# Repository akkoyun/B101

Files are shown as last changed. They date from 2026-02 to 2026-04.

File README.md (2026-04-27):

# B101BA-PCIe

**B101BA-PCIe** is a Mini PCI Express form-factor cellular modem card based on the **Telit LE910C1-EUX** 4G modem. This repository contains all Altium Designer project files, schematics, PCB layout, and generated outputs for review, manufacturing, and further development.

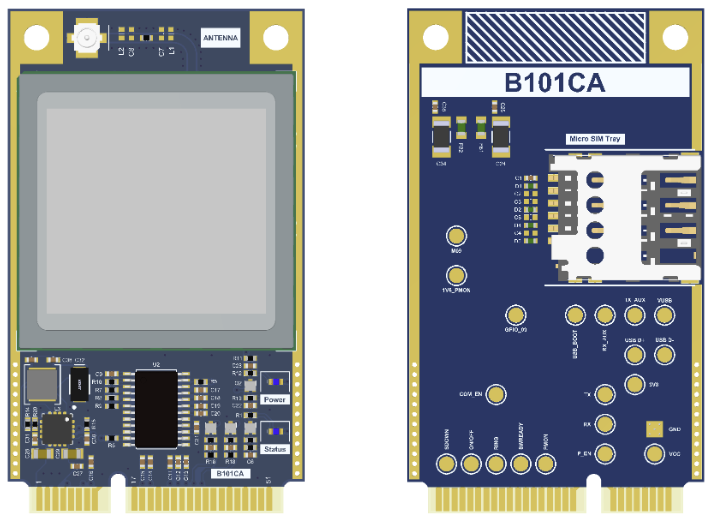
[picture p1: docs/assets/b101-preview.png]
B101BA-PCIe Board Preview


## Features

- Telit LE910C1-EUX LTE modem
- Mini PCIe edge connector (host interface)
- Dedicated 3.8V modem power rail (TPS62130)
- 1.8V ↔ 3.3V level translation (SN74AXC8T245)
- SIM card interface
- Cellular RF matching and antenna connection (IPEX/MHF)
- Exposed UART, USB, I2C, SPI, GPIO, analog pins
- Modem control signals: ON/OFF, shutdown, PWRMON, SWREADY, RING

## Block Diagram

- **Modem Core:** LE910C1-EUX, separated by function (power, UART, USB, GNSS, etc.)
- **Host Interface:** 52-pin Mini PCIe, multiple power/data/control lines
- **Power Supply:** 3.8V buck regulator, bulk capacitance for LTE current bursts
- **Voltage Translation:** Safe bridging between 1.8V (modem) and 3.3V (host)
- **Control Logic:** Discrete transistor-based ON/OFF and shutdown
- **RF Section:** Matching, controlled impedance, IPEX/MHF connector

## Repository Structure

| Path | Purpose |
|---|---|
| `B101BA.PrjPcb` | Main Altium project file |
| `B101BA.PcbDoc` | PCB layout document |
| `Schematics/` | Schematic source files |
| `B101BA.BomDoc` | Bill of materials document |
| `Job File.OutJob` | Output/fabrication generation settings  |
| `Output/` | Generated outputs (prints, manufacturing)|
| `History/` | Altium history/revision artifacts |
| `B101BA.PCBDwf` | PCB documentation/export artifact |

## Schematic Pages

- GSM IoT Block Diagram
- Card Edge Connector
- 3V8 Power Regulator
- Voltage Translator
- Control Signals
- GSM Antenna & Match Circuit
- Unused Modem Pins

## Typical Applications

- IoT gateways
- Industrial controllers
- Telemetry units
- Remote monitoring systems
- Any host system needing modular LTE connectivity

## Tooling

- Altium Designer (project editing)
- Gerber/CAM viewer (output review)
- PDF viewer (schematic prints)

## Version History

| Version | Date | Description |
|---|---|---|
| 00.00.01  | 2026-02-18 | Initial draft, basic schematic and PCB |
| 00.00.02  | 2026-02-26 | Design revision, bug fixes, DRC updates |
| 00.00.03  | 2026-04-23 | Post Design Review 01 updates, output refreshed  |

## Design Reviews & Documentation

- **Design Review 01:** Held on 2026-04-23. See `docs/Design Review 01/` for reviewed files and notes:
  - [BOM and review notes](docs/Design%20Review%2001/B101BA_00.00.01_BOM.csv)
  - [Design review presentation](docs/Design%20Review%2001/Telit%20Design%20Review%2001%20(Schematic%20%26%20PCB).pages)
- All manufacturing and review outputs: see `Output/` directory.

---

## Project Page

<https://www.akkoyun.net/acik-kaynak/B101BA-PCIe>

## License

A repository-level license file is not currently visible. If this project is intended to be openly reusable, please add a `LICENSE` file.

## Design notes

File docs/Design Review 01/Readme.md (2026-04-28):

# B100 / B101BA Modem Kartı Design Review Değerlendirme Raporu

**Doküman:** Telit Cinterion Design Review Report  
**Rapor No:** DR-35567 Rev 1  
**Tarih:** 2026-04-08  
**Modem:** Telit-Cinterion LE910C1-EUX  
**İncelenen Tasarım:** B101BA_00.00.01  
**Hazırlayan:** Mehmet Günce Akkoyun için teknik değerlendirme notu

---

## 1. Yönetici Özeti

Telit tarafından yapılan design review sonucunda kart genel olarak çalışabilir görünse de, özellikle **modem footprint hatası**, **reserved pin bağlantıları**, **seviye çevirici besleme tercihi**, **güç kesintisinde modem güvenli kapatma mekanizması** ve **yüksek manyetik alan ortamında bobin seçimi** konularında revizyon ihtiyacı vardır.

En kritik konu PCB layout tarafındadır: Telit, **modem footprint’inin yanlış olduğunu** belirtmiştir. Bu doğrudan üretilebilirlik, lehimleme güvenilirliği, modem oturumu ve uzun dönem saha güvenilirliği açısından **kritik hata** olarak ele alınmalıdır.

İkinci kritik konu, **K4 ve M6 pinlerinin reserved olması ve bağlanmaması gerektiğidir**. Bu pinlerin devrede herhangi bir nete bağlı olması ileride modem davranışı, sertifikasyon veya yeni modem revizyonları açısından risk oluşturabilir.

Üçüncü önemli konu ise **voltaj çevirici VCCB hattında VIO_1V8 yerine VAUX/PWRMON kullanılması önerisidir**. Telit bunu latch-up riskini azaltmak için önermiştir.

Bu rapora göre B100/B101BA modem kartı için revizyon yapılmadan seri üretime geçilmemelidir.

---

## 2. Telit Review Sonuç Özeti

| İnceleme Alanı | Durum | Yorum |
|---|---:|---|
| Power Supply | Warning + Tip | L3 bobini shielded olmalı, fast shutdown öneriliyor |
| SIM Pins | OK | SIM bağlantılarında problem görülmemiş |
| Digital Pins | Error + Warning | Reserved pin bağlantıları ve seviye çevirici besleme riski var |
| RF Aspects - Schematic | Warning | 33 pF RF/harmonik filtreleme kapasitörleri öneriliyor |
| Audio | N/A | Kullanılmıyor |
| PCB General Placement | Error | Modem footprint yanlış |
| Antenna Waveguide | OK | RF hattı 50 Ohm karakteristik empedansa uygun |
| RF Layout | OK | RF waveguide hesaplaması uygun |
| Audio Layout | N/A | Kullanılmıyor |

---

## 3. Kritik Bulgular

## 3.1 Modem Footprint Hatalı

**Seviye:** Kritik / Error  
**Alan:** PCB Layout  
**Telit yorumu:** Modemin footprint’i yanlış, doğru footprint şekli raporda verilmiş.

### Risk

Bu madde tasarımdaki en ciddi bulgudur. Footprint hatası aşağıdaki problemlere yol açabilir:

- Modemin PCB üzerine mekanik olarak hatalı oturması
- Pad hizalama problemleri
- Lehim köprüsü veya açık devre riski
- Reflow sonrası gizli lehim hataları
- Sahada titreşim/ısı döngüsü sonrası bağlantı kopmaları
- Üretim veriminin düşmesi
- Modem üretici tavsiyesine uyumsuzluk nedeniyle sertifikasyon veya onay sürecinde sorun

### Yapılacak İşlem

- Telit’in verdiği footprint çizimi referans alınarak mevcut footprint yeniden kontrol edilmeli.
- Library footprint’i güncellenmeli.
- Pad ölçüleri, keep-out/inhibit wiring bölgeleri, package outline ve mekanik hizalama tekrar çizilmeli.
- Güncellenmiş footprint ile PCB tekrar route edilmeli.
- Eski footprint kullanılan tüm projeler kontrol edilmeli.

### Öncelik

**P0 - Üretim öncesi mutlaka düzeltilmeli.**

---

## 3.2 K4 ve M6 Reserved Pinleri Bağlı Olmamalı

**Seviye:** Kritik / Error  
**Alan:** Schematic / Digital Pins  
**Telit yorumu:** K4 ve M6 pinleri reserved olup bağlanmamalıdır.

### Risk

Reserved pinlerin bağlanması şu riskleri doğurur:

- Modem iç yapısında bilinmeyen fonksiyonlara müdahale
- Farklı modem donanım revizyonlarında uyumsuzluk
- Sertifikasyon sırasında üretici tavsiyesine aykırı bağlantı
- Uyku/uyanma, boot, RF veya debug davranışlarında öngörülemeyen sorunlar
- Saha koşullarında rastgele modem kilitlenmesi veya kararsızlık

### Yapılacak İşlem

- K4 ve M6 pinleri şemada **NC** bırakılmalı.
- Bu pinlere bağlı net, test point, pull-up, pull-down veya başka bağlantı varsa kaldırılmalı.
- PCB üzerinde bu pinlerden çıkan izler silinmeli.
- ERC/DRC için bu pinler “Do Not Connect” olarak işaretlenmeli.

### Öncelik

**P0 - Mutlaka düzeltilmeli.**

---

## 3.3 Voltage Translator VCCB Hattında VIO_1V8 Yerine VAUX/PWRMON Kullanılmalı

**Seviye:** Warning  
**Alan:** Schematic / Communication Interfaces  
**Telit yorumu:** Module latch-up riskini önlemek için voltage translator’ın VCCB hattında VIO_1V8 yerine VAUX/PWRMON kullanılmalı.

### Teknik Değerlendirme

Bu uyarı önemlidir. Modem ile MCU veya başka dijital devreler arasında seviye çevirici kullanılıyorsa, modem kapalıyken veya power state geçişindeyken IO hatlarından modeme ters besleme gitmesi latch-up riskini artırabilir.

VAUX/PWRMON kullanımı, modem IO domain aktif olduğunda seviye çeviricinin de aktif olmasını sağlar. Böylece modem kapalıyken dış dünyadan IO pinleri üzerinden modem içine kaçak besleme verilmesi engellenir.

### Risk

- Modem latch-up
- Boot sırasında kararsız davranış
- Modem kapanmış görünürken IO üzerinden kısmi beslenme
- Akım tüketiminde anormal artış
- Modem reset ihtiyacı
- Uzun vadede modem hasarı

### Yapılacak İşlem

- Voltage translator VCCB hattı mevcutta VIO_1V8’e bağlıysa bağlantı revize edilmeli.
- VCCB, Telit önerisine uygun şekilde VAUX/PWRMON sinyalinden beslenmeli.
- Translator yön kontrolü, enable pini ve pull-up/pull-down yapısı tekrar kontrol edilmeli.
- Modem kapalıyken MCU tarafının modem IO hattına enerji basmadığı doğrulanmalı.
- Güç sıralaması test edilmeli.

### Test Önerisi

- Modem kapalı, MCU açık senaryosu
- MCU kapalı, modem açık senaryosu
- Her ikisi aynı anda açılıyor senaryosu
- Ani güç kesintisi sonrası tekrar açılma senaryosu
- Sleep/wakeup senaryosu

### Öncelik

**P1 - Revizyon kartında düzeltilmeli.**

---

## 3.4 L3 Bobini Shielded Tip ile Değiştirilmeli

**Seviye:** Warning  
**Alan:** Power Supply  
**Telit yorumu:** Uygulama yüksek manyetik alana yakın çalışacağı için L3 bobini shielded tip ile değiştirilmelidir.

### Teknik Değerlendirme

Kartın motor kontrol panosu, kontaktör, sürücü, soft starter, kompanzasyon ve yüksek akım hatlarına yakın çalışacağı düşünülürse bu uyarı doğru ve önemlidir. Açık tip bobinler harici manyetik alanlardan etkilenebilir, aynı zamanda kendileri de çevreye daha fazla EMI yayabilir.

Shielded indüktör kullanmak özellikle modem besleme hattında daha stabil davranış sağlar.

### Alternatif Shielded İndüktör Önerileri

    Not: L3 için kesin değer mevcut şemadaki regülatör topolojisine, switching frekansına, hedef çıkış akımına ve mevcut endüktans değerine göre netleştirilmelidir. Aşağıdaki tablo, modem besleme hattında kullanılabilecek **shielded power inductor** alternatiflerini kısa liste olarak verir. Seçim yapılırken mevcut L3 değeriyle aynı endüktans değeri, daha yüksek saturation current ve düşük DCR önceliklendirilmelidir.
 
| Üretici | Seri / Parça Ailesi | Örnek Parça | Paket | Avantaj | Not |
|---|---|---|---|---|---|
| Würth Elektronik | WE-PD / WE-LHMI | 7447709xxx / 744373xxxx | SMD shielded | Kolay bulunur, güçlü datasheet, endüstriyel kullanım için güvenilir | Avrupa tedarik zinciri ve prototip için iyi seçenek |
| Coilcraft | XAL / XFL / MSS | XAL40xx / XFL40xx / MSSxxxx | SMD shielded | Düşük DCR, yüksek saturation current, kaliteli manyetik yapı | Performans odaklı seçim için iyi ama maliyet daha yüksek olabilir |
| Bourns | SRN / SRP | SRN6045 / SRP5030 / SRP7030 | SMD semi-shielded / shielded | Yaygın bulunabilir, maliyet/performans dengesi iyi | SRP serisi daha güçlü shielded yapı için tercih edilebilir |
| TDK | SPM / VLS | SPM5030 / VLS6045 | SMD shielded | Kompakt, kaliteli, otomotiv/endüstriyel seçenekleri var | Stok ve fiyat kontrolü gerekli |
| Murata | LQH / DFE | DFE252012 / DFE322512 / LQHxx | SMD shielded | Kompakt tasarım, güvenilir marka | Yüksek akım gerekiyorsa paket boyutu dikkatli seçilmeli |
| Taiyo Yuden | NR / NRS | NR6045 / NRS6045 | SMD shielded | Uygun maliyetli, yaygın Asya tedariki | Seri üretim maliyeti için değerlendirilebilir |
| Sunlord | SWPA / WPN | SWPA6045 / SWPA7030 | SMD shielded | Çin tedarikinde ekonomik alternatif | Uzun dönem kalite ve sıcaklık performansı ayrıca doğrulanmalı |
| Chilisin / Yageo | SCDS / SLF / çeşitli power serileri | Değere göre seçilmeli | SMD shielded | Ekonomik ve bulunabilir alternatifler | Datasheet parametreleri dikkatli karşılaştırılmalı |

#### Seçim Kriterleri

- Mevcut L3 ile **aynı endüktans değeri** korunmalı.
- Saturation current değeri, modem TX burst ve regülatör peak current ihtiyacının üzerinde olmalı.
- RMS current değeri sürekli çalışma akımını güvenli karşılamalı.
- DCR düşük olmalı; aksi halde ısınma ve verim kaybı artar.
- Shielded yapı tercih edilmeli; semi-shielded parça ancak yer/maliyet zorunluluğu varsa düşünülmeli.
- Çalışma sıcaklığı en az **-40 °C / +85 °C**, tercihen **+105 °C** veya üzeri olmalı.
- Aynı footprint içinde ikinci kaynak alternatifi belirlenmeli.
- Prototipte modem TX anında bobin sıcaklığı, çıkış ripple ve voltaj çökmesi ölçülmeli.

#### Öncelikli Kısa Liste

| Öncelik | Öneri | Gerekçe |
|---:|---|---|
| 1 | Würth Elektronik WE-PD / WE-LHMI | Dokümantasyon, erişilebilirlik ve endüstriyel güvenilirlik açısından güçlü seçenek |
| 2 | Coilcraft XAL / XFL | Elektriksel performans ve düşük kayıp açısından güçlü seçenek |
| 3 | Bourns SRP serisi | Maliyet/performans dengesi iyi, yaygın bulunabilir |
| 4 | TDK SPM serisi | Kompakt ve kaliteli alternatif |
| 5 | Taiyo Yuden NR/NRS veya Sunlord SWPA | Seri üretimde maliyet optimizasyonu için değerlendirilebilir |

### Risk

- Bobin saturasyonu
- Regülatör çıkışında ripple artışı
- Modem TX burst sırasında voltaj çökmesi
- EMI/EMC problemleri
- RF performansında düşüş
- Saha koşullarında rastgele modem resetleri

### Yapılacak İşlem

- L3 mevcut parça numarası kontrol edilmeli.
- Aynı endüktans değerinde, uygun saturation current değerine sahip shielded indüktör seçilmeli.
- RMS current, saturation current, DCR ve sıcaklık yükselmesi kontrol edilmeli.
- Modem TX burst sırasında besleme hattı osiloskop ile izlenmeli.
- EMI açısından yakın alan probu ile karşılaştırmalı test yapılmalı.

### Öncelik

**P1 - Saha güvenilirliği için düzeltilmeli.**

---

## 3.5 Fast Shutdown Özelliği Eklenmeli

**Seviye:** Tip / Strong Recommendation  
**Alan:** Power Supply  
**Telit yorumu:** Ani güç kesintisi ihtimali olan sistemlerde modem memory corruption riskini önlemek için fast-shutdown özelliği uygulanmalı.

### Teknik Değerlendirme

Bu cihaz saha koşullarında motor panosunda çalışacağı için ani enerji kesintisi, kontaktör kaynaklı düşümler, pano içi bakım sırasında kapatma veya akü/hat dalgalanması gibi durumlar beklenebilir.

Modemin dosya sistemi, NVM alanı veya internal memory yapısı ani enerji kesintilerinden etkilenebilir. Bu nedenle fast shutdown mekanizması özellikle endüstriyel IoT uygulamalarında ihmal edilmemelidir.

### Risk

- Modem memory corruption
- SIM/network registration problemleri
- Modem boot loop
- FOTA veya konfigürasyon verisi bozulması
- Sahada cihazın bağlantısız kalması

### Yapılacak İşlem

- Telit LE910C1-EUX Hardware User Guide içindeki FAST_SHUTDOWN bölümü incelenmeli.
- Modem ON/OFF, RESET, PWRMON ve fast shutdown ilişkisi netleştirilmeli.
- Ana besleme düşüşü algılanacaksa MCU veya supervisor üzerinden shutdown tetiklenmeli.
- Yeterli hold-up kapasitesi veya batarya/power-path desteği ile modem shutdown süresi garanti edilmeli.
- Firmware tarafında “power fail detected” event’i oluşturulmalı.

### Öncelik

**P1 - Endüstriyel saha ürünü için uygulanması güçlü şekilde önerilir.**

---

## 3.6 RF/Harmonik Filtreleme İçin 33 pF Kapasitör Footprintleri Eklenmeli

**Seviye:** Warning  
**Alan:** RF Aspects / Schematic  
**Telit yorumu:** Harmoniklerden kaçınmak için modem kartında ve yakındaki kartlarda belirli noktalara GND’ye 33 pF kapasitörler konumlandırılması öneriliyor.

### Telit’in Önerdiği Filtreleme Noktaları

- Input/output connector üzerindeki power source ve sinyal hatları
- Power supply output pad’leri
- Komponentlerin power supply input pad’leri
- LED gibi forward conduction çalışan diyotların anot/katot hatları
- Transistor base hatları
- Phototransistor ve opto-isolator giriş/çıkış hatları

### Teknik Değerlendirme

Telit burada doğrudan EMI/RF harmonik bastırma amacıyla küçük değerli COG/NPO kapasitör öneriyor. 33 pF değeri özellikle 0402/0603 paketlerde yaklaşık 1 GHz civarında self-resonance davranışı nedeniyle önerilmiş. 0201 paketlerde ise 10–20 pF değerlerin 1 GHz civarına daha uygun olduğu belirtilmiş.

Burada kritik nokta şu: Bu kapasitörler rastgele her hatta takılmamalı; sinyal bütünlüğü, rise time, UART/SPI/I2C hızları, open-drain yapılar ve sürücü empedansları dikkate alınmalı. Ama PCB üzerinde opsiyonel footprint bırakmak doğru yaklaşımdır.

### Yapılacak İşlem

- Kritik hatlara opsiyonel “DNP” 33 pF COG/NPO kapasitör footprintleri eklenmeli.
- Kapasitörler filtrelenecek component pad’ine çok yakın yerleştirilmeli.
- Aynı path ve aynı layer üzerinde konumlandırılmalı.
- GND dönüş yolu kısa ve düşük empedanslı olmalı.
- High-speed veya timing-critical hatlarda kapasitör değeri testle doğrulanmalı.
- 0402/0603 için 33 pF, 0201 için 10–20 pF opsiyonları değerlendirilmeli.

### Öncelik

**P2 - EMC/sertifikasyon hazırlığı için önerilir.**

---

## 3.7 SIM Hatları Uygun

**Seviye:** OK  
**Alan:** SIM Pins  
**Telit yorumu:** SIM pin bağlantıları uygun.

### Teknik Değerlendirme

Telit SIM tarafında hata belirtmemiştir. Buna rağmen üretim öncesi şu kontroller yapılmalıdır:

- SIM ESD koruması
- SIM hat uzunlukları
- SIM clock hattı yakınındaki agresif sinyaller
- SIM kart soketi mekanik dayanımı
- SIM detect kullanılıyorsa logic seviyesi
- GND referans sürekliliği

### Öncelik

**P3 - Mevcut yapı korunabilir, üretim öncesi rutin kontrol yeterli.**

---

## 3.8 RF Waveguide 50 Ohm Uygun

**Seviye:** OK  
**Alan:** RF Layout  
**Telit yorumu:** RF waveguide required 50 Ohm characteristic impedance değerine uygun.

### Teknik Değerlendirme

RF hattı açısından önemli bir olumlu bulgudur. Telit’in RF waveguide hesaplamasında 50 Ohm empedans uygun görülmüş. Bu nedenle RF hattının genişlik/boşluk/stack-up yapısı korunmalıdır.

### Yapılacak İşlem

- RF hattı revizyon sırasında değiştirilmemeli.
- Footprint düzeltmesi RF hattını etkiliyorsa empedans yeniden hesaplanmalı.
- Üreticiye stack-up net verilmeli.
- RF hattında solder mask, via geçişleri ve ground stitching korunmalı.
- Anten konnektörü çevresindeki GND yapısı bozulmamalı.

### Öncelik

**P3 - Mevcut yapı korunmalı.**

---

# 4. Revizyon İçin Yapılacaklar Listesi

## 4.1 P0 - Kritik / Üretim Öncesi Zorunlu

- [ ] LE910C1-EUX modem footprint’i Telit’in önerdiği footprint’e göre yeniden çizilecek.
- [ ] Mevcut PCB’de modem footprint pad ölçüleri, package outline ve keep-out/inhibit wiring bölgeleri kontrol edilecek.
- [ ] Revize PCB üretime gitmeden önce Telit footprint çizimiyle birebir karşılaştırılacak.

---

## 4.2 P1 - Güvenilirlik İçin Güçlü Revizyon Önerileri

- [ ] Modem kapalıyken MCU tarafından IO hatları üzerinden modeme ters besleme gitmediği doğrulanacak.
- [ ] L3 bobini shielded tip indüktör ile değiştirilecek.
- [ ] Yeni L3 için saturation current, RMS current, DCR ve sıcaklık değerleri kontrol edilecek.
- [ ] Fast shutdown özelliği Telit Hardware User Guide’a göre incelenecek.
- [ ] Ani güç kesintisi senaryosu için modem güvenli kapanma akışı tasarlanacak.
- [ ] Hold-up süresi için bulk capacitor / batarya / power-path yeterliliği hesaplanacak.
- [ ] Power fail algılama ve modem shutdown firmware akışı tasarlanacak.
- [ ] L3 bobini shielded tip indüktör ile değiştirilecek.
- [ ] Yeni L3 için saturation current, RMS current, DCR ve sıcaklık değerleri kontrol edilecek.
- [ ] L3 için Würth, Coilcraft, Bourns, TDK ve ekonomik seri üretim alternatifleri içinden en az iki pin-to-pin uyumlu kaynak belirlenecek.

---

## 4.3 P2 - EMC / Sertifikasyon Hazırlığı

- [ ] Power source giriş/çıkış hatlarına opsiyonel 33 pF COG/NPO kapasitör footprintleri eklenecek.
- [ ] Input/output connector sinyal hatlarına opsiyonel RF filtre kapasitör footprintleri eklenecek.
- [ ] Power supply output pad’lerine yakın 33 pF opsiyonları değerlendirilecek.
- [ ] LED D6 anot/katot hattı için opsiyonel 33 pF filtre footprint’i eklenecek.
- [ ] Transistor base hatlarına opsiyonel 33 pF filtre footprint’i eklenecek.
- [ ] Opto-isolator ve phototransistor hatları varsa opsiyonel filtre footprintleri eklenecek.
- [ ] 0402/0603 için 33 pF, 0201 için 10–20 pF alternatifleri BOM opsiyonuna eklenecek.
- [ ] Bu kapasitörler varsayılan olarak DNP bırakılacak, EMC testine göre takılacak.

---

# 5. Test Planı

## 5.1 Power Testleri

- [ ] Modem TX burst sırasında modem beslemesi osiloskop ile ölçülecek.
- [ ] Ani enerji kesintisi testi yapılacak.
- [ ] Fast shutdown tetiklenme testi yapılacak.
- [ ] Modem açık/kapalı power sequencing testi yapılacak.
- [ ] MCU açık, modem kapalı senaryosunda IO leakage ölçülecek.
- [ ] Modem açık, MCU kapalı senaryosunda IO leakage ölçülecek.

---

## 5.2 Digital Interface Testleri

- [ ] UART/SPI/I2C hangi arayüz kullanılıyorsa logic analyzer ile kontrol edilecek.
- [ ] Voltage translator VCCB değişimi sonrası haberleşme stabilitesi test edilecek.
- [ ] Sleep/wakeup sonrası haberleşme tekrar başlıyor mu kontrol edilecek.
- [ ] Power cycle sonrası modem kararlı boot ediyor mu kontrol edilecek.

---

## 5.3 RF Testleri

- [ ] Anten bağlantısı sonrası RSSI/RSRP/RSRQ/SINR değerleri ölçülecek.
- [ ] RF hattı revizyon sonrası VNA ile mümkünse kontrol edilecek.
- [ ] Yakın alan EMI taraması yapılacak.
- [ ] 33 pF DNP kapasitörlerin EMC testinde etkisi karşılaştırılacak.
- [ ] Modem TX sırasında yakındaki dijital hatlarda parazit gözlemlenecek.

---

## 5.4 Üretim Testleri

- [ ] Modem footprint revizyonundan sonra ilk PCB’de X-ray veya mikroskop kontrolü yapılacak.
- [ ] Reflow sonrası modem pad lehim kalitesi kontrol edilecek.
- [ ] Reserved pinlerin gerçekten bağlantısız olduğu netlist üzerinden doğrulanacak.
- [ ] RF hattı continuity ve short kontrolü yapılacak.
- [ ] SIM kart algılama ve network registration testi yapılacak.

---

# 6. Revizyon Notları

## 6.1 Schematic Revizyon Notları

| Madde | Aksiyon |
|---|---|
| K4 / M6 | NC yapılacak |
| VCCB | VIO_1V8 yerine VAUX/PWRMON |
| Fast shutdown | Telit HUG’a göre eklenecek |
| L3 | Shielded indüktör ile değiştirilecek; Würth / Coilcraft / Bourns / TDK ve seri üretim alternatifi karşılaştırılacak |
| 33 pF filtreler | Kritik hatlara DNP footprint olarak eklenecek |

---

## 6.2 PCB Revizyon Notları

| Madde | Aksiyon |
|---|---|
| Modem footprint | Telit önerisine göre düzeltilecek |
| RF line | 50 Ohm yapı korunacak |
| GND stitching | RF hattında korunacak |
| 33 pF filtreler | Pad’e çok yakın yerleştirilecek |
| Keep-out alanları | Telit footprint’e göre yeniden kontrol edilecek |

---

# 7. Mühendislik Yorumu

Telit’in raporu kısa ama kritik maddeler içeriyor. En önemli nokta, review sonucunda RF hattının 50 Ohm olarak uygun bulunması ve SIM tarafında problem görülmemesidir. Bu iyi haber.

Ancak modem footprint hatası ciddi bir konu. Bu hata düzeltilmeden PCB üretimine devam etmek doğru olmaz. Eğer mevcut karttan prototip üretildiyse, bu kartlar sadece sınırlı fonksiyon testi için kullanılmalı; saha pilotu veya seri üretim adayı olarak değerlendirilmemelidir.

Reserved pinlerin bağlı olması da hafife alınmamalı. Bugün çalışıyor gibi görünse bile modem üreticisi bu pinleri ileride farklı amaçla kullanabilir veya pin iç yapısı revizyonla değişebilir. Endüstriyel sahada çalışacak bir modem kartında bu tür belirsizlik kabul edilmemelidir.

Voltage translator beslemesiyle ilgili öneri de sahada rastgele modem kilitlenmelerini önlemek açısından önemlidir. Bu tarz latch-up problemleri laboratuvarda kolay yakalanmaz; asıl problem sahada, özellikle motor panosu gibi gürültülü ortamlarda ortaya çıkar.

Sonuç olarak bu design review, kartın tamamen kötü olduğunu göstermiyor; fakat seri üretim öncesi mutlaka yapılması gereken birkaç net düzeltme olduğunu gösteriyor.

---

# 8. Kapanış Kararı

Bu kart için önerilen karar:

**Revizyon gerekli. Mevcut tasarım doğrudan seri üretime çıkarılmamalı.**

Revizyon sonrası aşağıdaki üç kontrol tamamlanmadan üretim onayı verilmemelidir:

1. Telit footprint uyumluluk kontrolü
2. Reserved pinlerin tamamen NC doğrulaması
3. Power sequencing / latch-up / fast shutdown testleri

Bu üç madde kapatıldıktan sonra kart, saha pilotu için yeniden değerlendirilebilir.
# B100 / B101BA Modem Kartı Design Review Revizyon Raporu

**Kaynak Doküman:** Telit Cinterion Design Review Report  
**Rapor No:** DR-35567 Rev 1  
**Tarih:** 2026-04-08  
**Modem:** Telit-Cinterion LE910C1-EUX  
**Tasarım:** B101BA_00.00.01  
**Kapsam:** Telit design review bulguları, yapılan düzeltmeler ve açık kalan doğrulama adımları

---

## 1. Yönetici Özeti

Telit tarafından yapılan design review sonucunda B100 / B101BA modem kartı için birkaç kritik düzeltme önerilmiştir. Review’de öne çıkan başlıklar şunlardır:

- Modem footprint’inin Telit önerisiyle uyumlu hale getirilmesi
- K4 ve M6 reserved pinlerinin bağlantısız bırakılması
- Voltage translator beslemesinde VIO_1V8 yerine PWRMON/VAUX kullanılması
- L3 indüktörün shielded/kalkanlı olduğunun netleştirilmesi
- Ani güç kesintisi senaryosu için fast shutdown mekanizmasının değerlendirilmesi
- RF/harmonik bastırma için opsiyonel 33 pF filtre kapasitörlerinin değerlendirilmesi

İlk revizyon çalışması kapsamında kritik donanım maddeleri kapatılmıştır. Kart artık doğrudan “hatalı tasarım” durumundan çıkmış, **revizyon sonrası doğrulama/test aşamasına** geçmiştir.

Seri üretim kararı verilmeden önce güç sıralaması, IO leakage, modem TX burst besleme stabilitesi ve temel RF/EMC davranışı doğrulanmalıdır.

---

## 2. Telit Bulguları ve Yapılan İşlemler

| No | Telit Bulgusu | Öncelik | Yapılan İşlem | Durum |
|---:|---|---|---|---|
| 1 | Modem footprint hatalı | P0 | LE910C1-EUX footprint’i Telit önerisine göre düzeltildi | Tamamlandı |
| 2 | K4 ve M6 pinleri reserved, bağlanmamalı | P0 | K4 ve M6 pinleri NC hale getirildi | Tamamlandı |
| 3 | Voltage translator VCCB hattında VIO_1V8 yerine PWRMON/VAUX kullanılmalı | P1 | 1V8 besleme kaldırılarak PWRMON/VAUX besleme yapıldı | Tamamlandı |
| 4 | L3 yüksek manyetik alan için shielded olmalı | P1 | L3’ün shielded/kalkanlı olduğu şematikte netleştirildi | Tamamlandı |
| 5 | Ani güç kesintisi için fast shutdown öneriliyor | P1 | Donanım/firmware akışı ayrıca değerlendirilecek | Açık |
| 6 | RF/harmonik azaltma için 33 pF filtreler öneriliyor | P2 | Opsiyonel DNP filtre footprintleri değerlendirilecek | Açık / Opsiyonel |
| 7 | SIM pinleri | P3 | Telit tarafından uygun bulundu | OK |
| 8 | RF waveguide 50 Ohm | P3 | Telit tarafından uygun bulundu; yapı korunacak | OK |

---

## 3. Kapatılan Kritik Maddeler

### 3.1 Modem Footprint Düzeltmesi

Telit, PCB layout incelemesinde modem footprint’inin doğru olmadığını belirtmiştir. Bu madde üretilebilirlik, lehim kalitesi ve saha güvenilirliği açısından en kritik bulgudur.

**Yapılan işlem:**

- LE910C1-EUX modem footprint’i Telit önerisine göre güncellendi.
- Pad geometrileri ve mekanik yerleşim kontrol edildi.
- Yeni footprint’e göre PCB yerleşimi revize edildi.

**Durum:** Tamamlandı.

---

### 3.2 Reserved Pin Düzeltmesi

Telit, K4 ve M6 pinlerinin reserved olduğunu ve bağlanmaması gerektiğini belirtmiştir.

**Yapılan işlem:**

- K4 pini NC hale getirildi.
- M6 pini NC hale getirildi.
- Reserved pinlerin sinyal, test point, pull-up veya pull-down bağlantısı olmaması sağlandı.

**Durum:** Tamamlandı.

---

### 3.3 Voltage Translator Besleme Revizyonu

Telit, latch-up riskini azaltmak için voltage translator VCCB hattının VIO_1V8 yerine PWRMON/VAUX ile beslenmesini önermiştir.

**Yapılan işlem:**

- VCCB hattındaki 1V8 besleme kaldırıldı.
- Voltage translator beslemesi PWRMON/VAUX yapısına alındı.

**Beklenen fayda:**

- Modem kapalıyken IO hatlarından ters besleme riski azalır.
- Modem power state ile dijital arayüz seviyesi daha uyumlu hale gelir.
- Latch-up riski düşer.

**Durum:** Tamamlandı.

---

### 3.4 L3 İndüktör / Shielded Bilgisi

Telit, uygulamanın yüksek manyetik alana yakın çalışacağı gerekçesiyle L3 indüktörün shielded tip olmasını önermiştir.

Mevcut L3 parçası:

```text
Murata LQH3NPN2R2MMEL
2.2 µH
Shielded / Magnetic Resin Shielded
```

**Yapılan işlem:**

- L3’ün shielded/kalkanlı olduğu şematik üzerinde açık şekilde belirtildi.
- BOM açıklamasında shielded power inductor bilgisi netleştirildi.

**Mühendislik notu:**

Mevcut parça shielded olsa da modem besleme hattı için daha yüksek akım kapasiteli ve daha düşük DCR değerine sahip alternatifler ileride değerlendirilebilir. Bu değişiklik zorunlu değil; daha çok saha güvenilirliği ve EMI dayanımı için iyileştirme adayıdır.

Önerilen alternatif kısa liste:

| Öncelik | Parça | Değer | Not |
|---:|---|---:|---|
| 1 | Bourns SRP5030TA-2R2M | 2.2 µH | Fiyat/kalite dengesi iyi, daha yüksek akım kapasitesi |
| 2 | Würth 74437346022 | 2.2 µH | Daha güçlü ve düşük DCR’li seçenek |
| 3 | Coilcraft XEL4030-222MEC | 2.2 µH | Performans odaklı alternatif |

**Durum:** Şematik açıklama düzeltmesi tamamlandı. Alternatif komponent geçişi opsiyonel iyileştirme olarak bırakıldı.

---

## 4. Açık Kalan Maddeler

### 4.1 Fast Shutdown Değerlendirmesi

Telit, ani güç kesintisi olan sistemlerde modem memory corruption riskini azaltmak için fast shutdown özelliğinin değerlendirilmesini önermiştir.

Bu konu henüz kapatılmamıştır.

**Yapılacaklar:**

- Telit LE910C1-EUX Hardware User Guide içindeki FAST_SHUTDOWN bölümü incelenecek.
- Ani güç kesintisinde modem güvenli kapanma akışı belirlenecek.
- Gerekirse MCU/supervisor üzerinden power fail algılama ve shutdown tetikleme yapısı tasarlanacak.
- Hold-up kapasitesi veya batarya/power-path süresi yeterlilik açısından değerlendirilecek.

---

### 4.2 Opsiyonel 33 pF RF/Harmonik Filtreleri

Telit, harmonik bastırma için bazı güç ve sinyal hatlarında GND’ye 33 pF kapasitör footprintleri bırakılmasını önermiştir.

Bu konu EMC hazırlığı için faydalıdır; ancak tüm hatlara kontrolsüz uygulanmamalıdır.

**Yapılacaklar:**

- Kritik güç ve IO hatları belirlenecek.
- Gerekli görülen noktalara DNP 33 pF COG/NPO footprint bırakılacak.
- EMC test sonucuna göre bu kapasitörler takılacak veya boş bırakılacak.

---

## 5. Güncel Karar

Revizyon sonrası Telit design review’de belirtilen ana kritik maddeler kapatılmıştır.

**Kapatılan başlıca maddeler:**

1. Modem footprint düzeltildi.
2. K4 ve M6 reserved pinleri NC hale getirildi.
3. Voltage translator beslemesi PWRMON/VAUX yapısına alındı.
4. L3’ün shielded/kalkanlı olduğu şematik üzerinde netleştirildi.

Bu aşamada kart, **revize prototip üretim ve doğrulama testleri** için uygundur.

Seri üretim kararı ise ancak aşağıdaki testlerden sonra verilmelidir:

- Power sequencing testi
- IO leakage testi
- Modem TX burst besleme testi
- SIM/network registration testi
- Temel RF/EMI gözlemi

---

## 6. Sonuç

Telit review sonucunda ortaya çıkan kritik tasarım riskleri büyük ölçüde giderilmiştir. Mevcut durumda ana risk artık şematik/PCB hatasından çok, revizyon sonrası doğrulama testlerinin tamamlanmasıdır.

Bu nedenle önerilen karar:

```text
Revize tasarım prototip üretime alınabilir.
Seri üretim kararı, doğrulama testleri tamamlandıktan sonra verilmelidir.
```

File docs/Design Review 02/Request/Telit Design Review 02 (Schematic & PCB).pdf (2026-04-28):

### Application Engineering

Design Review request form

Code : ________
Rev : ________
Date : 28.04.2026
Page : 1/13

# Design Review request form

DISCLAIMER

The contents are confidential and any disclosure to persons other than the officers, employees, agents or subcontractors of the owner or licensee of this document, without the prior written consent of Telit, is strictly prohibited. Telit makes every effort to ensure the quality of the information it makes available. Notwithstanding the foregoing, Telit does not make any warranty as to the information contained herein, and does not accept any liability for any injury, loss or damage of any kind incurred by use of or reliance upon the information.

Telit disclaims any and all responsibility for the application of the devices characterized in this document, and notes that the application of the device must comply with the safety standards of the applicable country, and where applicable, with the relevant wiring rules.

© Telit Communications PLC

Company: | Ovoo Electronics
Author: | Mr. Mehmet Günce Akkoyun

The electronic version of this document is the latest version. It is the responsibility of the individual to ensure that any paper material is the current version. Printed material is uncontrolled documentation – Internal use only Mod.0363 12-2016 Rev.6

Date : 28.04.2026
Page : 2/13

Contents

1. Scope | 3
2. InstructIons | 3
3. Customer information | 4
4. General information | 4
5. General Vıew | 5
6. LocatIon, AmbIent, CondItIons | 6
7. Bands of OperatIon | 7
8. Approvals RequIred | 8
9. AddItIonal RadIos | 8
10.GNSS | 9
11.Antennas | 9
12.Power | 9
13.SIM | 9
14.Module Control | 10
15.DOCUMENTATION FILES TABLE | 10
Desc. | 12
16.CHANGE LOG | 13

Date : 28.04.2026
Page : 3/13

### 1. SCOPE

Aim of this document is to collect basic information on the customer application that will help the Telit Design Review team in having a clear understanding of the application constraints and requirements of the whole application environment. This information together with the information provided for the Design Review (Schematic, PCB Gerber, PCB layup) will assist Telit Design Review team in providing customer with a tailored Design Review Report.

### 2. INSTRUCTIONS

Please fill this document in all the parts either checking the options or adding text description. For your convenience we repeat here the list of files required for a complete Design Review.

Please check the correctness of the documents before sending.

We need the following information:

1. Schematic files:
1.1. PDF with searchable names of components and signals.
1.2. Part name and description or BOM file.
2. CAD files:
2.1. Gerber files in format RS247X
2.2. Drill files in excellon format with preferred separate files for plated and non plated vias.
2.3. Netlist file in format IPC-356A.
2.4. PCB layout description with copper and dielectric width, dielectric constant.
2.5. PCB stack-up, description and gerber filename correspondences organized from top to bottom: layers, silkscreens, pastes and solder masks.
2.6. In alternative to gerbers files, the full single ODB++ zip file.

In order to speed up the Design Review for subsequent DR revisions:

The subsequent design review revisions requests must come with a change log description and Review ID.

Date : 28.04.2026
Page : 4/13

### 3. CUSTOMER İNFORMATİON

### 4. GENERAL İNFORMATİON

Company name : | Ovoo Electronics
Country : | Turkey
Address : | Şeker Mah. Ayyıldız Sok. Silverstar Apt. No:7/7 42050 Karatay / Konya
Contact Name : | Mehmet Günce Akkoyun
Contact e-mail : | akkoyun@me.com
Application name : | B101CA Rev 00.00.03 : qSlot / PCIe Form Factor GSM Modem Module
Telit module integrated in the application : | LE910C1-EUX
Field of application : | Smart agriculture and industrial power monitoring systems.
Installation description : | Module is installed in electricity boxes for measuring electric parameters.
Other radio device integrated in the application : | -
Other useful information : | The application uses an external cellular antenna connected directly to the onboard RF connector. The board is powered from a single-cell Li-Ion battery / system power rail. The module is intended for outdoor electrical panel installations used in smart agriculture and industrial power telemetry systems. This submission is a second design review request after Telit DR-35567 Rev 1. The schematic and PCB layout have been revised according to the findings in the first review.
Design Review already done on this application | Yes
Previous Design Review ID | DR-35567 Rev 1
Non Disclosure Agreement Signed : | Yes

Date : 28.04.2026
Page : 5/13

### 5. GENERAL VIEW

Scope of operation – main purpose of product

- Asset Tracking
- Automated Meter Reading / Management
- Automotive - Car Makers & Tier1 Supplier
- Fleet Management - Tolling - PAYD
- GSM Gateway
- GSM Railway
X | Industrial Automation
- Information & Displays
- Mobile Computing
- Navigation
- POS - Point Of Sales Terminals
- Public Transportation
- Security - Alarm - Surveillance
- Sub-System & Terminals based on Telit modules
- Telemedicine / Medical
X | Telemetry
- Telephony
- V24 to GPS converter
- Vending
- Wearable Electronics
X | Other : Electrical parameter measurement and telemetry.

Date : 28.04.2026
Page : 6/13

### 6. LOCATION, AMBIENT, CONDITIONS

Location :

- Indoor
X | Outdoor
- Automotive
X | Other : In electric box at outdoor.

Ambient :

X | Countryside
- Urban

Conditions :

- Explosive Atmosphere
X | Extreme Conditions (specify) : Outdoor electrical control panels, typically installed in agricultural irrigation and industrial power monitoring applications. The product may operate near transformers, contactors, motor starters, VFDs, compensation panels and high-current power cables. High electromagnetic and magnetic field exposure is possible.

Installations :

X | Fixed
- Mobile
- Portable

Date : 28.04.2026
Page : 7/13

### 7. BANDS OF OPERATION

Required Bands :

- CDMA 450
- CDMA 800
- CDMA 1900
- GSM 850/1900
X | GSM 900/1800
- UMTS B1
- UMTS B2
- UMTS B3
- UMTS B4
- UMTS B5
- UMTS B8
X | LTE I (2100)
X | LTE II (1900)
X | LTE III (1800)
X | LTE IV (1700-2100)
X | LTE V (850)
X | LTE VII (2600)
X | LTE XIII (700)
X | LTE XX (800)
X | Others : All operators in Turkey and all 2G and 4G compatible countries.

Date : 28.04.2026
Page : 8/13

### 8. APPROVALS REQUIRED

### 9. ADDITIONAL RADIOS

Regulatory Approvals :

X | CE Mark
X | GCF
X | FCC/IC
X | PTCRB
- Other : _________________________

Carrier Approvals :

- AT&T
- Verizon
- Vodafone
X | Other : All operators in Turkey

Other Approvals :

- ATEX/IECEx (specify) : _________________________
- Other : ________________________

Additional Radio Technology :

- WiFi
- GPS
- Bluetooth / BLE
- Short Range (specify) ________________________

Coexistence Management :

- None
- No Simultaneous Operation
- Other : _____________________________

Date : 28.04.2026
Page : 9/13

10.GNSS

11.ANTENNAS

12.POWER

13.SIM

- GPS
- GLONASS
- Galileo
- QZSS
- Beidou
- Other : __________________________
- Embedded
- Internal
X | External, Placed directly on connector or close to application
- External, Connected with long coax cable and placed away
- GNSS antenna passive
- GNSS antenna active
Type of power supply / battery (specify) | Single-cell Li-Ion / LiPo battery powered system. Nominal battery voltage: 3.7 V Battery operating range: approximately 3.0 V to 4.2 V Planned capacity: 2000 mAh or higher The modem power rail is generated on board. Power sequencing and PWRMON/VAUX controlled level translation were revised after DR-35567 Rev 1.
Modem RTC hold time requirement (specify) | Internal (there is no RTC backup need for modem)
X | Standard SIM Holder
- Standard SIM Holder / SIM on Chip Mount Alternative
- SIM on Chip Only
- Dual SIM
- Telit IoT Connectivity
- SimWise (SIM profile embedded in Module)

Date : 28.04.2026
Page : 10/13

14.MODULE CONTROL

15.DOCUMENTATION FILES TABLE

- Embedded Telit Python Script
- Embedded Telit IoT AppZone
X | External Microcontroller or Interface

Schematic Files

File Type | File Name | Format | Note
Schematic | B101CA_00.00.03_Schematic.PDF | PDF
BOM | B101CA_00.00.03_BOM.CSV | PDF or Excel
Custom Components Datasheet | | PDF | Antennas, custom components etc.

PCB Stack-up [4 Layer]

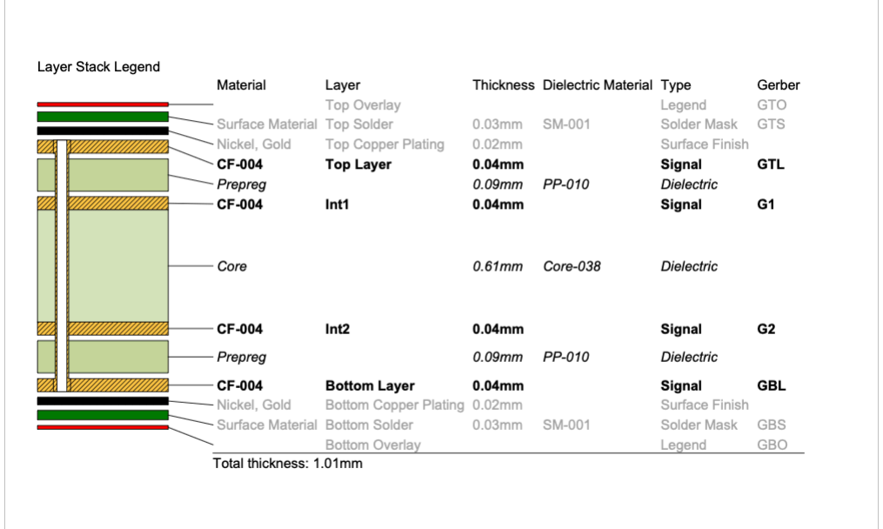
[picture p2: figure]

Date : 28.04.2026
Page : 11/13

PCB Extra Files

File Type | File Name | Format | From Layer | To Layer

Silkscreen Top

Paste Mask Top

Solder Mask Top

Copper 1 [Top]

Dielectric 1

Copper 2 [Inner 1]

Dielectric 2

Copper 3 [Inner 2]

Dielectric 3

Copper 4 [Bottom]

Solder Mask Bottom

Paste Mask Bottom

Silkscreen Bottom

Date : 28.04.2026
Page : 12/13

DESC.

- This is a second design review request for the revised B101-BA modem board.

The previous Telit design review report was DR-35567 Rev 1. The design has been updated according to the findings in that report.

Summary of implemented changes:

1. The LE910C1-EUX modem footprint was corrected according to the Telit recommended footprint.
2. Reserved pins K4 and M6 were disconnected and marked as NC.
3. The voltage translator VCCB supply was changed from VIO_1V8 to PWRMON/VAUX to reduce latch-up risk.
4. L3 inductor information was clarified in the schematic as a shielded / magnetic-resin-shielded power inductor.
5. The RF 50 Ohm waveguide structure was preserved.
6. SIM interface design was preserved because it was marked OK in the previous review.

Open / under evaluation:

1. Fast shutdown implementation is under evaluation. Required hold-up time, power-fail detection and firmware shutdown sequence are being reviewed.
2. Optional 33 pF COG/NPO DNP filter capacitor footprints for RF/harmonic suppression are under evaluation for EMC preparation.

The PCIe card-edge form factor is used only for mechanical integration. The electrical pinout is custom and belongs to our qSlot interface. It is not intended to be PCIe compatible. Detail : https://www.akkoyun.net/acik-kaynak/qslot (https://www.akkoyun.net/acik-kaynak/qslot)

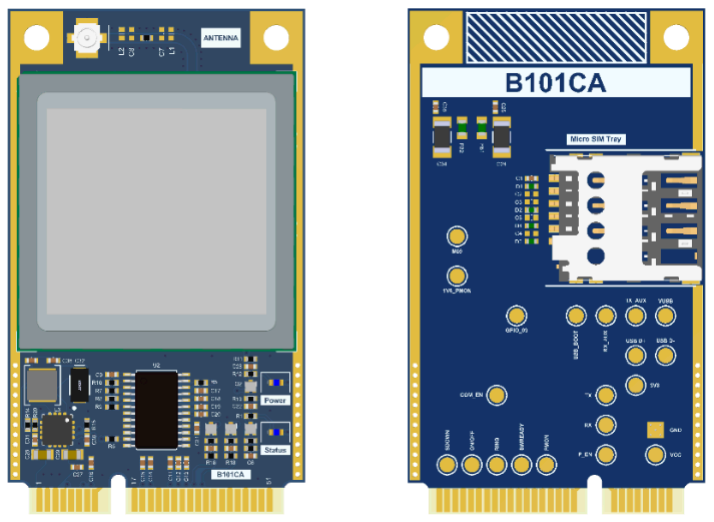
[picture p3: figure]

Date : 28.04.2026
Page : 13/13

16.CHANGE LOG

Change Log

Revision | Description
00.00.01 | First design submitted for Telit design review.

00.00.03

Second design review submission after Telit DR-35567 Rev 1.

Implemented changes:

- Corrected LE910C1-EUX modem footprint according to Telit recommended footprint.
- Disconnected reserved pins K4 and M6; both pins are now NC.
- Changed voltage translator VCCB supply from VIO_1V8 to PWRMON/VAUX.
- Clarified L3 as shielded / magnetic-resin-shielded 2.2 µH inductor in schematic and BOM.
- Preserved the 50 Ohm RF waveguide, previously marked OK.
- Preserved SIM interface, previously marked OK.
- Updated schematic, PCB layout, BOM and Gerber files for Rev 00.00.03.

Open items:

- Fast shutdown feature is under evaluation.
- Optional 33 pF DNP RF/harmonic filter capacitor footprints are under evaluation.

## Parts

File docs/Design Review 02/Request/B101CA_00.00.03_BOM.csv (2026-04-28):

Description | Designator | Quantity | Manufacturer Name | Manufacturer Part Number | Case
Multilayer Ceramic Capacitors - SMD - 6.3V 1uF X5R 0402 20% | C1 | 1 | Murata | GRM153R60J105ME95D | 0402
Capacitor - 33pF [0402] (Ceramic) | C6, C11, C12, C13, C14, C15, C16, C17, C18, C19, C20, C21, C22, C23, C25, C30, C35, C36, C37, C38 | 20 | Kemet | C0402C330J9RACAUTO | 0402
Capacitor - 100nF [0402-6V3] (Ceramic) | C9, C33 | 2 | AVX | 04026D104KAT4A | 0402
Multilayer Ceramic Capacitors MLCC - SMD/SMT 47UF 10V 20% 1206 | C24 | 1 | Kemet | C1206C476M8PAC | 1206
Multilayer Ceramic Capacitors - SMD - 25V 1uF X7R 0603 10% | C27 | 1 | Murata | GCJ188R71E105KA01D | 0603
Capacitor (MLCC) - 22uF / 6V3 / 0603 | C28, C29 | 2 | Murata Electronics | GRM188R60J226MEA0D | 0603
Capacitor (MLCC) - 4.7nF / 6V3 / 0402 | C31 | 1 | KEMET | C0402C472K9RACTU | 0402
Capacitor (Tantalum) - 68uF / 6V3 / 1206 | C32 | 1 | Kemet | T491A686K006AT | 1206
Multilayer Ceramic Capacitors MLCC - SMD/SMT 100UF 10V 20% 1206 | C34 | 1 | Murata | GRM31CR61A107MEA8L | 1206
ESD Protection Diodes / TVS Diodes PolySurg 0402 35V .05pF | D1, D2, D3, D4 | 4 | Eaton | 0402ESDA-MLP1 | 0402
Standard LEDs - SMD MINI-MOLD ULTRA COMPACT GREEN | D6 | 1 | ROHM Semiconductor | SML-P12MTT86R | 0402
Standard LEDs - SMD MINI-MOLD ULTRA COMPACT RED | D7 | 1 | ROHM Semiconductor | SML-P12VTT86R | 0402
Ferrite Beads 0603 100ohms 2000mA Auto Infotainment | FB1, FB2 | 2 | Murata Electronics | BLM18EG101TZ1D | 0603
Memory Card Connectors Micro SIM Push-Pull, 6P, SMT, 1.48mm Profile, No Peg, Without switch, T&R | J2 | 1 | GCT | SIM7205-6-0-15-00-A
1.52 A. Power Inductors - SMD 4.7 UH 20% | L3 | 1 | Murata | LQH3NPN2R2MMEL | SMD
Bipolar NPN Transistors | Q1, Q2, Q3, Q4 | 4 | Nexperia | BC847AQAZ | DFN-1010D-3
Thick Film Resistors - SMD 1/16 W 330 Ohm 1% | R1, R12 | 2 | Vishay | CRCW0402330RFKED | 0402
Thick Film Resistors - SMD 1/16 W 4.7 KOhm 1% | R2 | 1 | Vishay | CRCW04024K70FKED | 0402
Thick Film Resistors - SMD 1/16 W 47 KOhm 1% | R3, R5, R6, R7, R8, R9, R10, R15, R17, R19 | 10 | Vishay | CRCW040247K0FKED | 0402
Thick Film Resistors - SMD 1/16 W 0 Ohm | R4, R11 | 2 | Vishay | CRCW04020000Z0ED | 0402
Thick Film Resistors - SMD 1/16 W 100 KOhm 1% | R13, R20 | 2 | Vishay | CRCW0402100KFKED | 0402
Thick Film Resistors - SMD 1/16 W 383 KOhm 1% | R14 | 1 | Vishay | CRCW0402383KFKED | 0402
Thick Film Resistors - SMD 1/16 W 10 KOhm 1% | R16, R18 | 2 | Vishay | CRCW040210K0FKED | 0402
MOLEX 73412-0110 RF COAXIAL, MICROCOAXIAL, JACK, 50OHM | RF1 | 1 | Molex | 73412-0110 | SMD
Telit LE910C1-EUX LTE/2G GSM Module | U1 | 1 | Telit | LE910C1-EUX | BGA
Translation - Voltage Levels 8-Bit Dual-Supply Bus Transceiver 24-TSSOP -40 to 125 | U2 | 1 | Texas Instruments | SN74AXC8T245PWR | TSSOP-24
Switching Voltage Regulators 3-17V 3A Step Down Converter. | U3 | 1 | Texas Instruments | TPS62130ARGTR | VQFN-EP-16

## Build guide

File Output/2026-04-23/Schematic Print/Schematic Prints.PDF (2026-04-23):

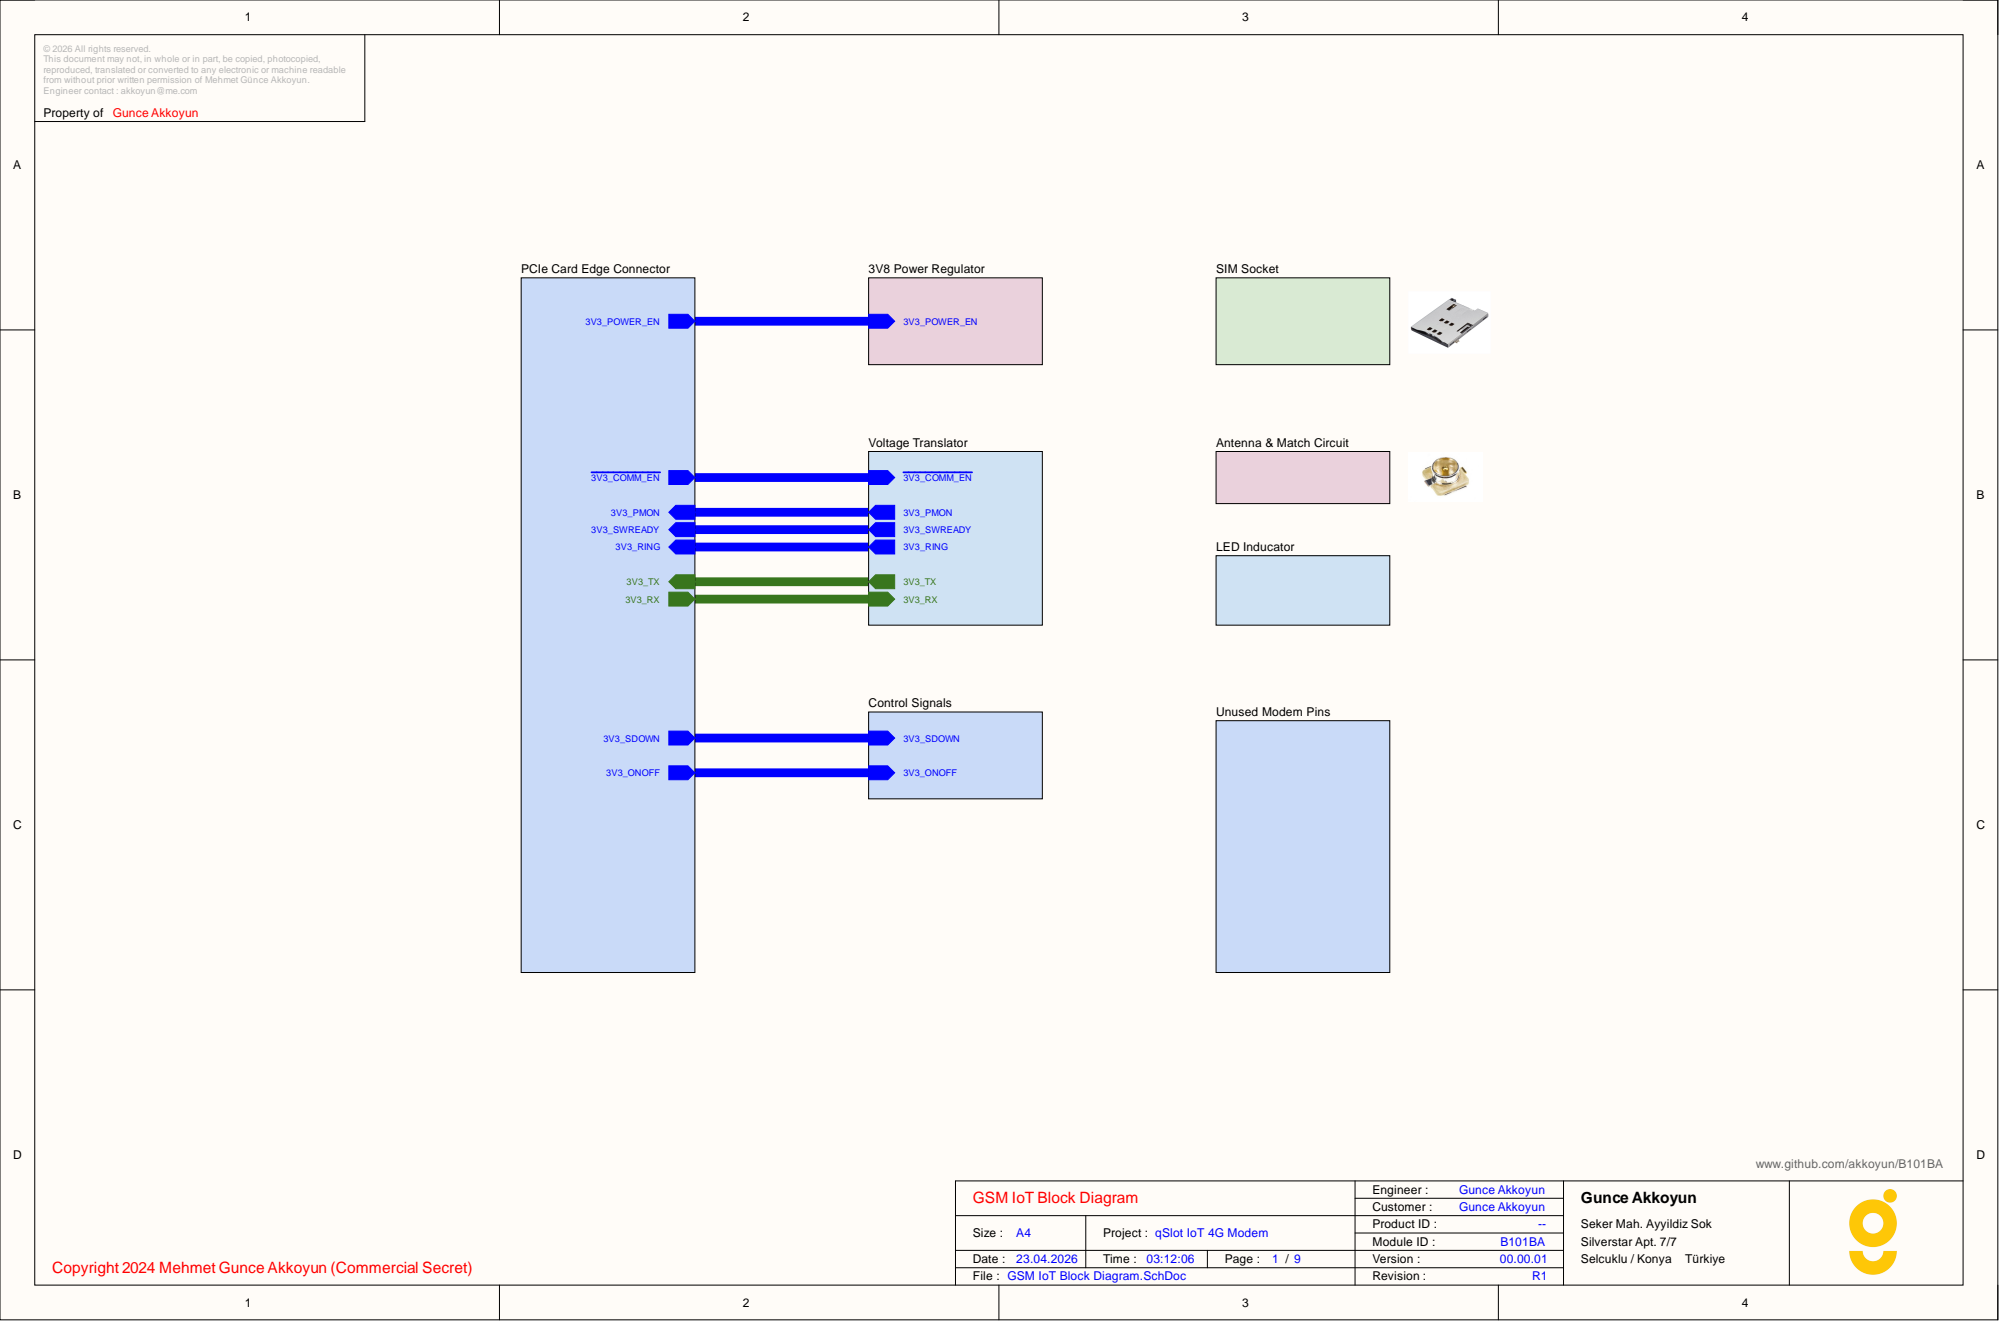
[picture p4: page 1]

© 2026 All rights reserved.
This document may not, in whole or in part, be copied, photocopied,
reproduced, translated or converted to any electronic or machine readable
from without prior written permission of Mehmet Günce Akkoyun.
Engineer contact : akkoyun@me.com

Property of Gunce Akkoyun

PCIe Card Edge Connector

www.github.com/akkoyun/B101BA

GSM IoT Block Diagram

Seker Mah. Ayyildiz Sok
Silverstar Apt. 7/7
Selcuklu / Konya Türkiye

Copyright 2024 Mehmet Gunce Akkoyun (Commercial Secret)

File : GSM IoT Block Diagram.SchDoc

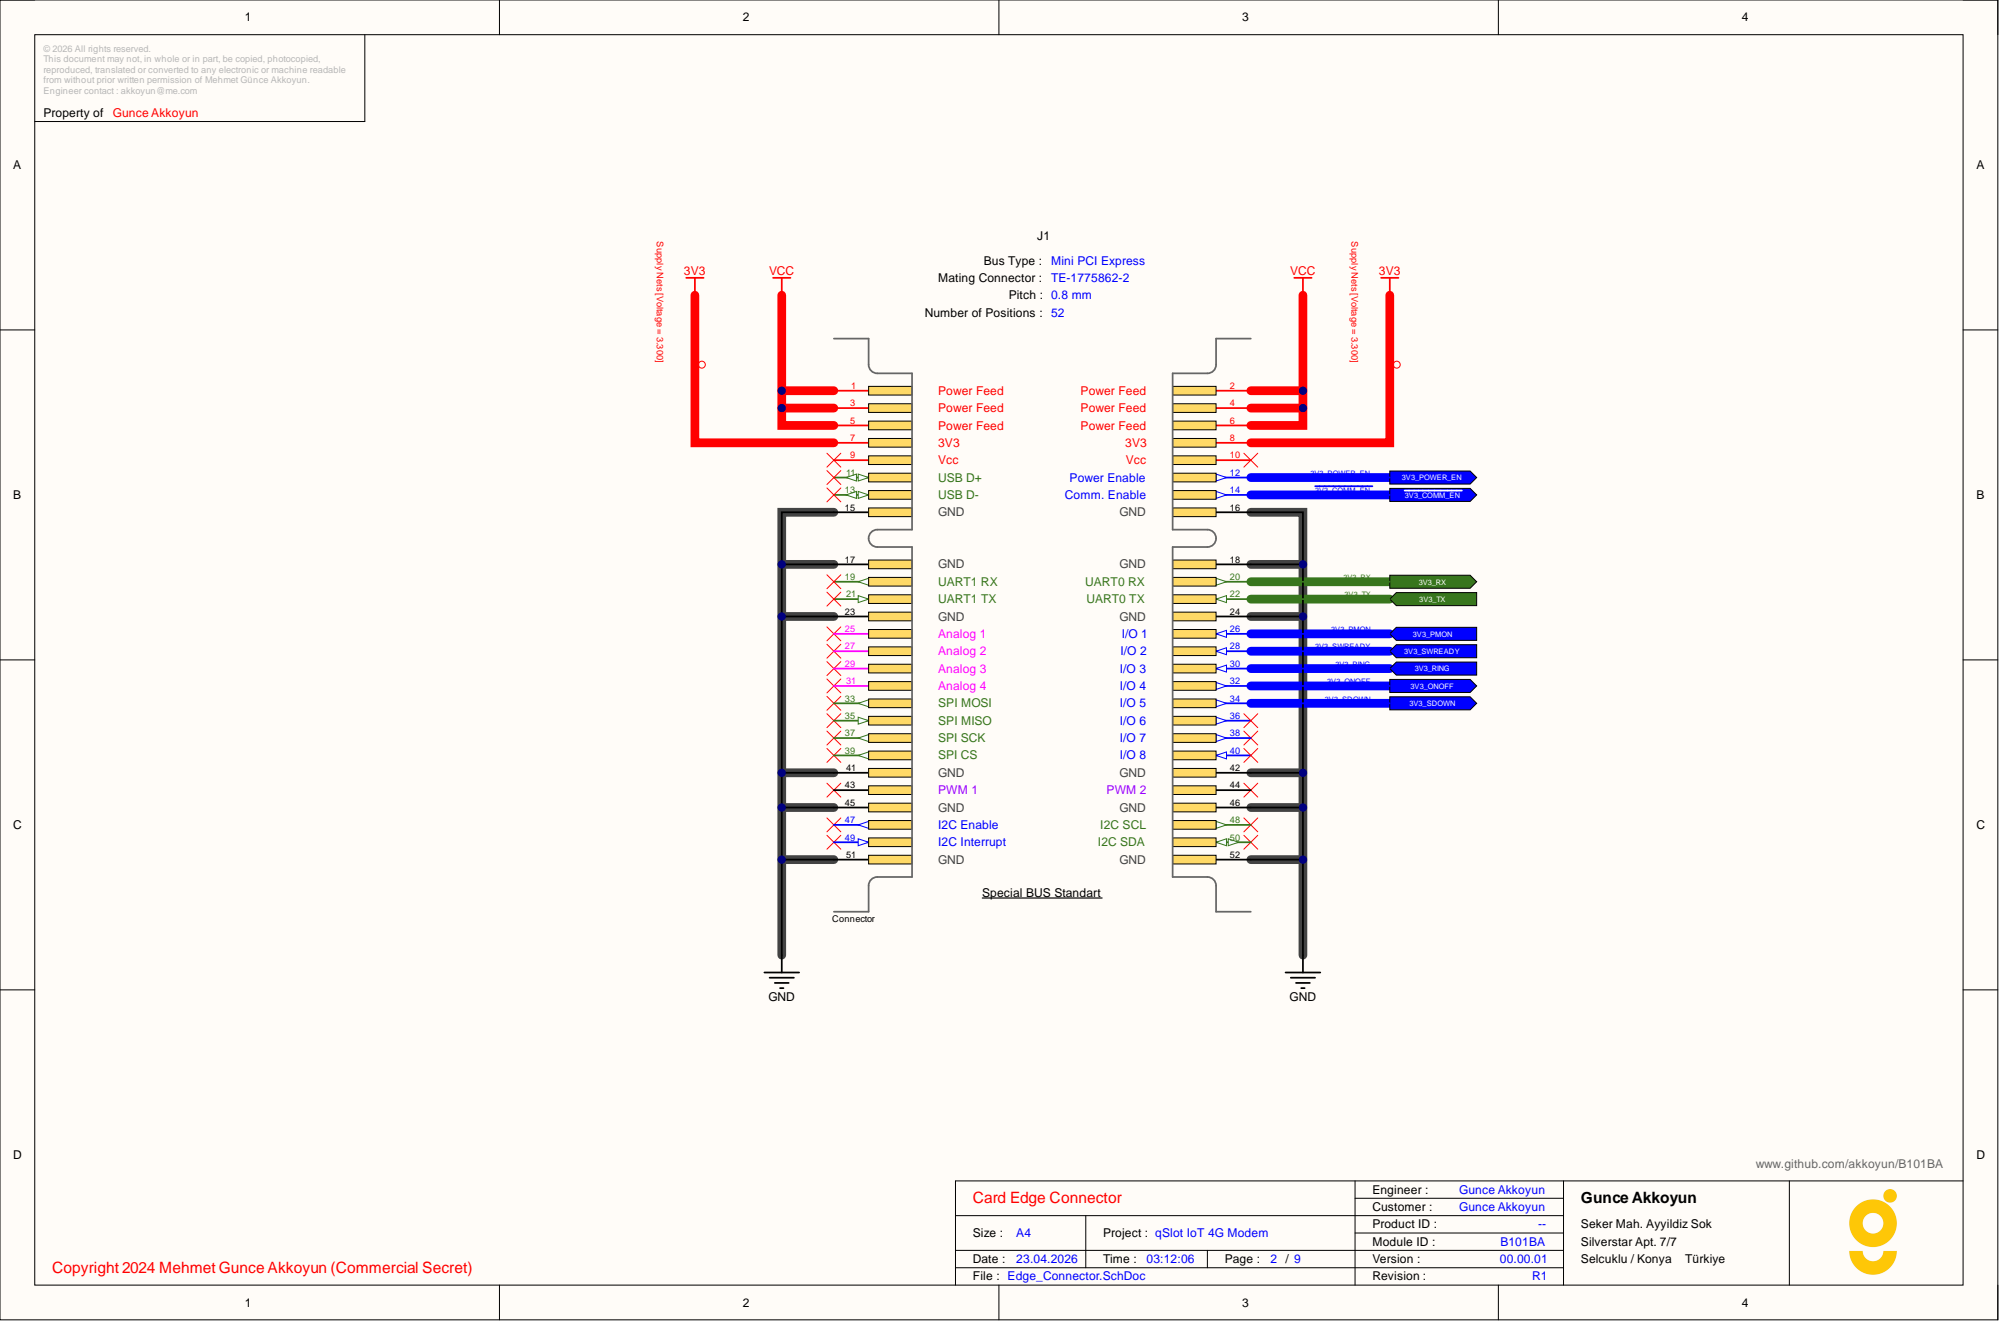
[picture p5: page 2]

Property of Gunce Akkoyun

www.github.com/akkoyun/B101BA

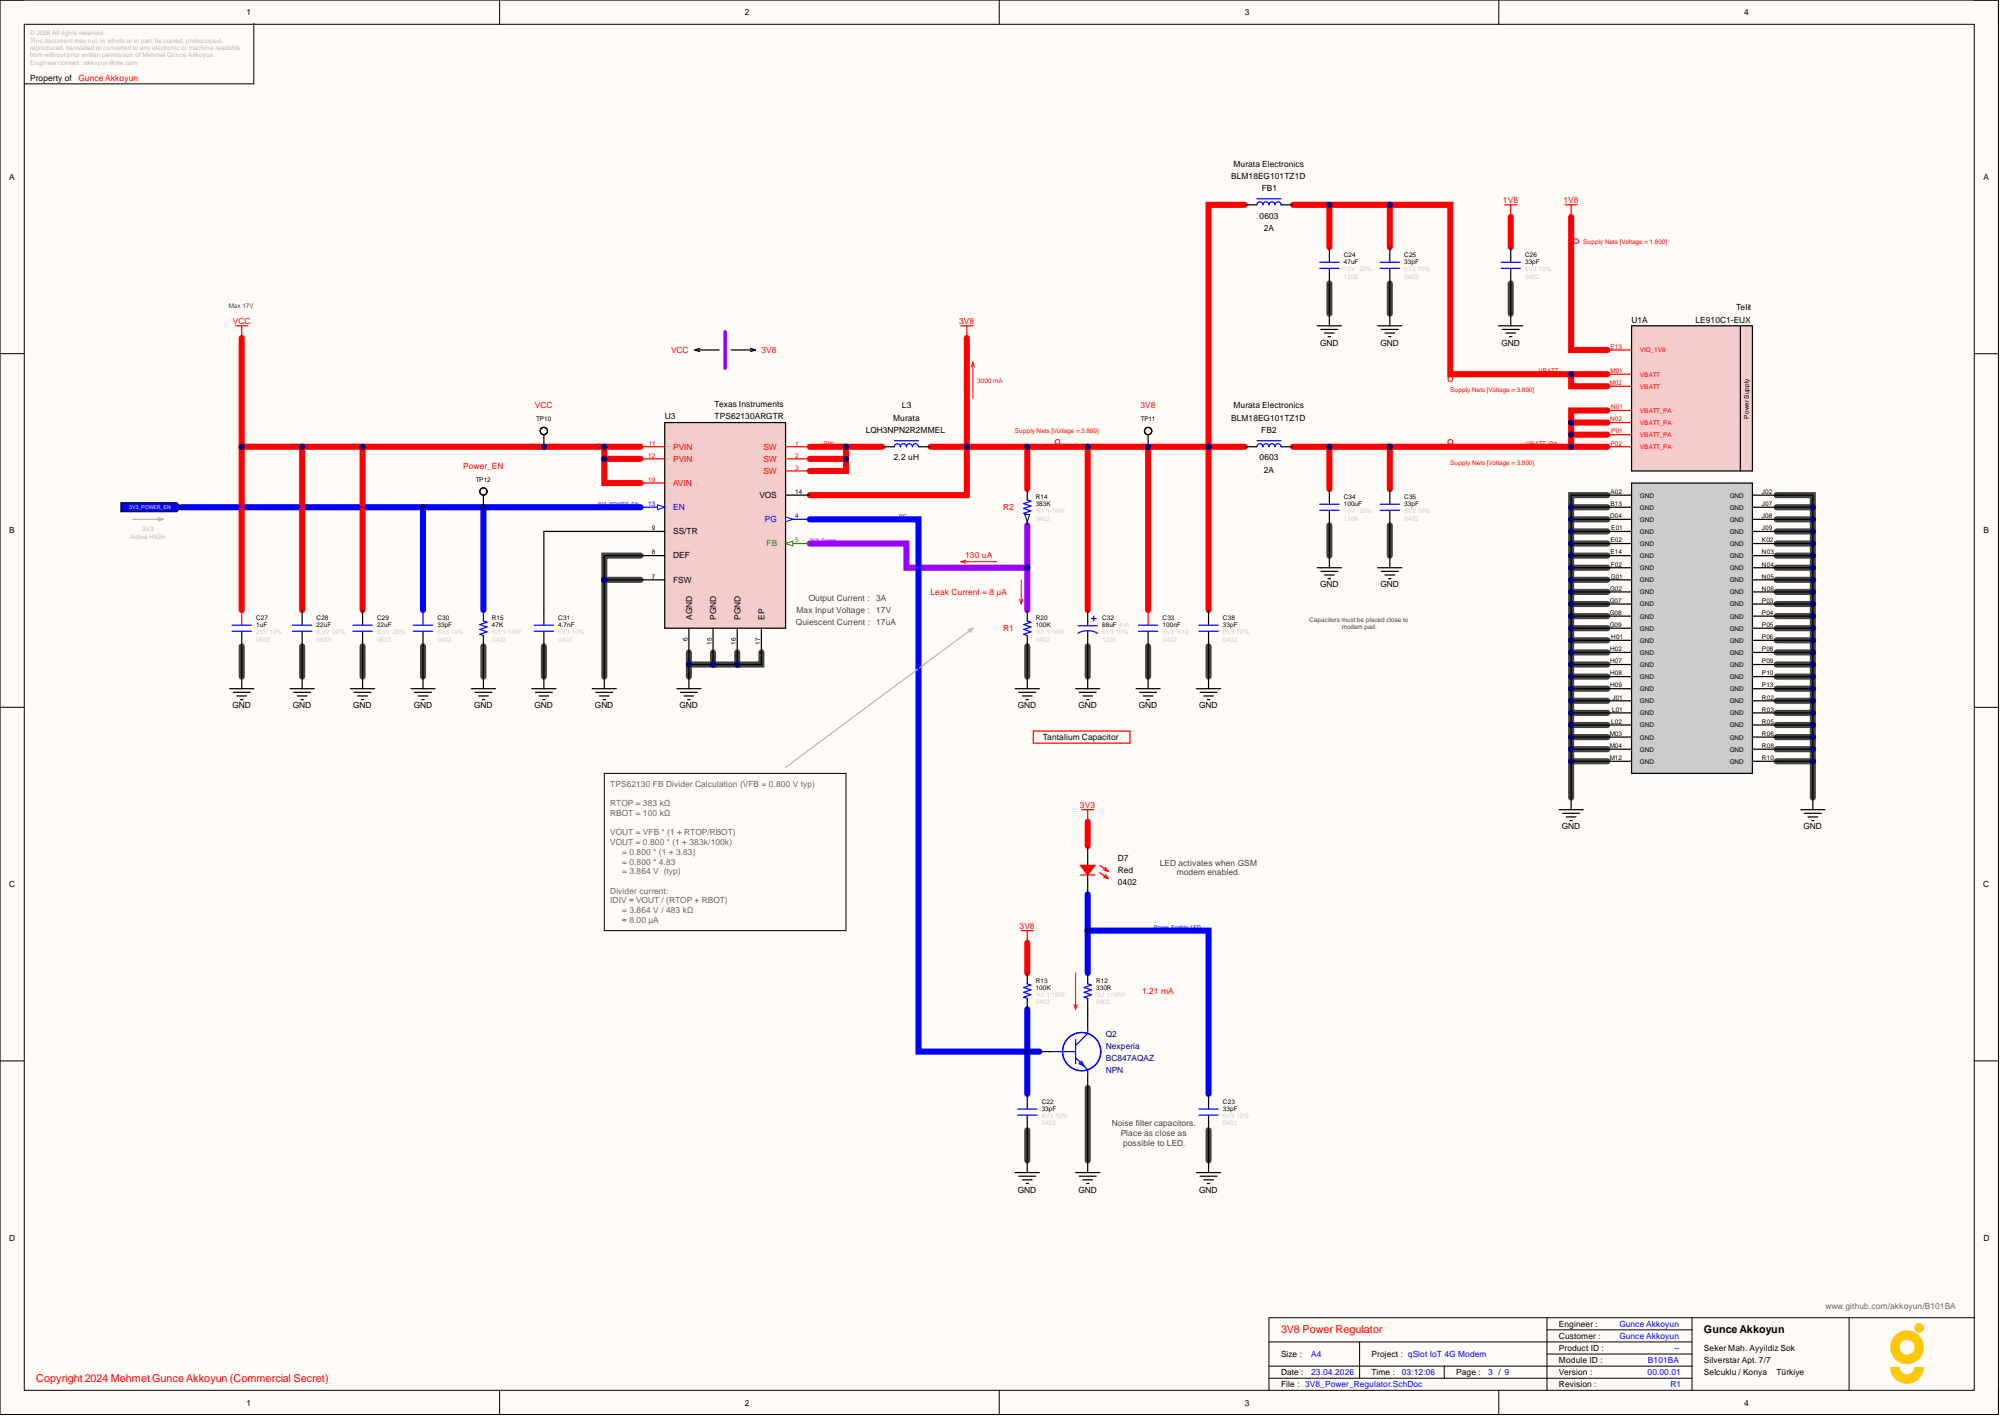
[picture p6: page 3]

Property of Gunce Akkoyun

Capacitors must be placed close to

TPS62130 FB Divider Calculation (VFB = 0.800 V typ)

Divider current:
IDIV ≈ VOUT / (RTOP + RBOT)

Noise filter capacitors.
Place as close as
possible to LED.

www.github.com/akkoyun/B101BA

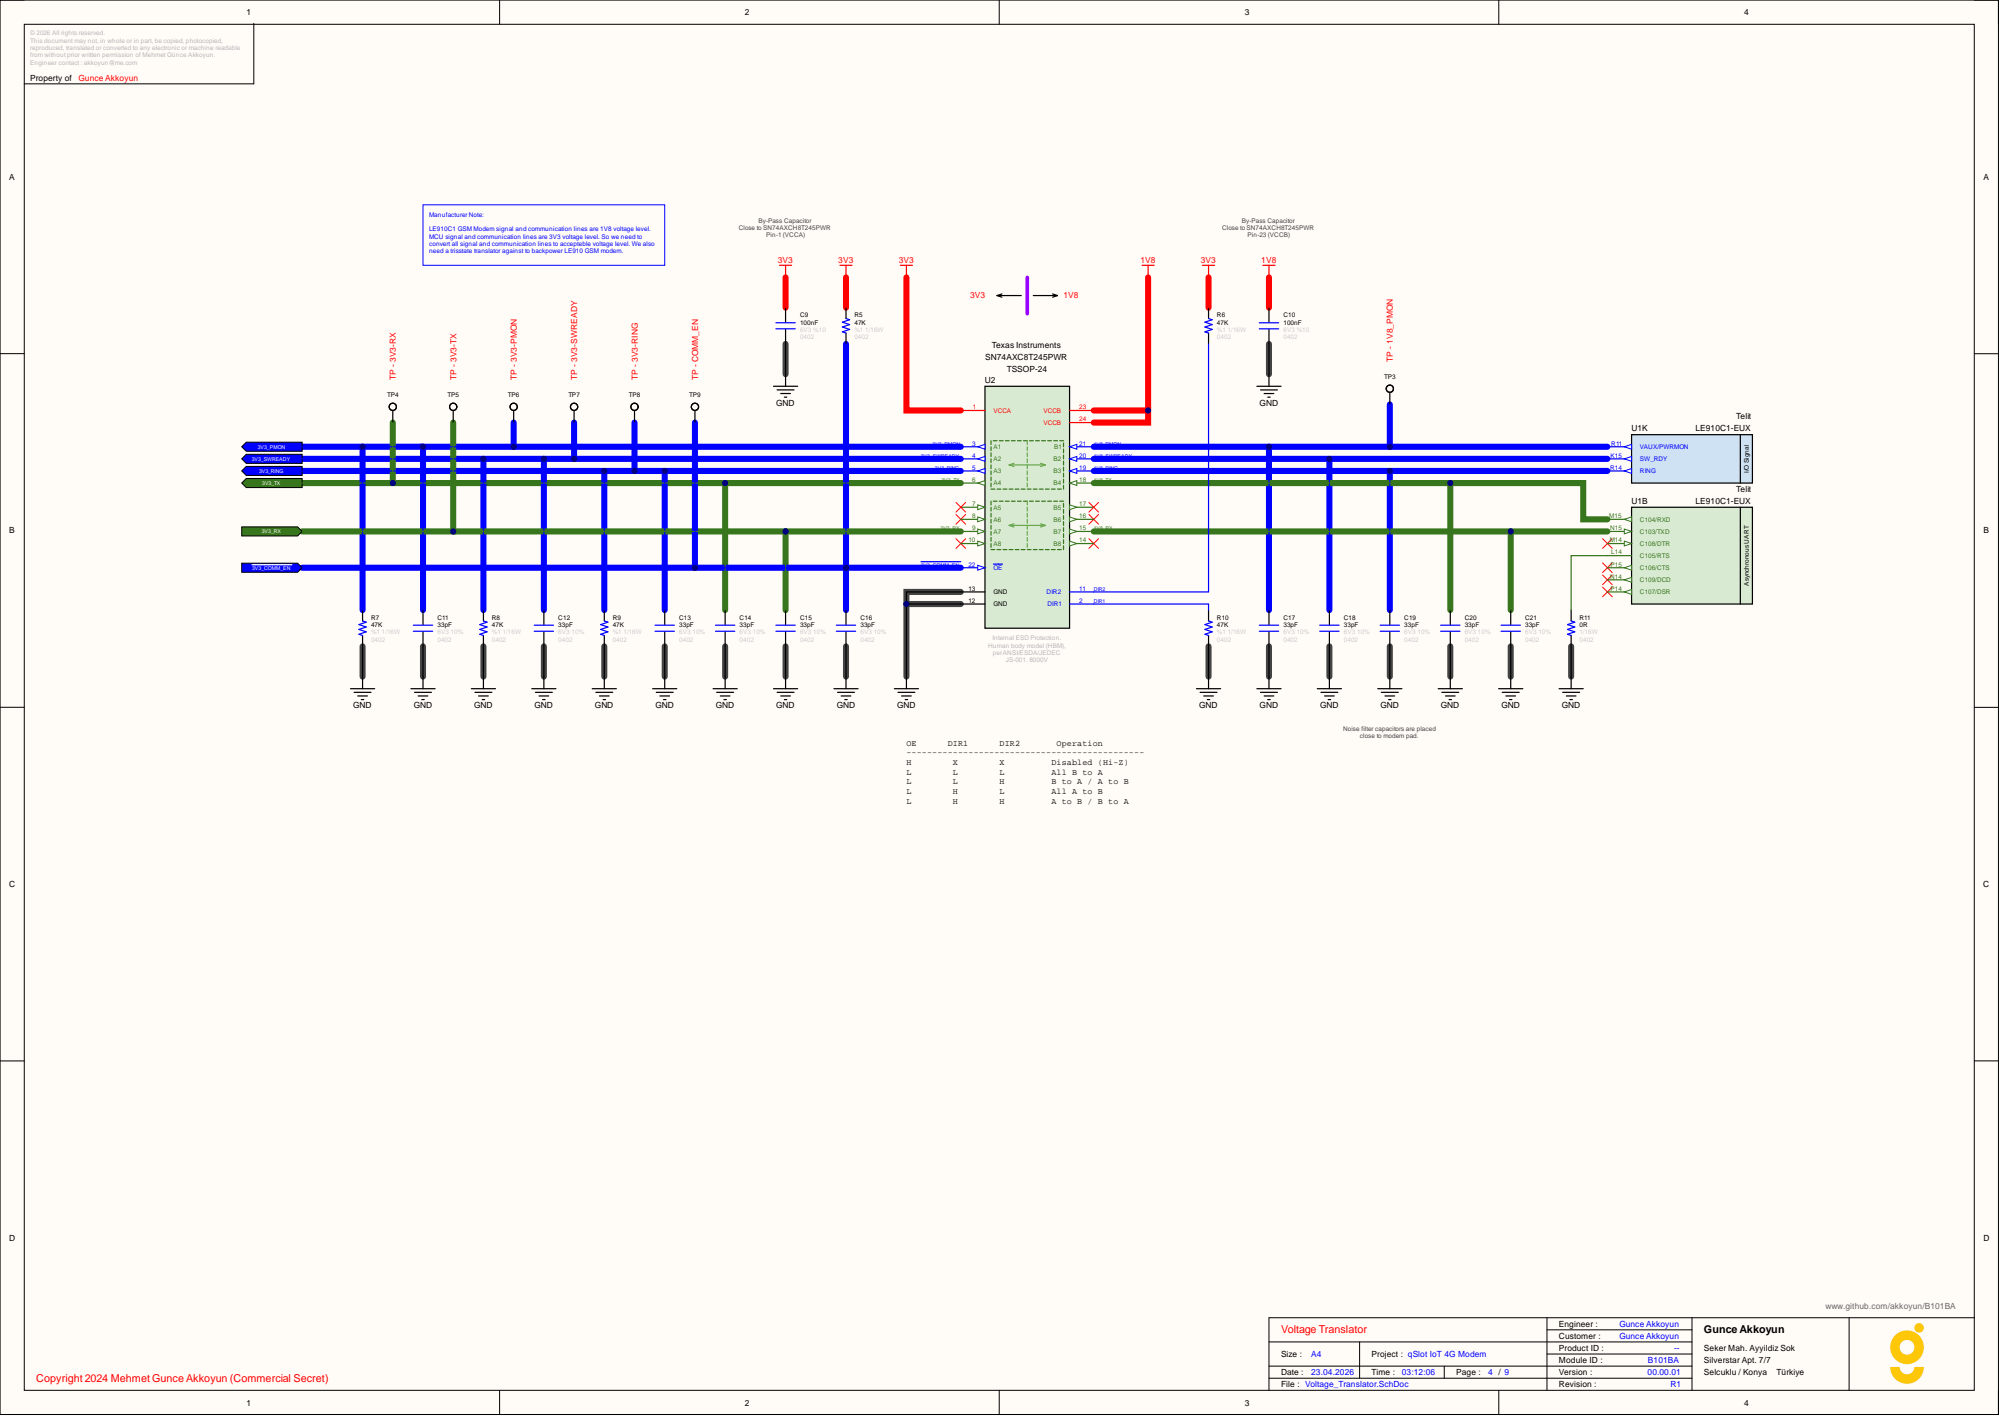
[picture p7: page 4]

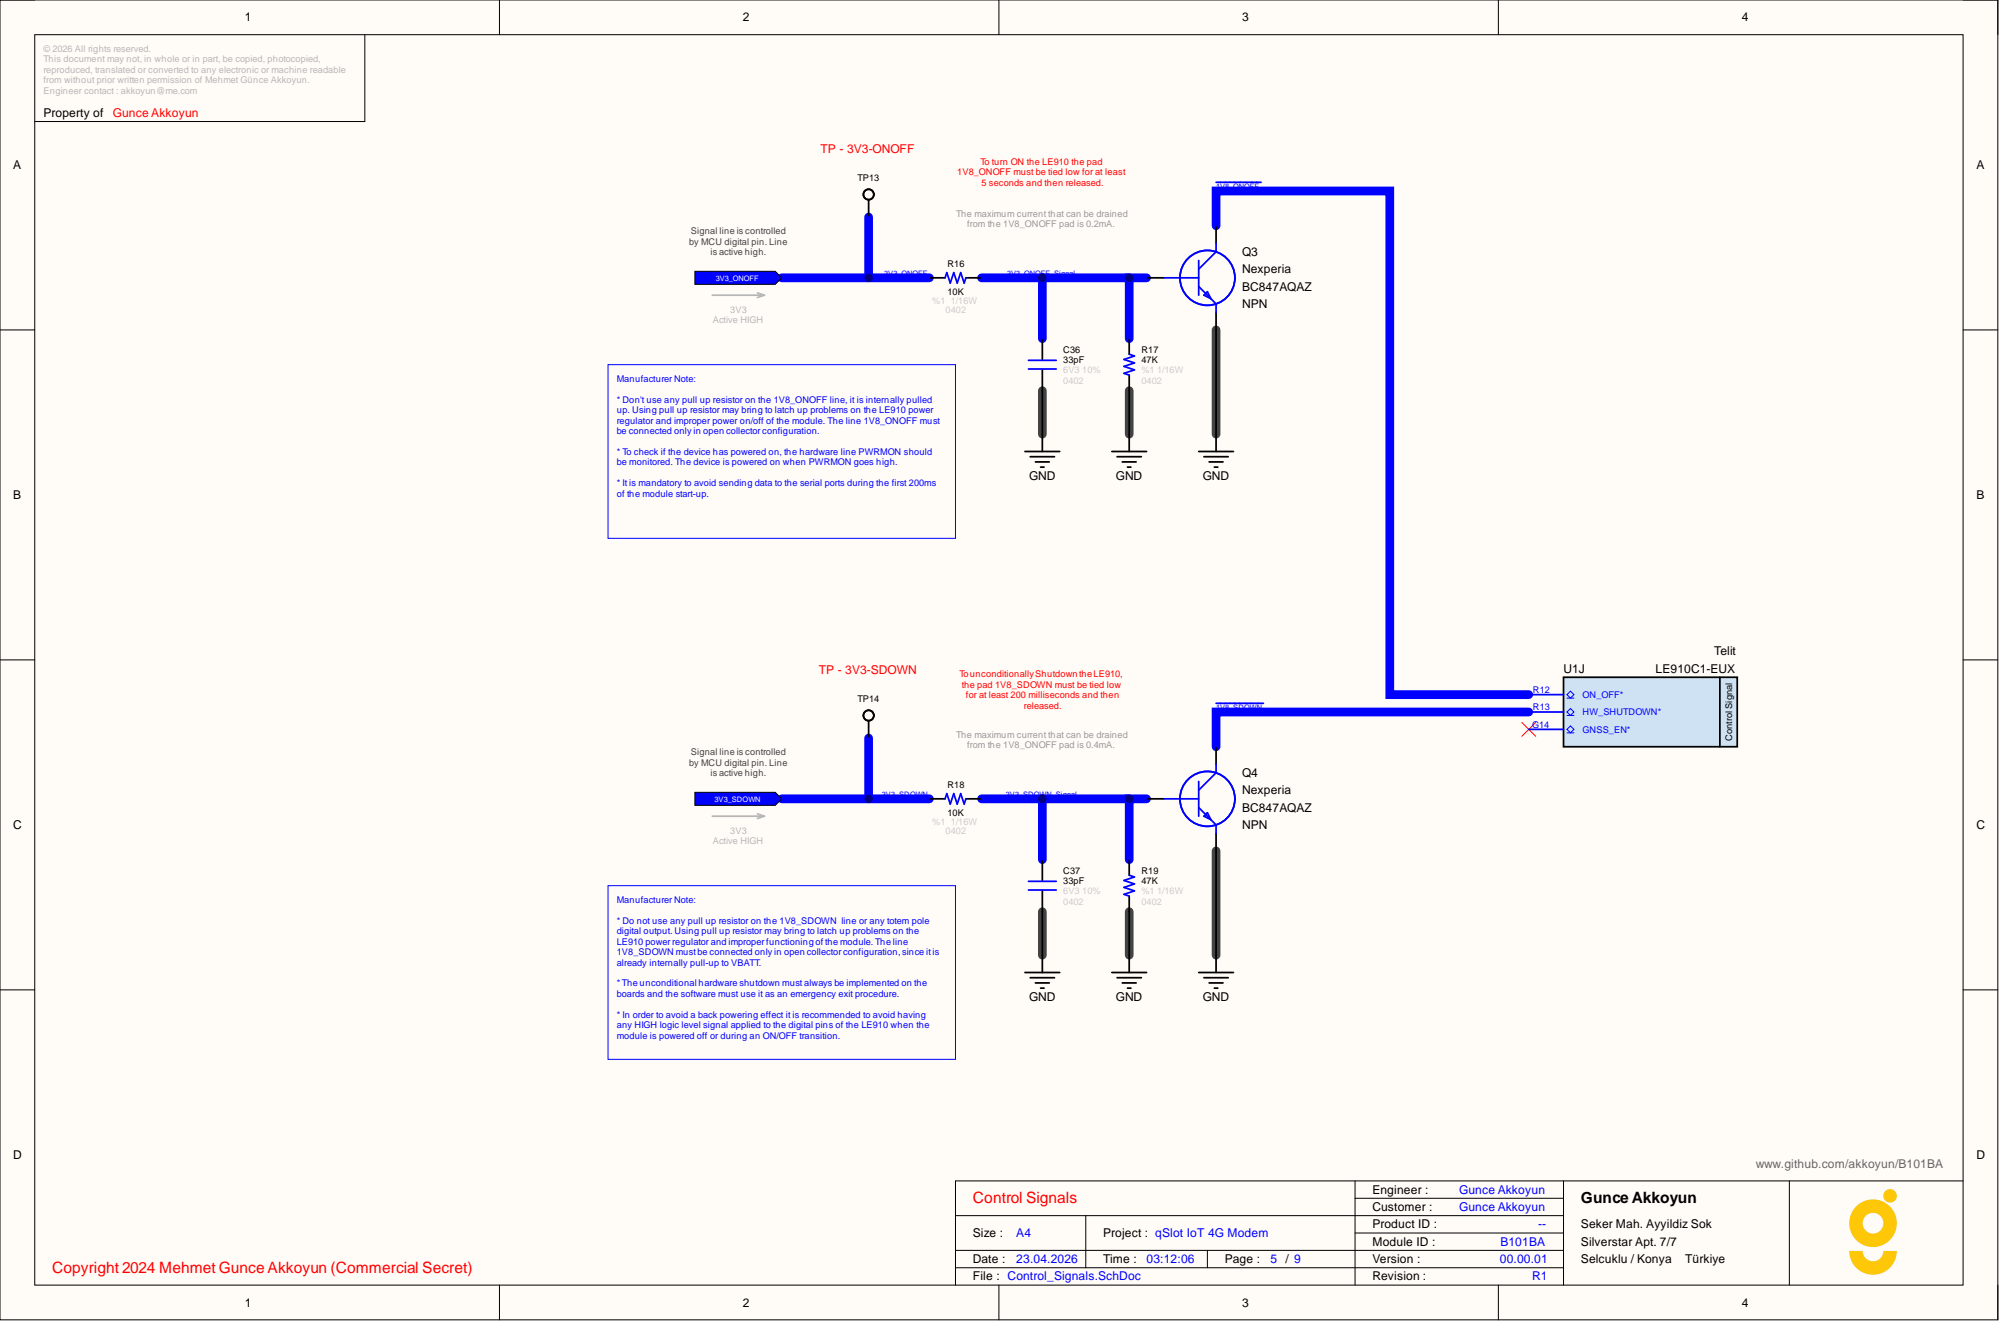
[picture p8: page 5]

Property of Gunce Akkoyun

To turn ON the LE910 the pad
1V8_ONOFF must be tied low for at least
5 seconds and then released.

The maximum current that can be drained
from the 1V8_ONOFF pad is 0.2mA.

Signal line is controlled
by MCU digital pin. Line
is active high.

* Don't use any pull up resistor on the 1V8_ONOFF line, it is internally pulled
up. Using pull up resistor may bring to latch up problems on the LE910 power
regulator and improper power on/off of the module. The line 1V8_ONOFF must
be connected only in open collector configuration.

* To check if the device has powered on, the hardware line PWRMON should
be monitored. The device is powered on when PWRMON goes high.

* It is mandatory to avoid sending data to the serial ports during the first 200ms
of the module start-up.

To unconditionally Shutdown the LE910,
the pad 1V8_SDOWN must be tied low
for at least 200 milliseconds and then

from the 1V8_ONOFF pad is 0.4mA.

* Do not use any pull up resistor on the 1V8_SDOWN line or any totem pole
digital output. Using pull up resistor may bring to latch up problems on the
LE910 power regulator and improper functioning of the module. The line
1V8_SDOWN must be connected only in open collector configuration, since it is
already internally pull-up to VBATT.

* The unconditional hardware shutdown must always be implemented on the
boards and the software must use it as an emergency exit procedure.

* In order to avoid a back powering effect it is recommended to avoid having
any HIGH logic level signal applied to the digital pins of the LE910 when the
module is powered off or during an ON/OFF transition.

www.github.com/akkoyun/B101BA

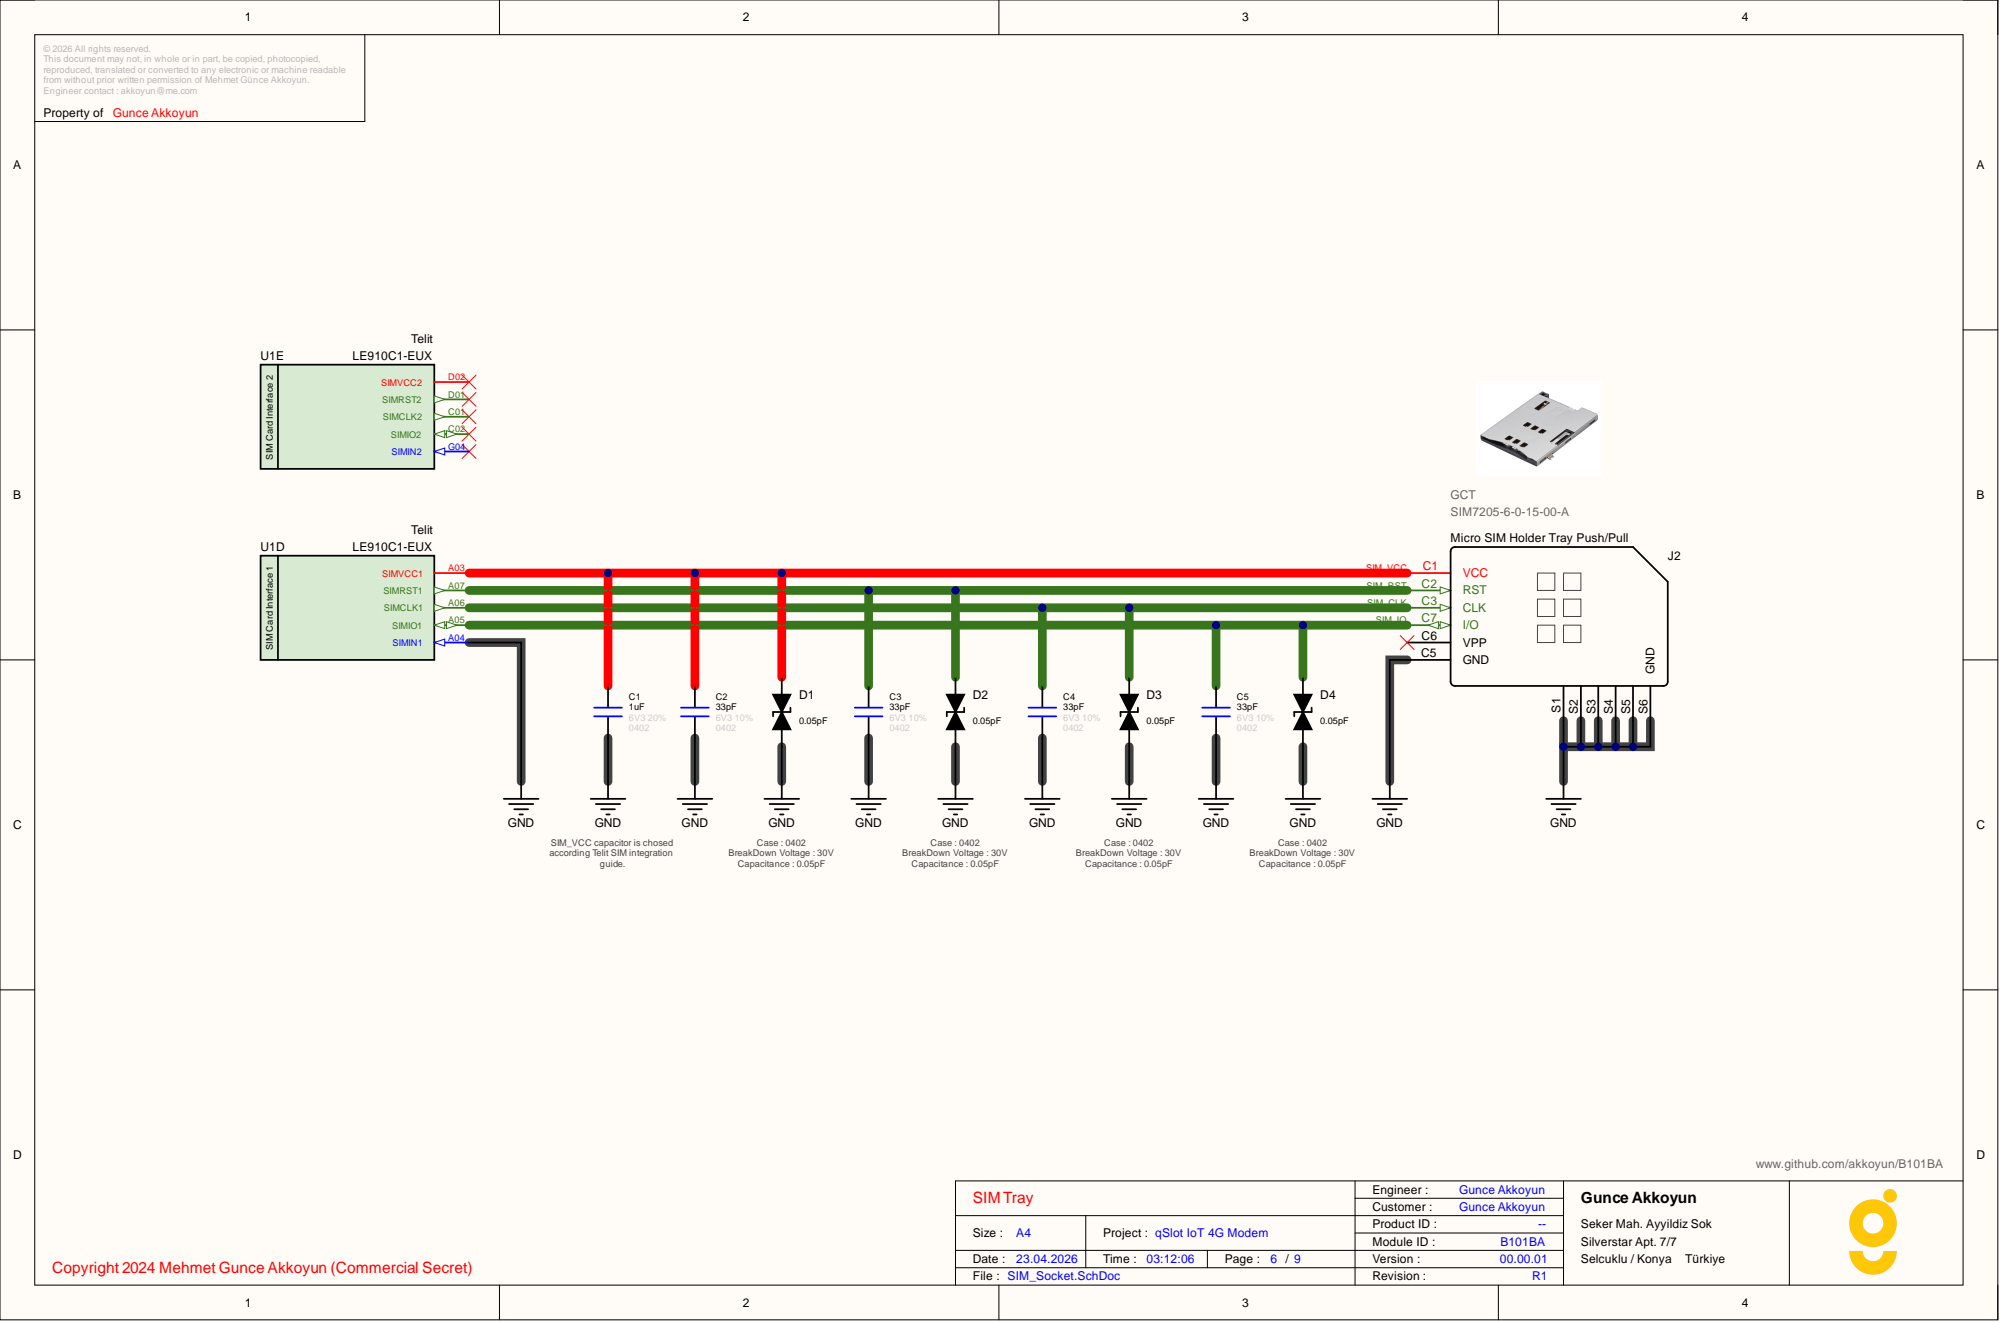
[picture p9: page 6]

A05 | | M_CLK SIM_IO

A04 | | | VPP C6

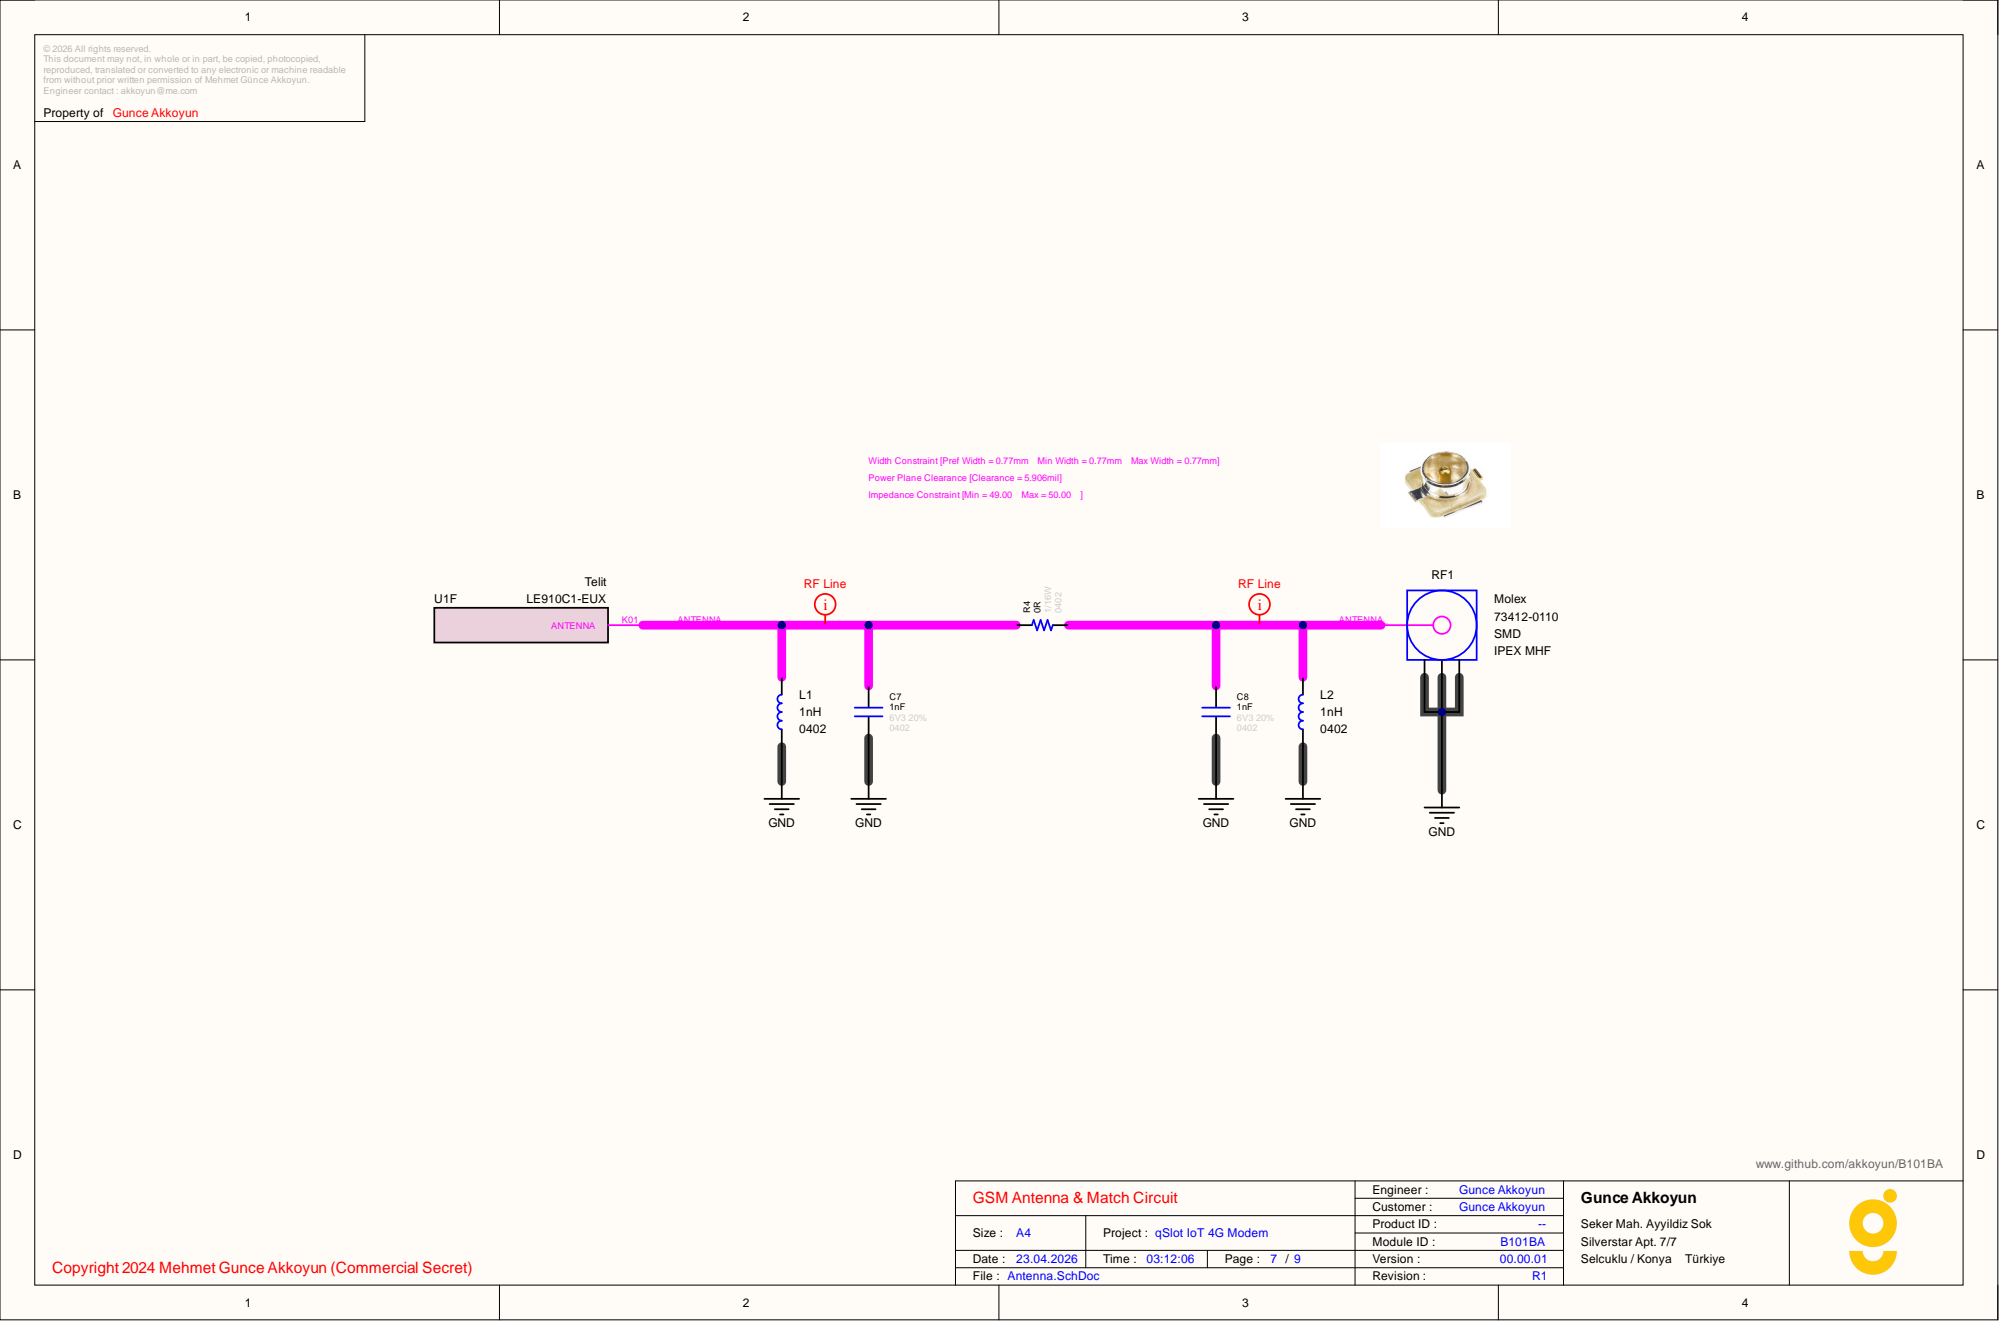
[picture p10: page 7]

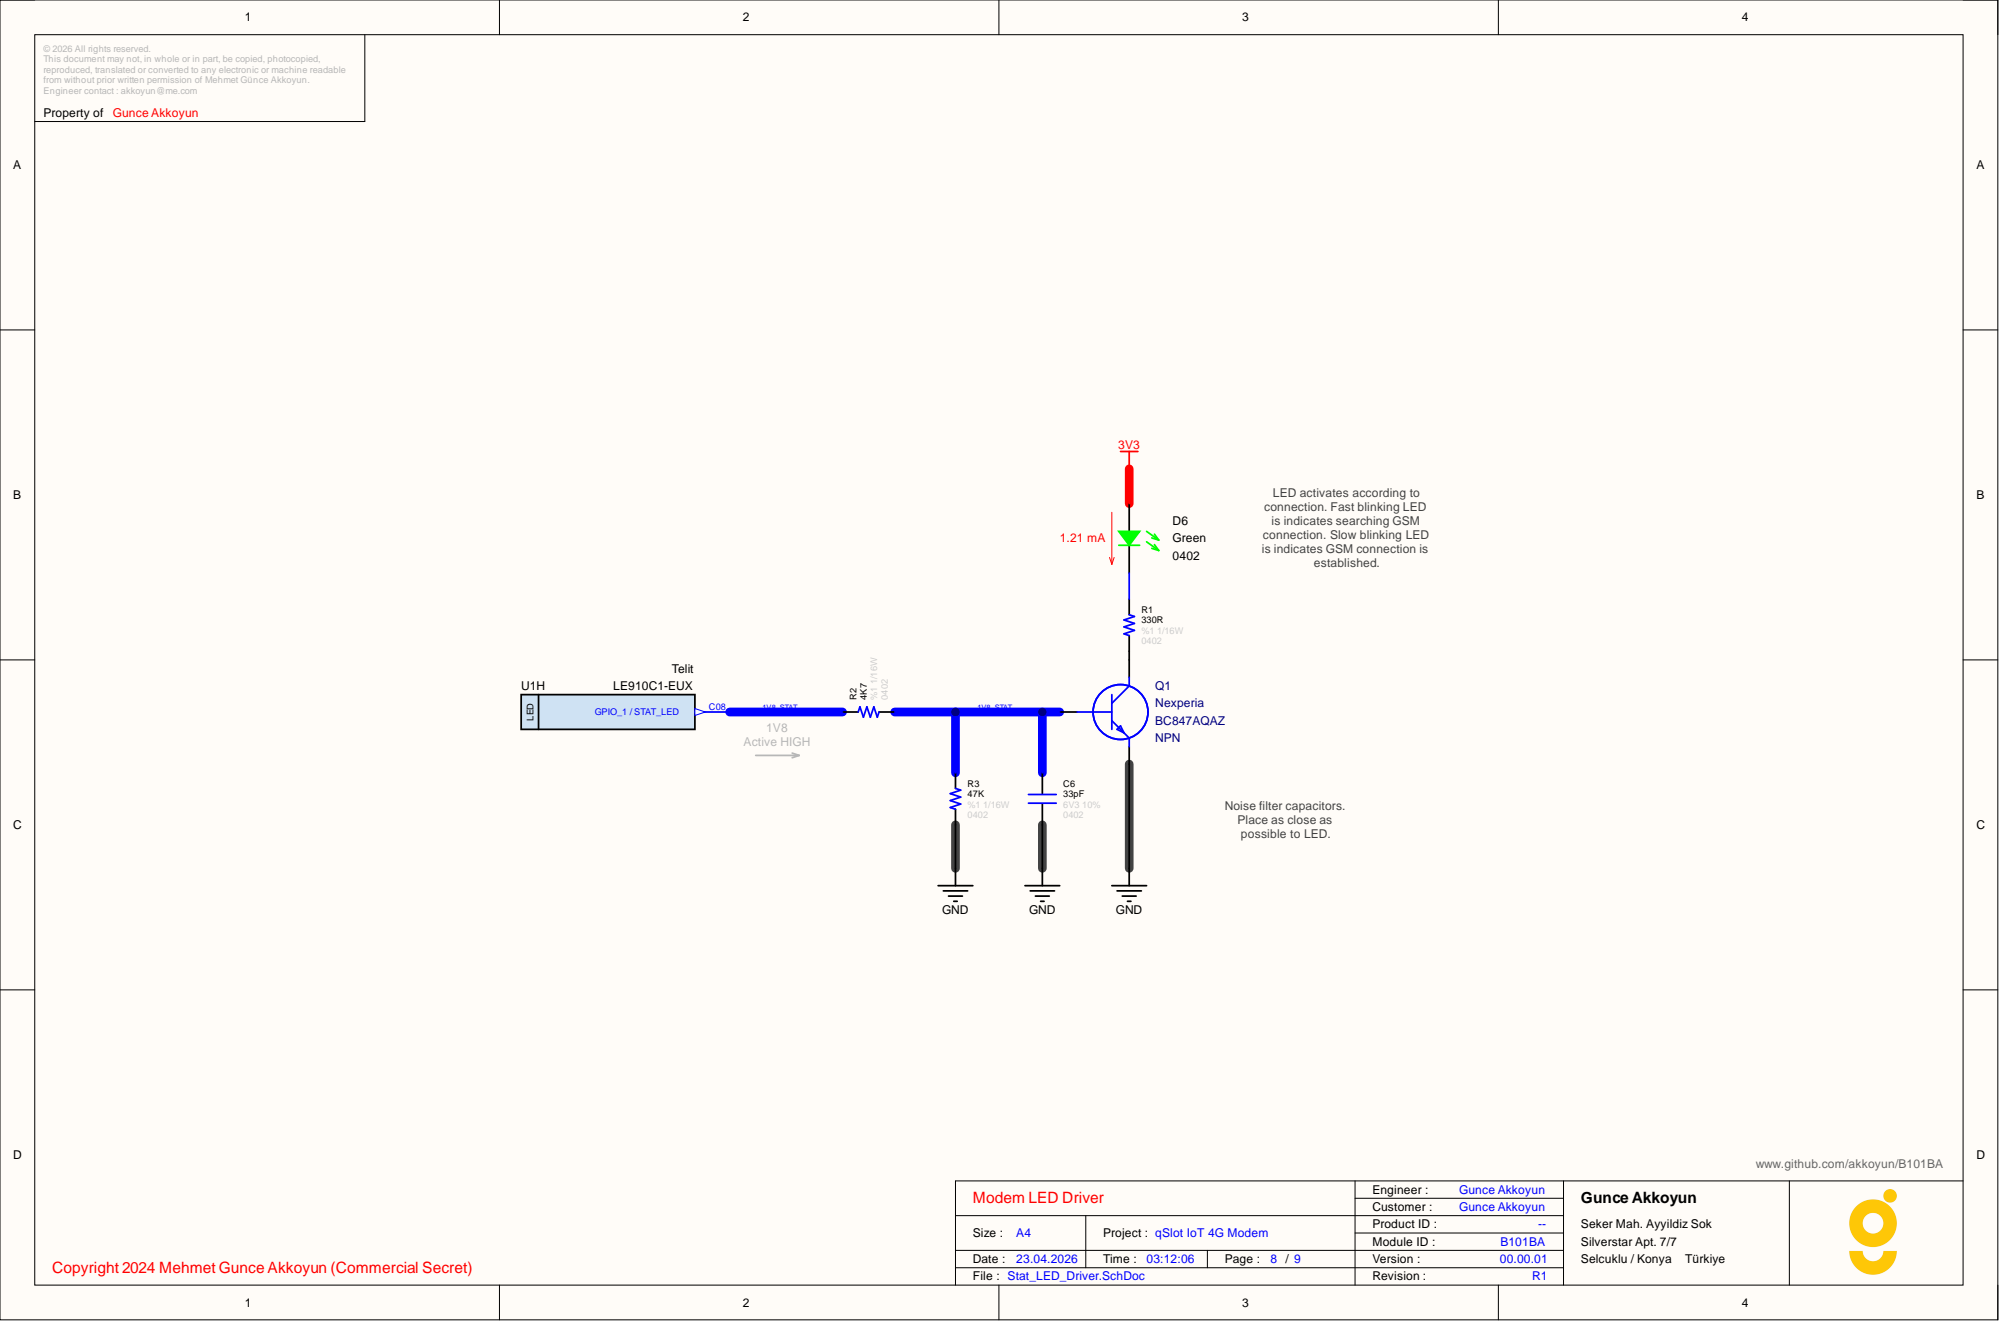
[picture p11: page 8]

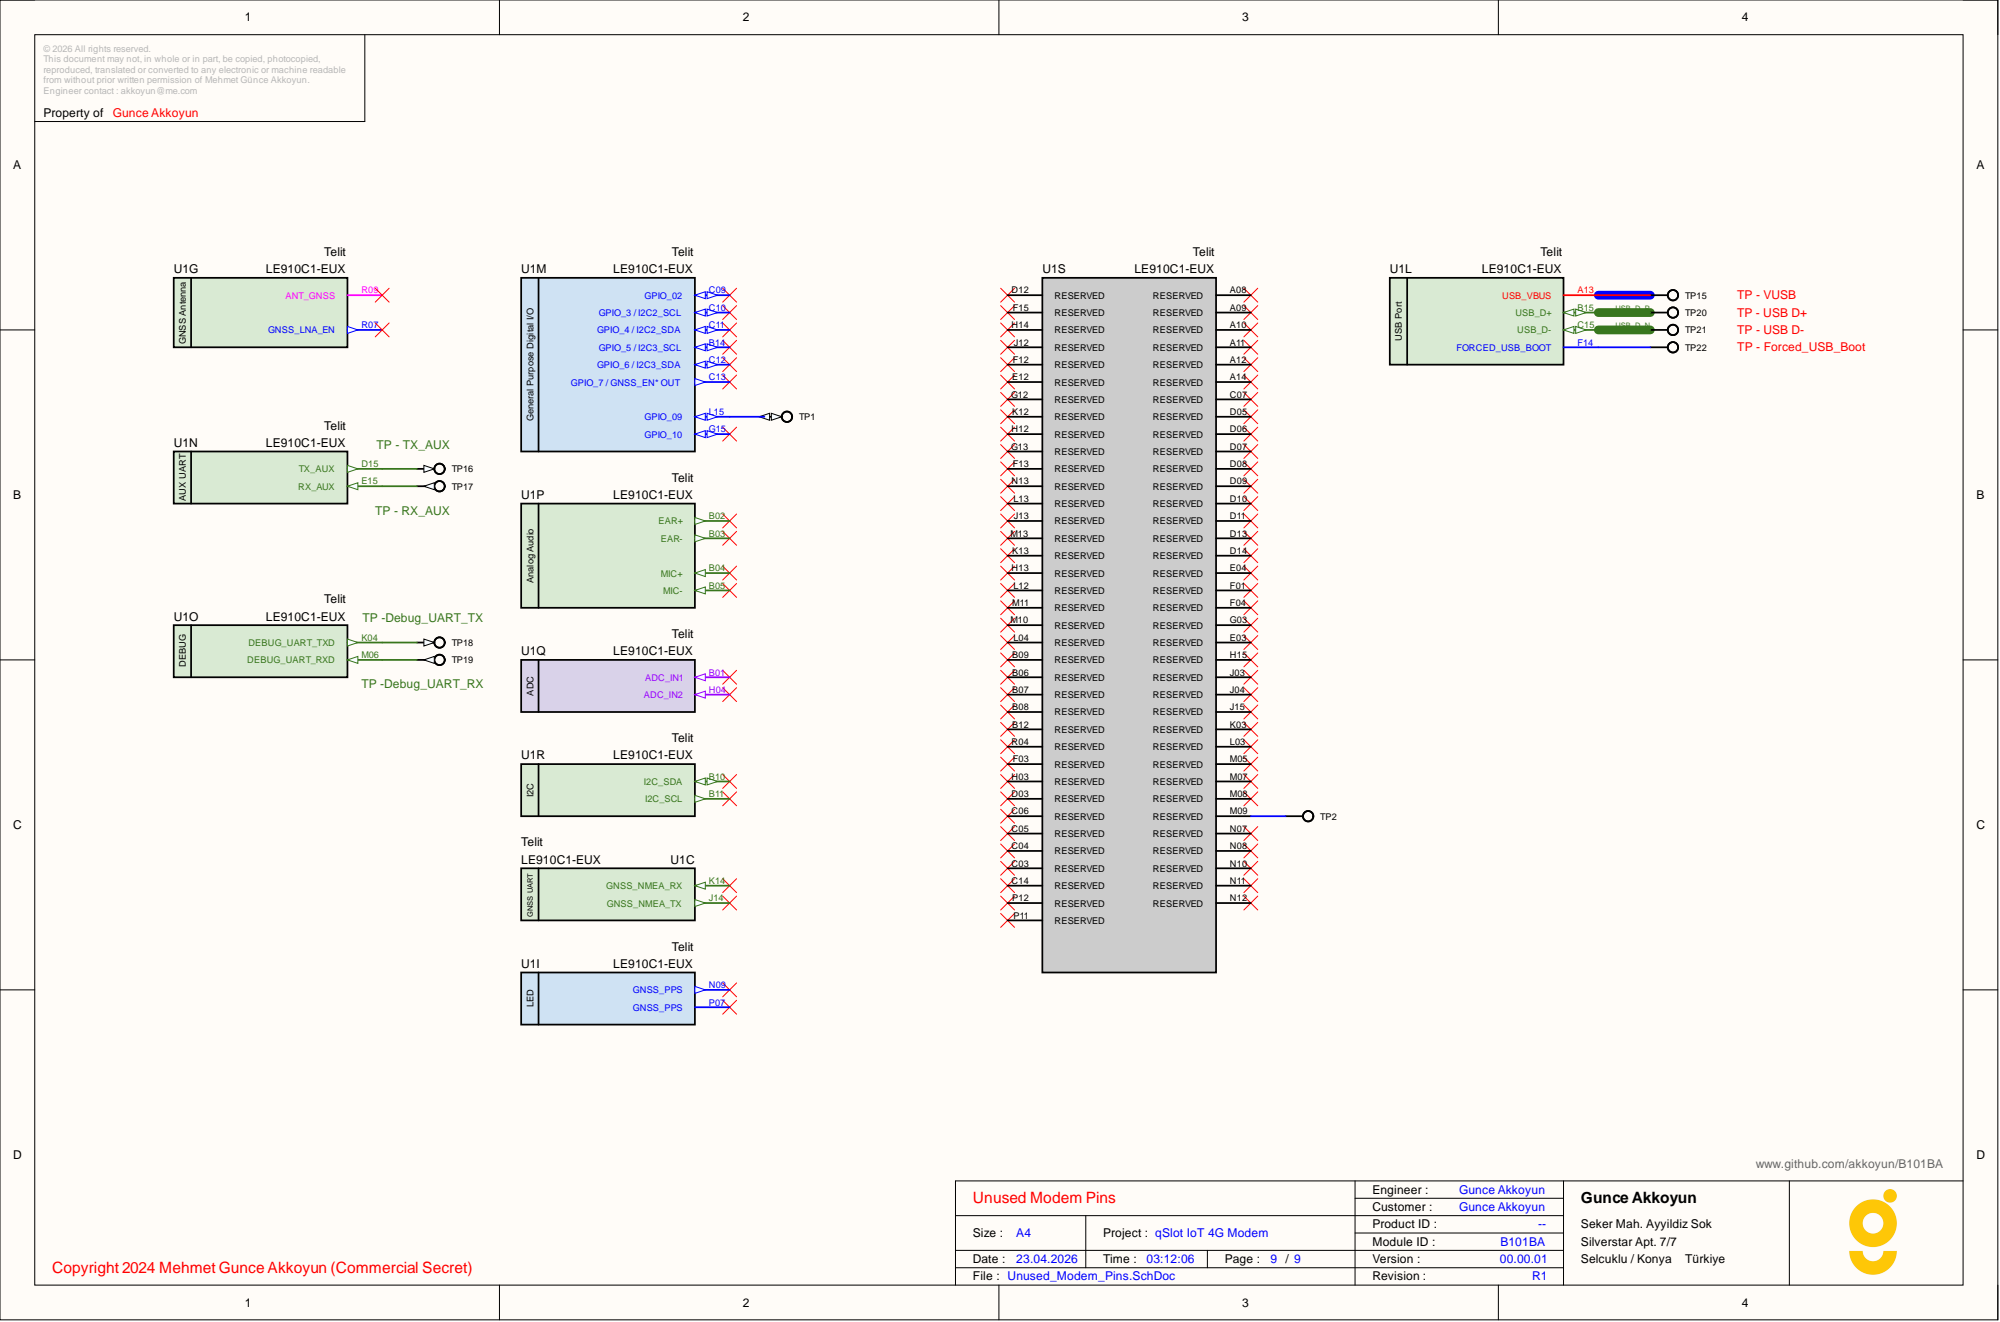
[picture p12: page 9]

TX_A U X R X_A U X | 0C1-EUX Telit U1 P LE9 1

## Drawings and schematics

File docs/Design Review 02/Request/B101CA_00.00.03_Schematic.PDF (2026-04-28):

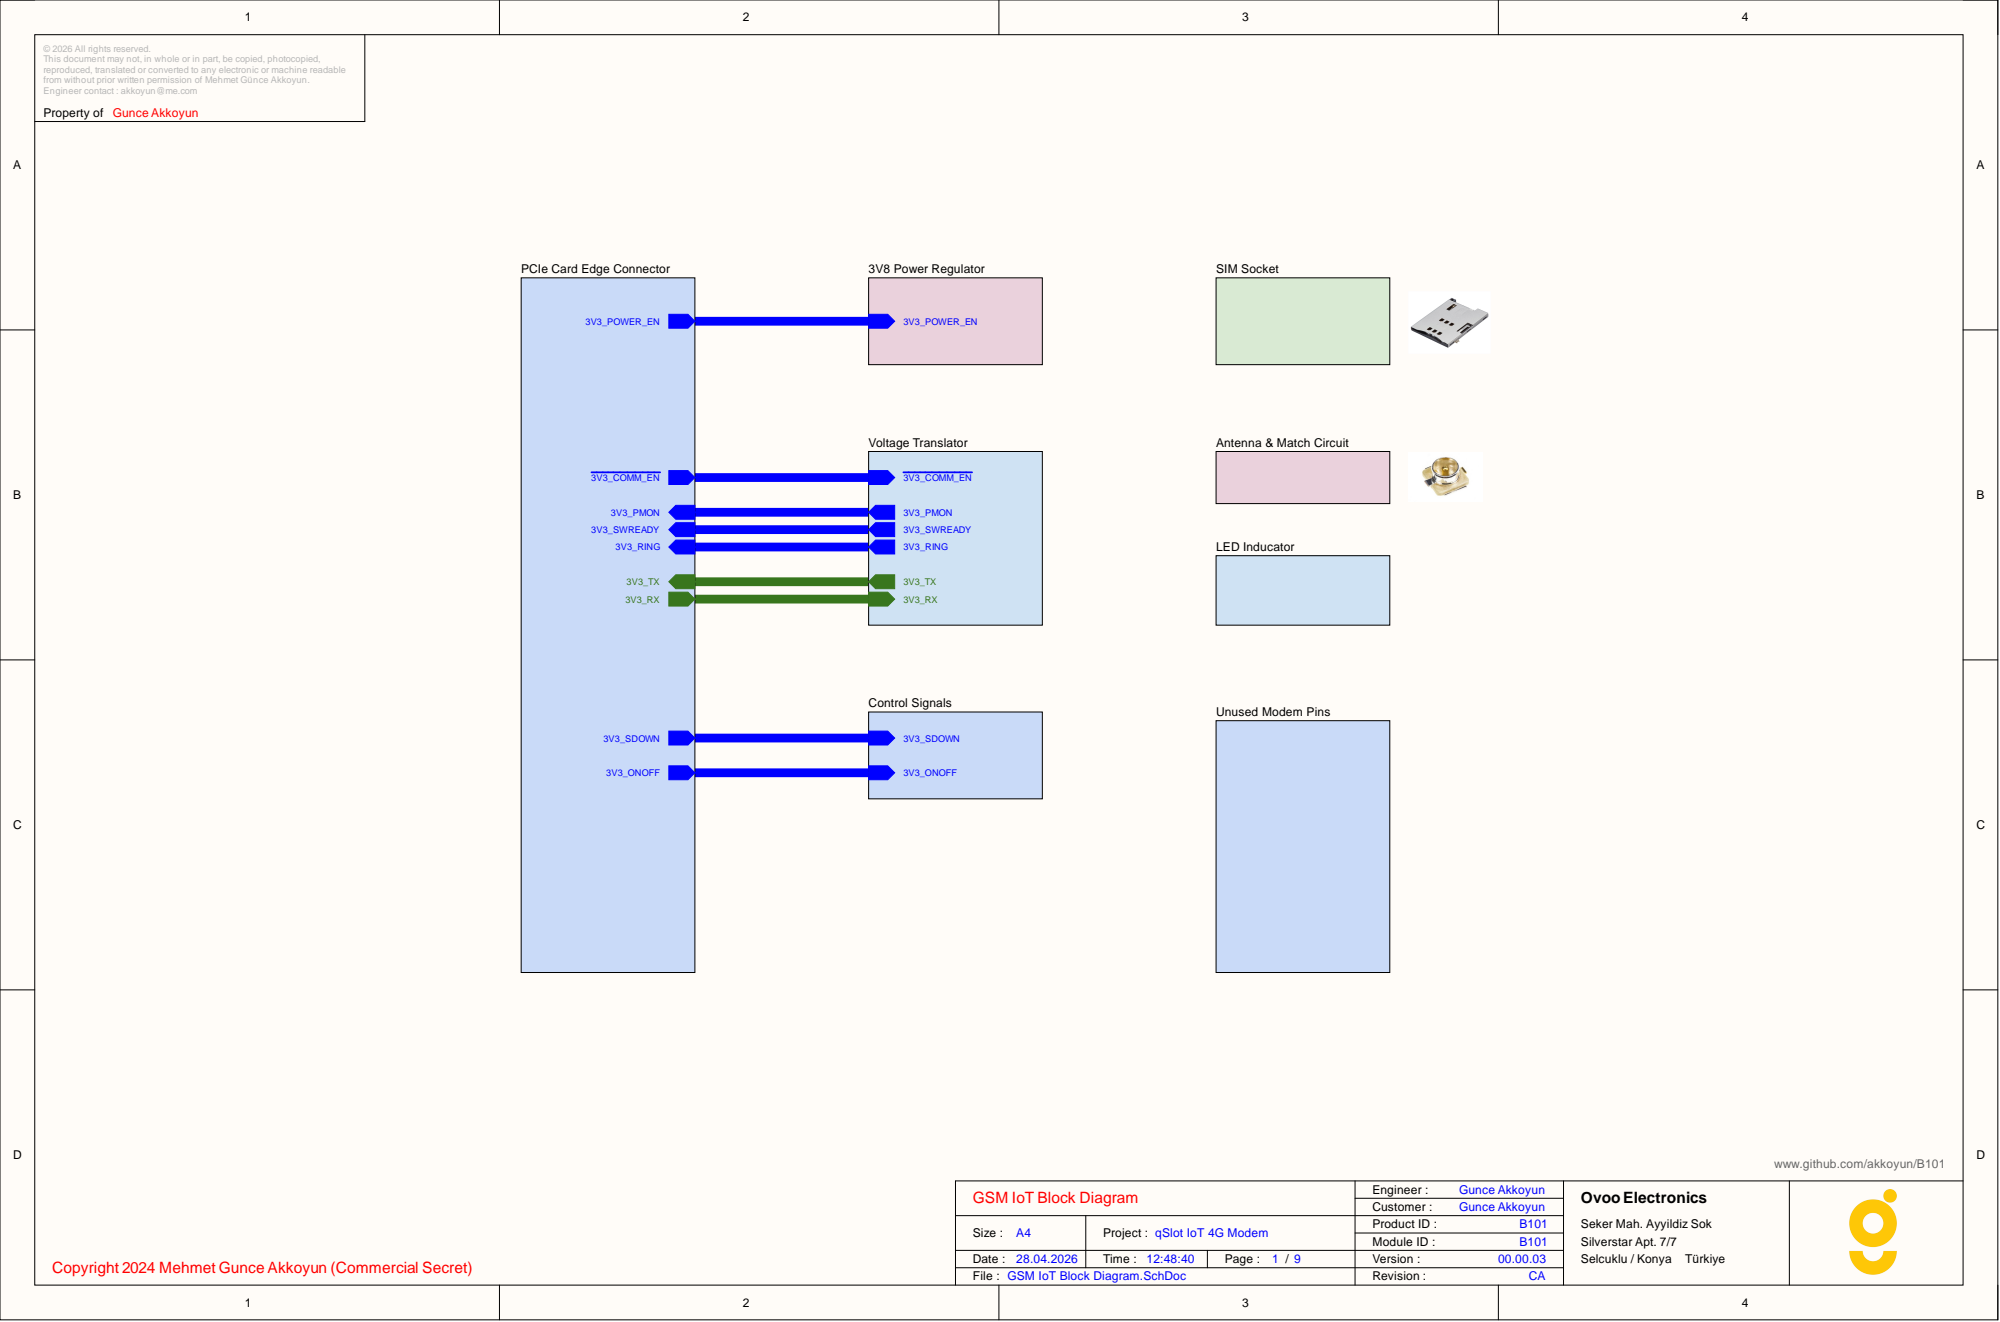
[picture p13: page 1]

© 2026 All rights reserved.
This document may not, in whole or in part, be copied, photocopied,
reproduced, translated or converted to any electronic or machine readable
from without prior written permission of Mehmet Günce Akkoyun.
Engineer contact : akkoyun@me.com

Property of Gunce Akkoyun

PCIe Card Edge Connector

www.github.com/akkoyun/B101

GSM IoT Block Diagram

Seker Mah. Ayyildiz Sok
Silverstar Apt. 7/7
Selcuklu / Konya Türkiye

Copyright 2024 Mehmet Gunce Akkoyun (Commercial Secret)

File : GSM IoT Block Diagram.SchDoc

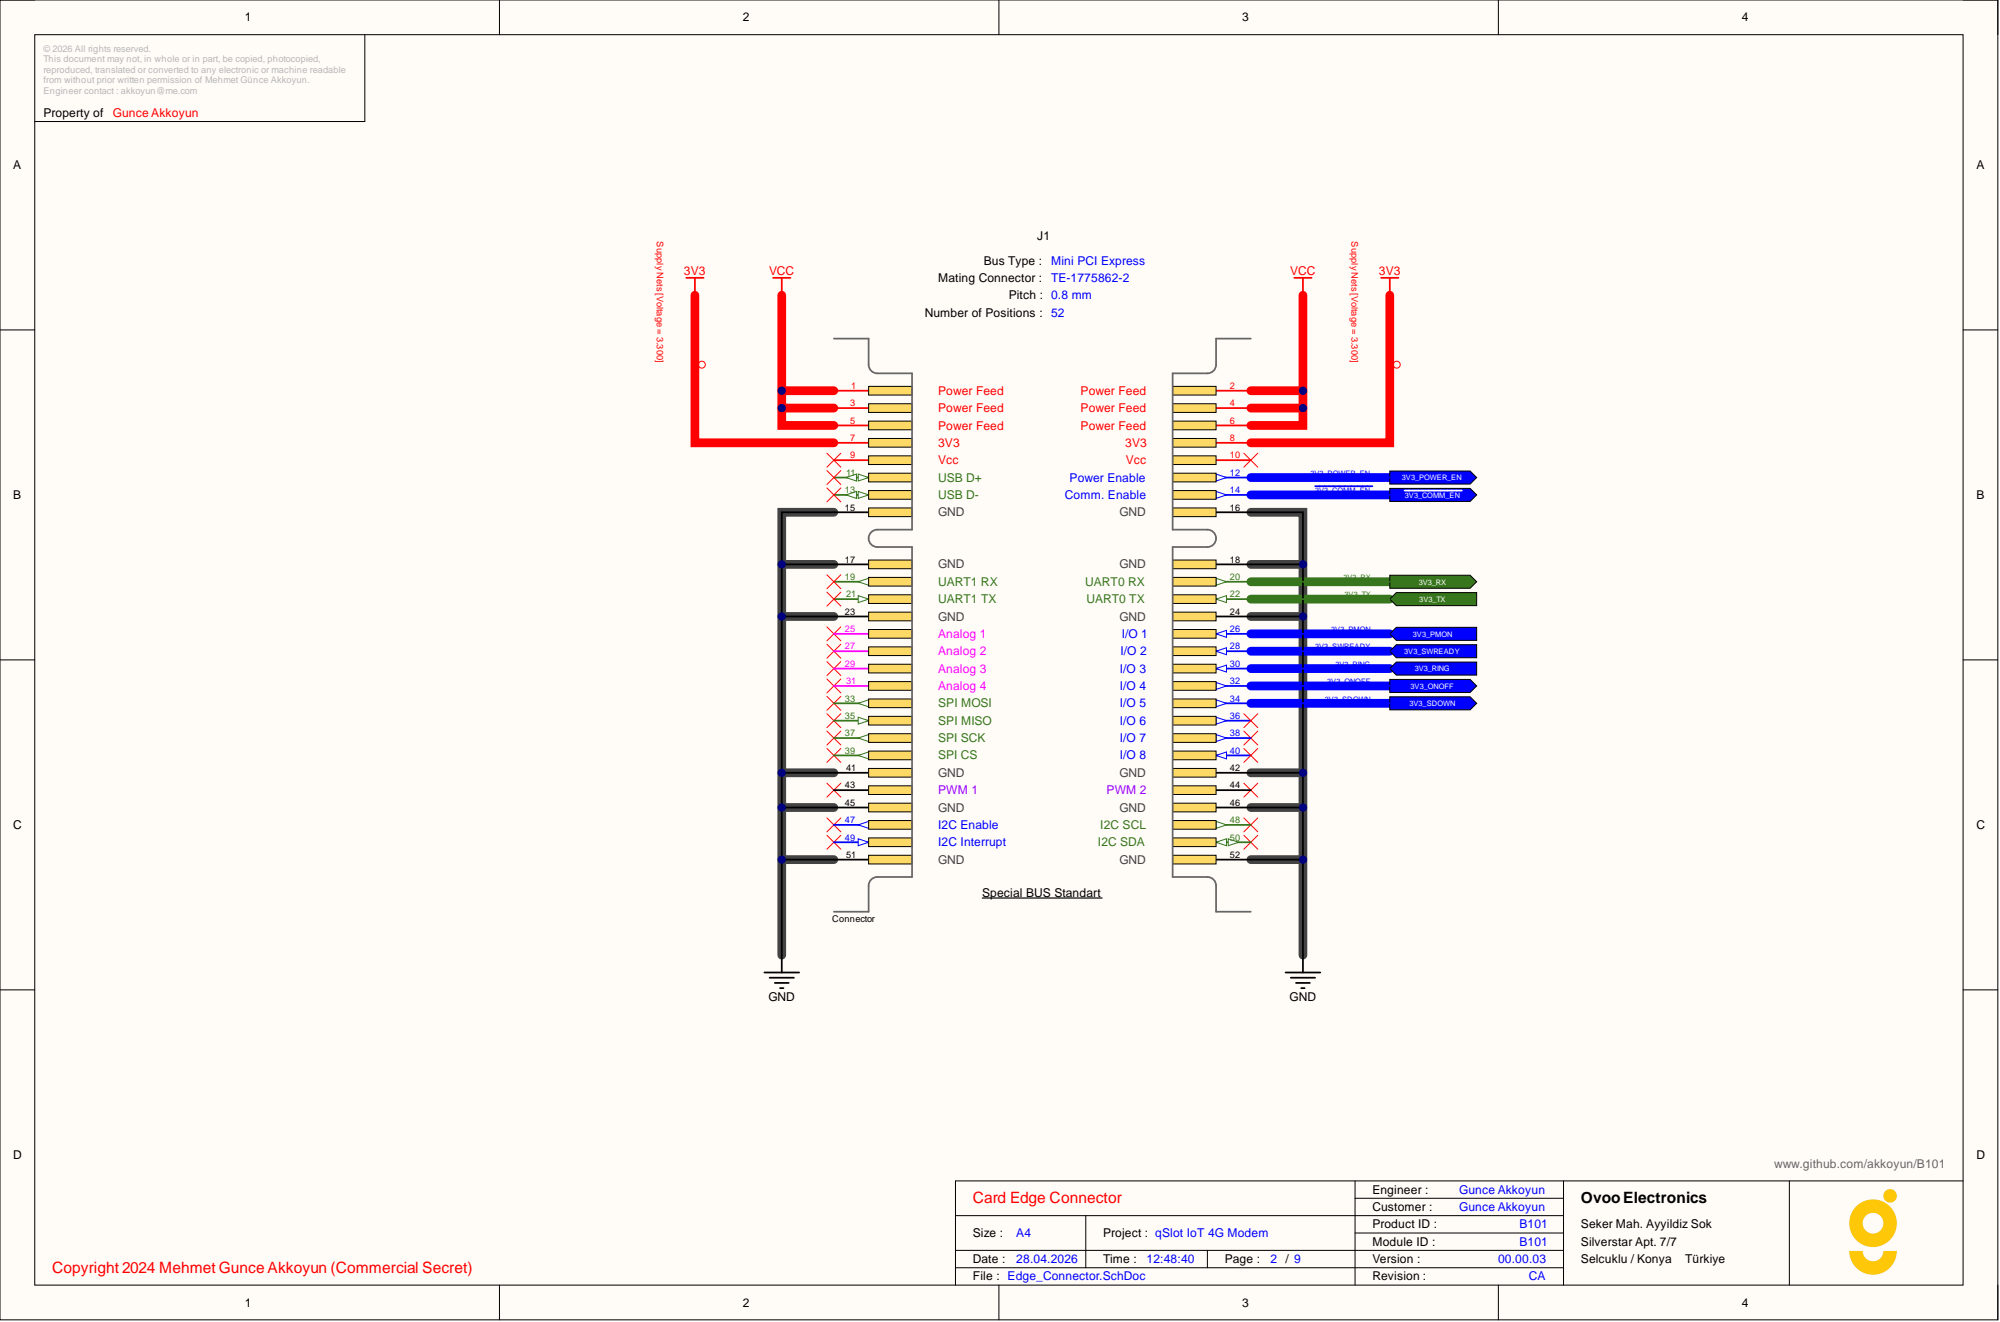
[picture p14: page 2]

Property of Gunce Akkoyun

www.github.com/akkoyun/B101

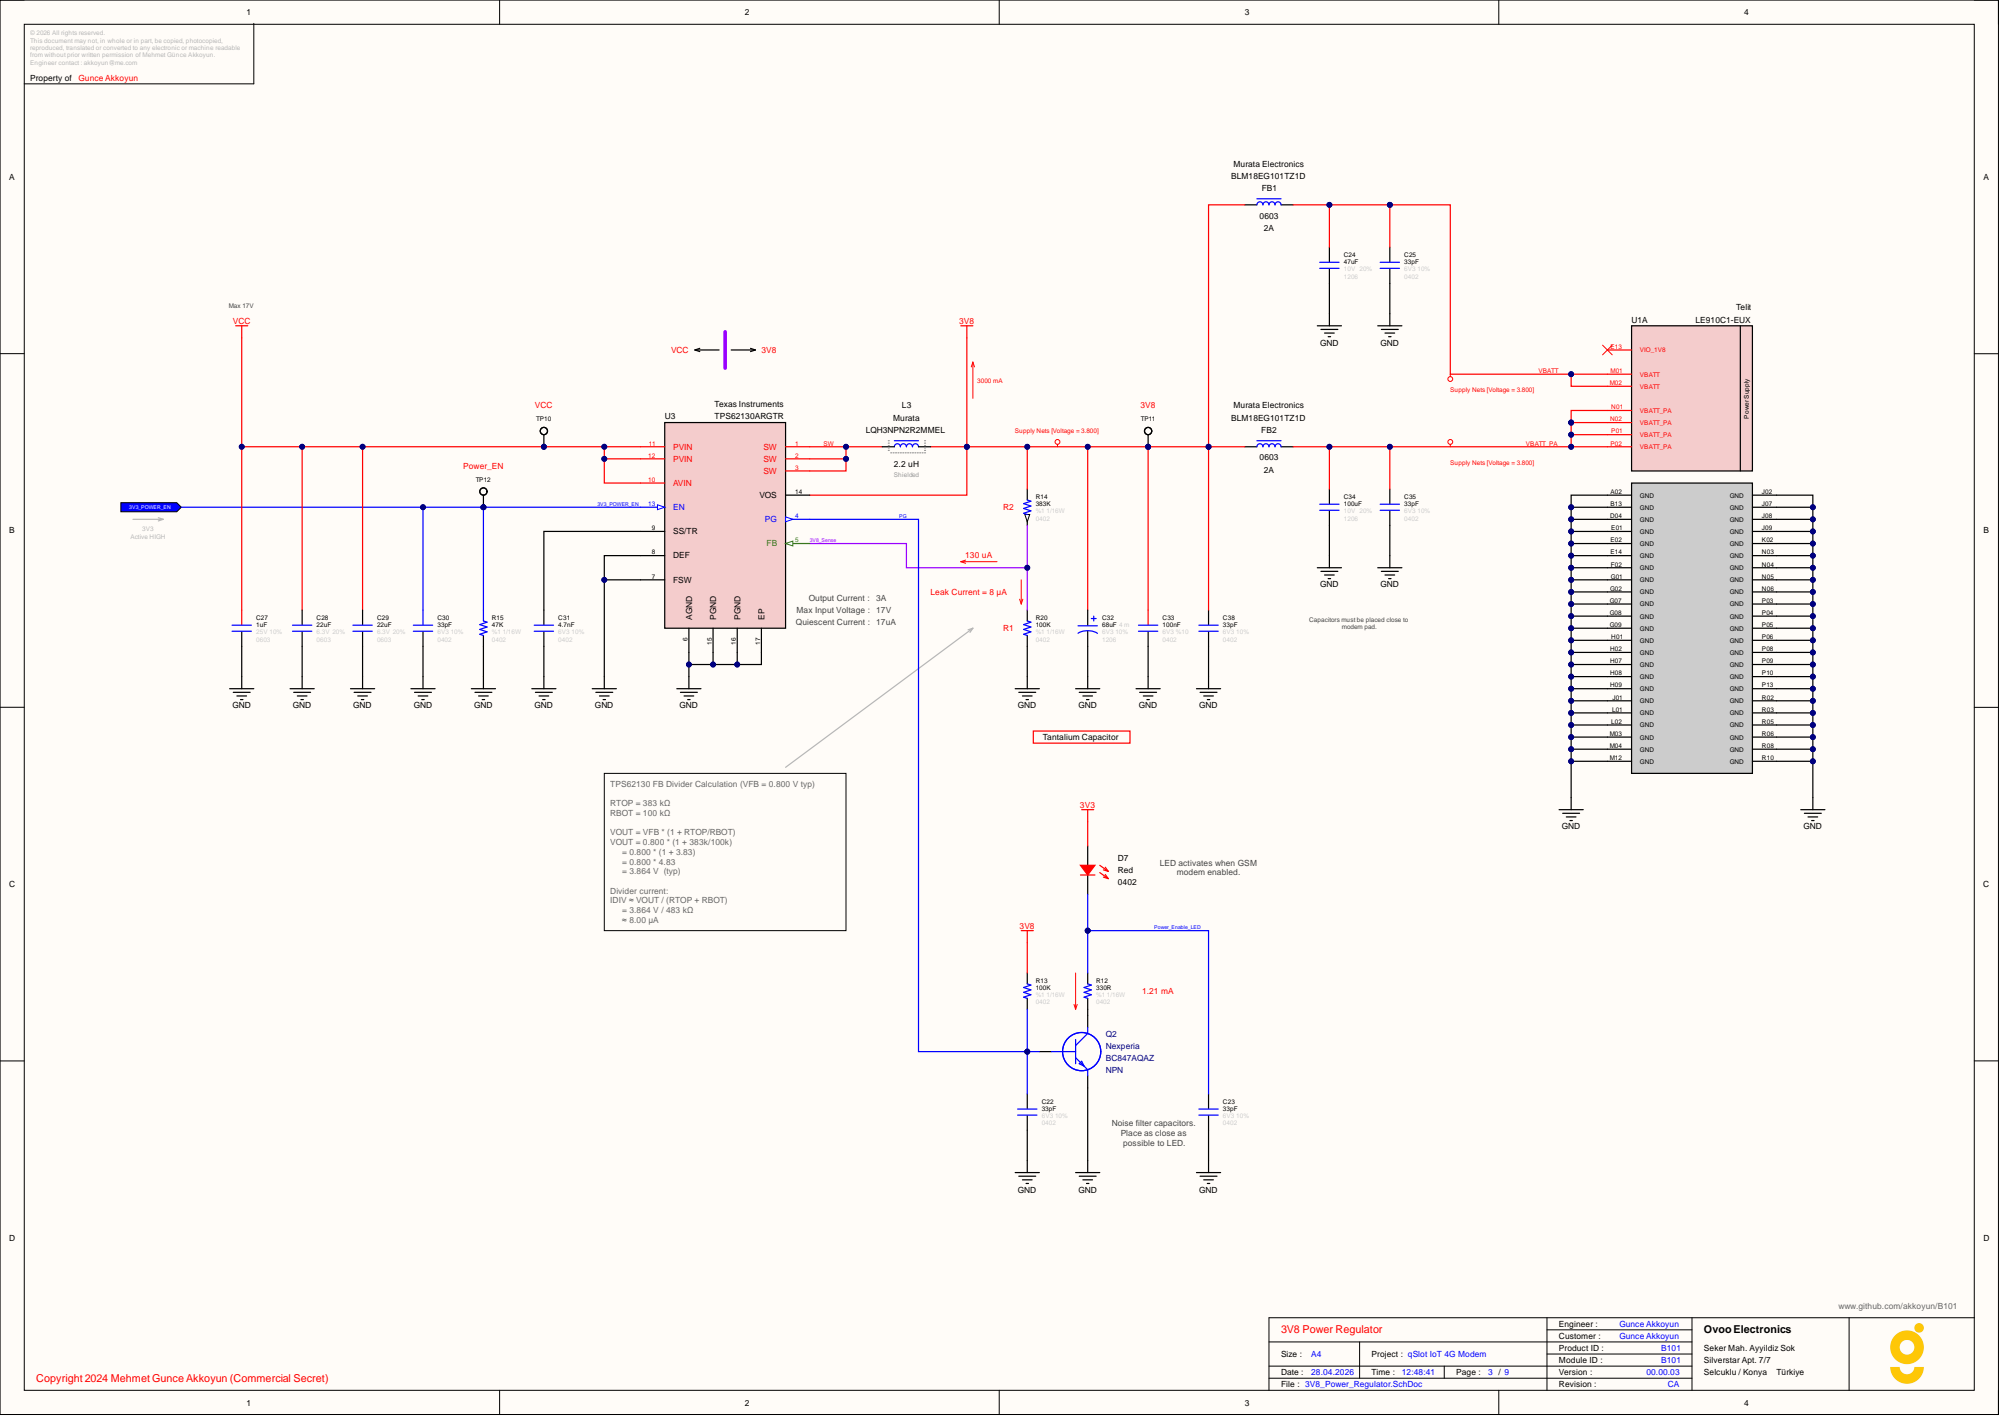
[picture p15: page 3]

Property of Gunce Akkoyun

Capacitors must be placed close to

TPS62130 FB Divider Calculation (VFB = 0.800 V typ)

Divider current:
IDIV ≈ VOUT / (RTOP + RBOT)

Noise filter capacitors.
Place as close as
possible to LED.

www.github.com/akkoyun/B101

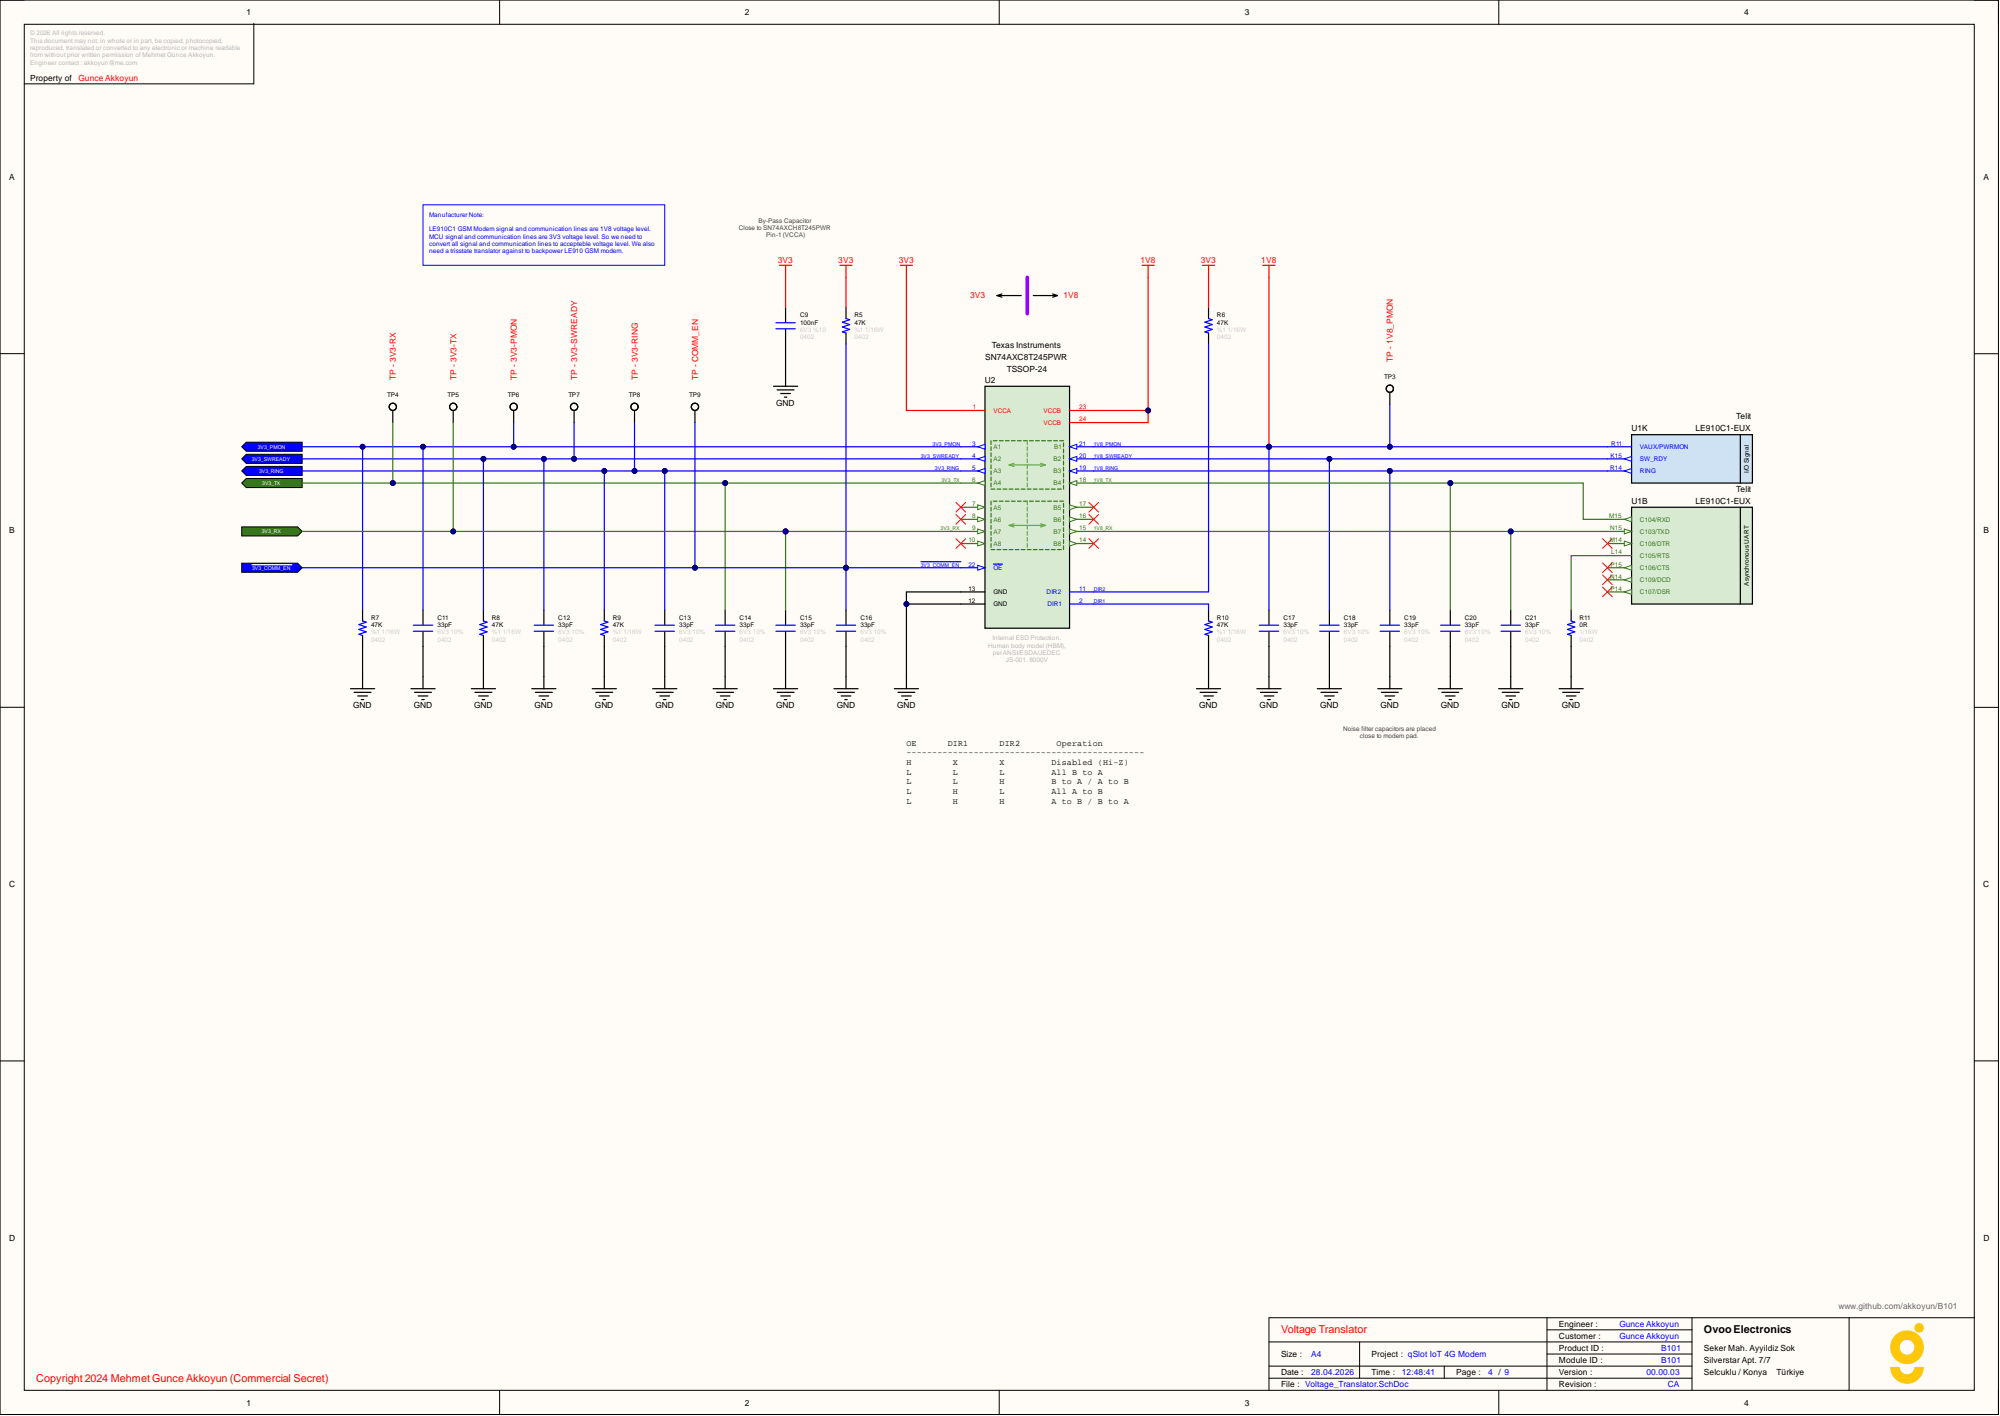
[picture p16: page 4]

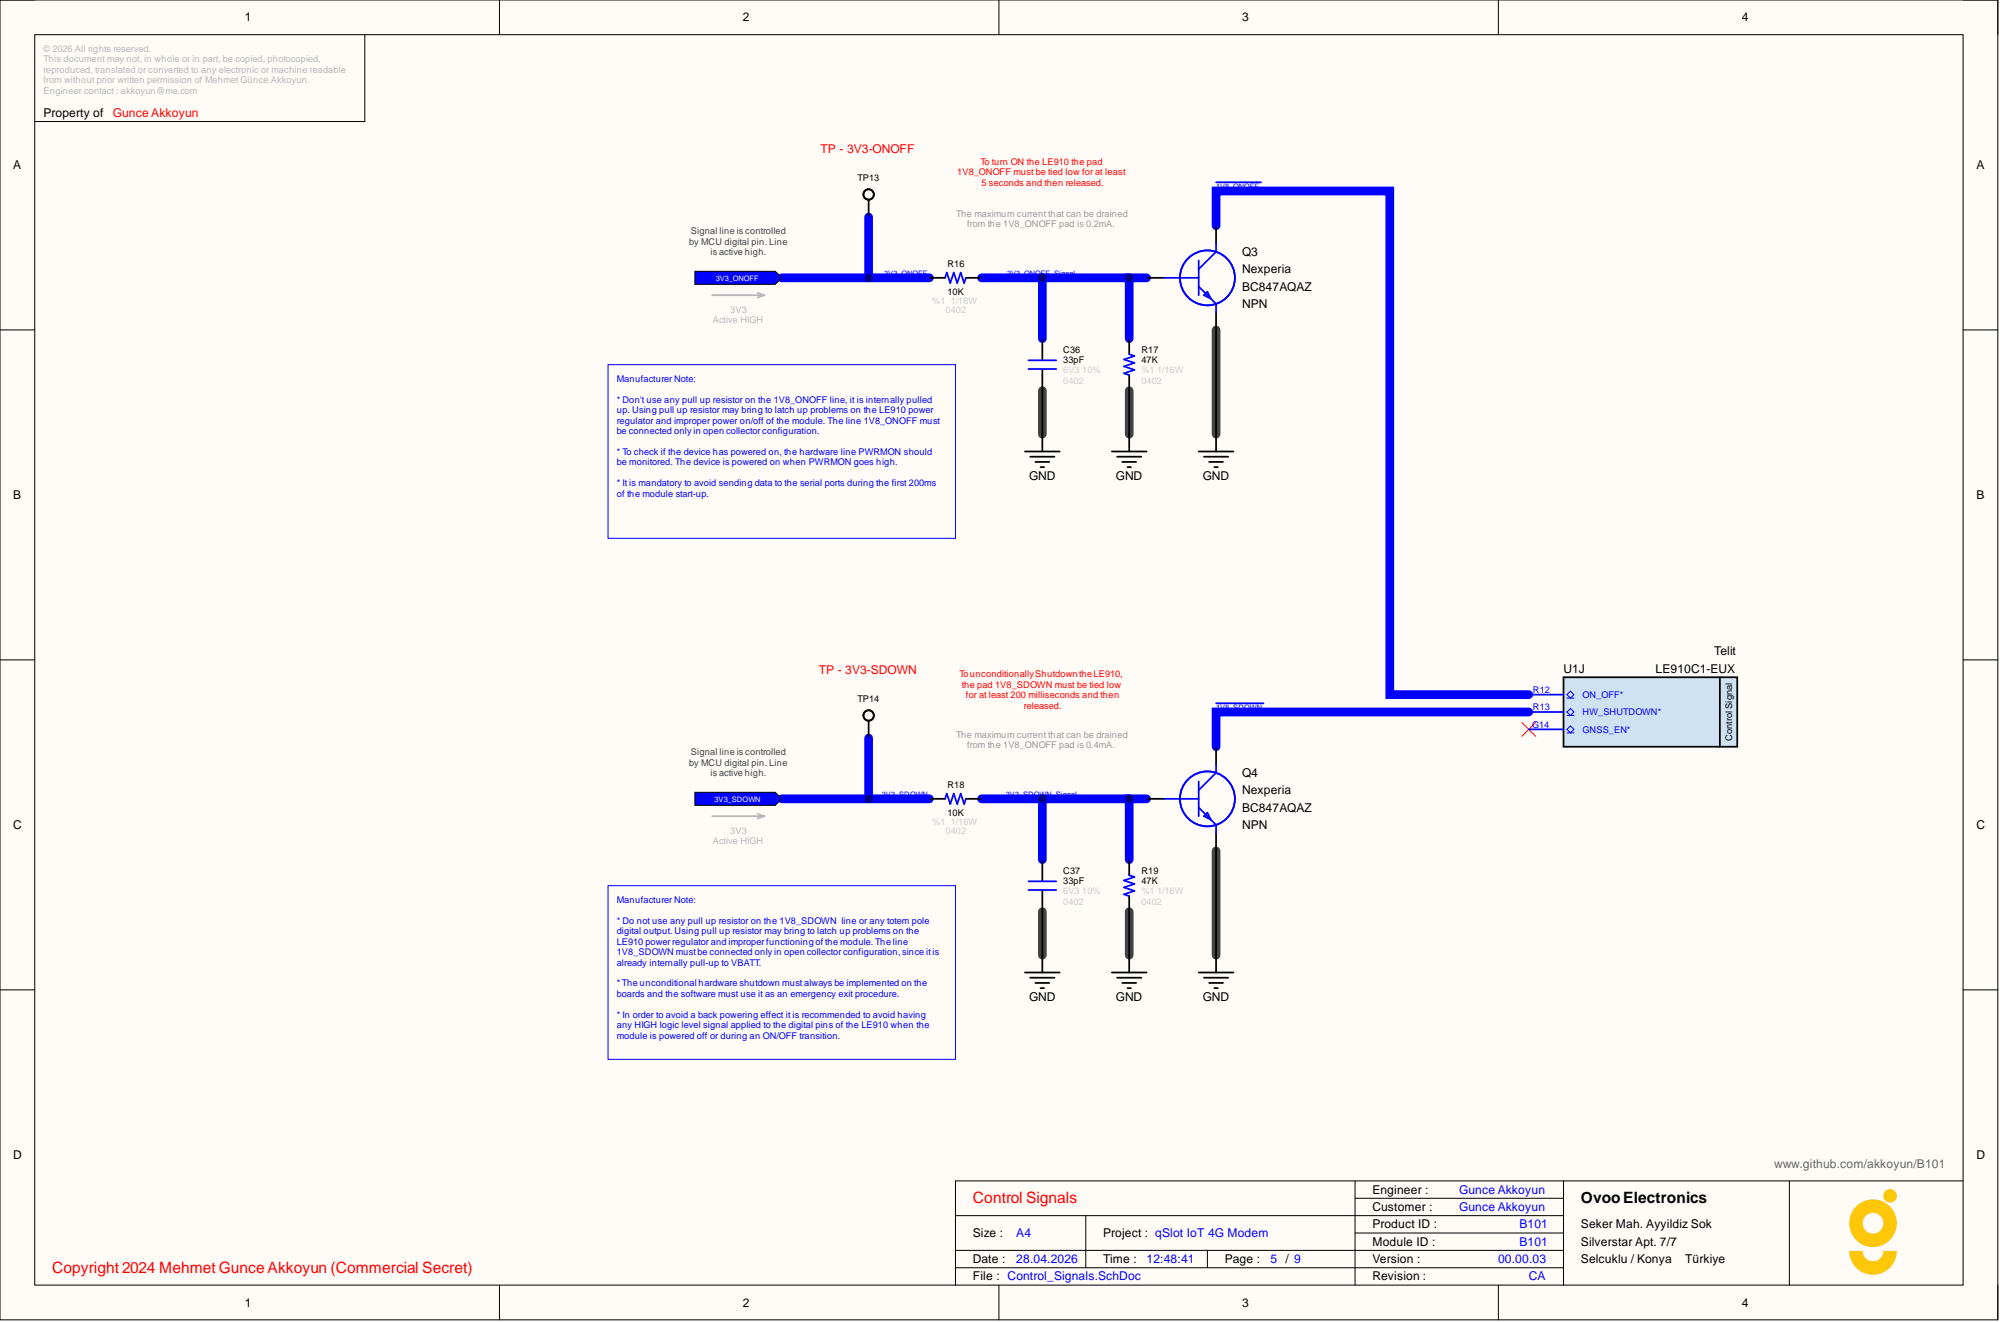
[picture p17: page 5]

Property of Gunce Akkoyun

To turn ON the LE910 the pad
1V8_ONOFF must be tied low for at least
5 seconds and then released.

The maximum current that can be drained
from the 1V8_ONOFF pad is 0.2mA.

Signal line is controlled
by MCU digital pin. Line
is active high.

* Don't use any pull up resistor on the 1V8_ONOFF line, it is internally pulled
up. Using pull up resistor may bring to latch up problems on the LE910 power
regulator and improper power on/off of the module. The line 1V8_ONOFF must
be connected only in open collector configuration.

* To check if the device has powered on, the hardware line PWRMON should
be monitored. The device is powered on when PWRMON goes high.

* It is mandatory to avoid sending data to the serial ports during the first 200ms
of the module start-up.

To unconditionally Shutdown the LE910,
the pad 1V8_SDOWN must be tied low
for at least 200 milliseconds and then

from the 1V8_ONOFF pad is 0.4mA.

* Do not use any pull up resistor on the 1V8_SDOWN line or any totem pole
digital output. Using pull up resistor may bring to latch up problems on the
LE910 power regulator and improper functioning of the module. The line
1V8_SDOWN must be connected only in open collector configuration, since it is
already internally pull-up to VBATT.

* The unconditional hardware shutdown must always be implemented on the
boards and the software must use it as an emergency exit procedure.

* In order to avoid a back powering effect it is recommended to avoid having
any HIGH logic level signal applied to the digital pins of the LE910 when the
module is powered off or during an ON/OFF transition.

www.github.com/akkoyun/B101

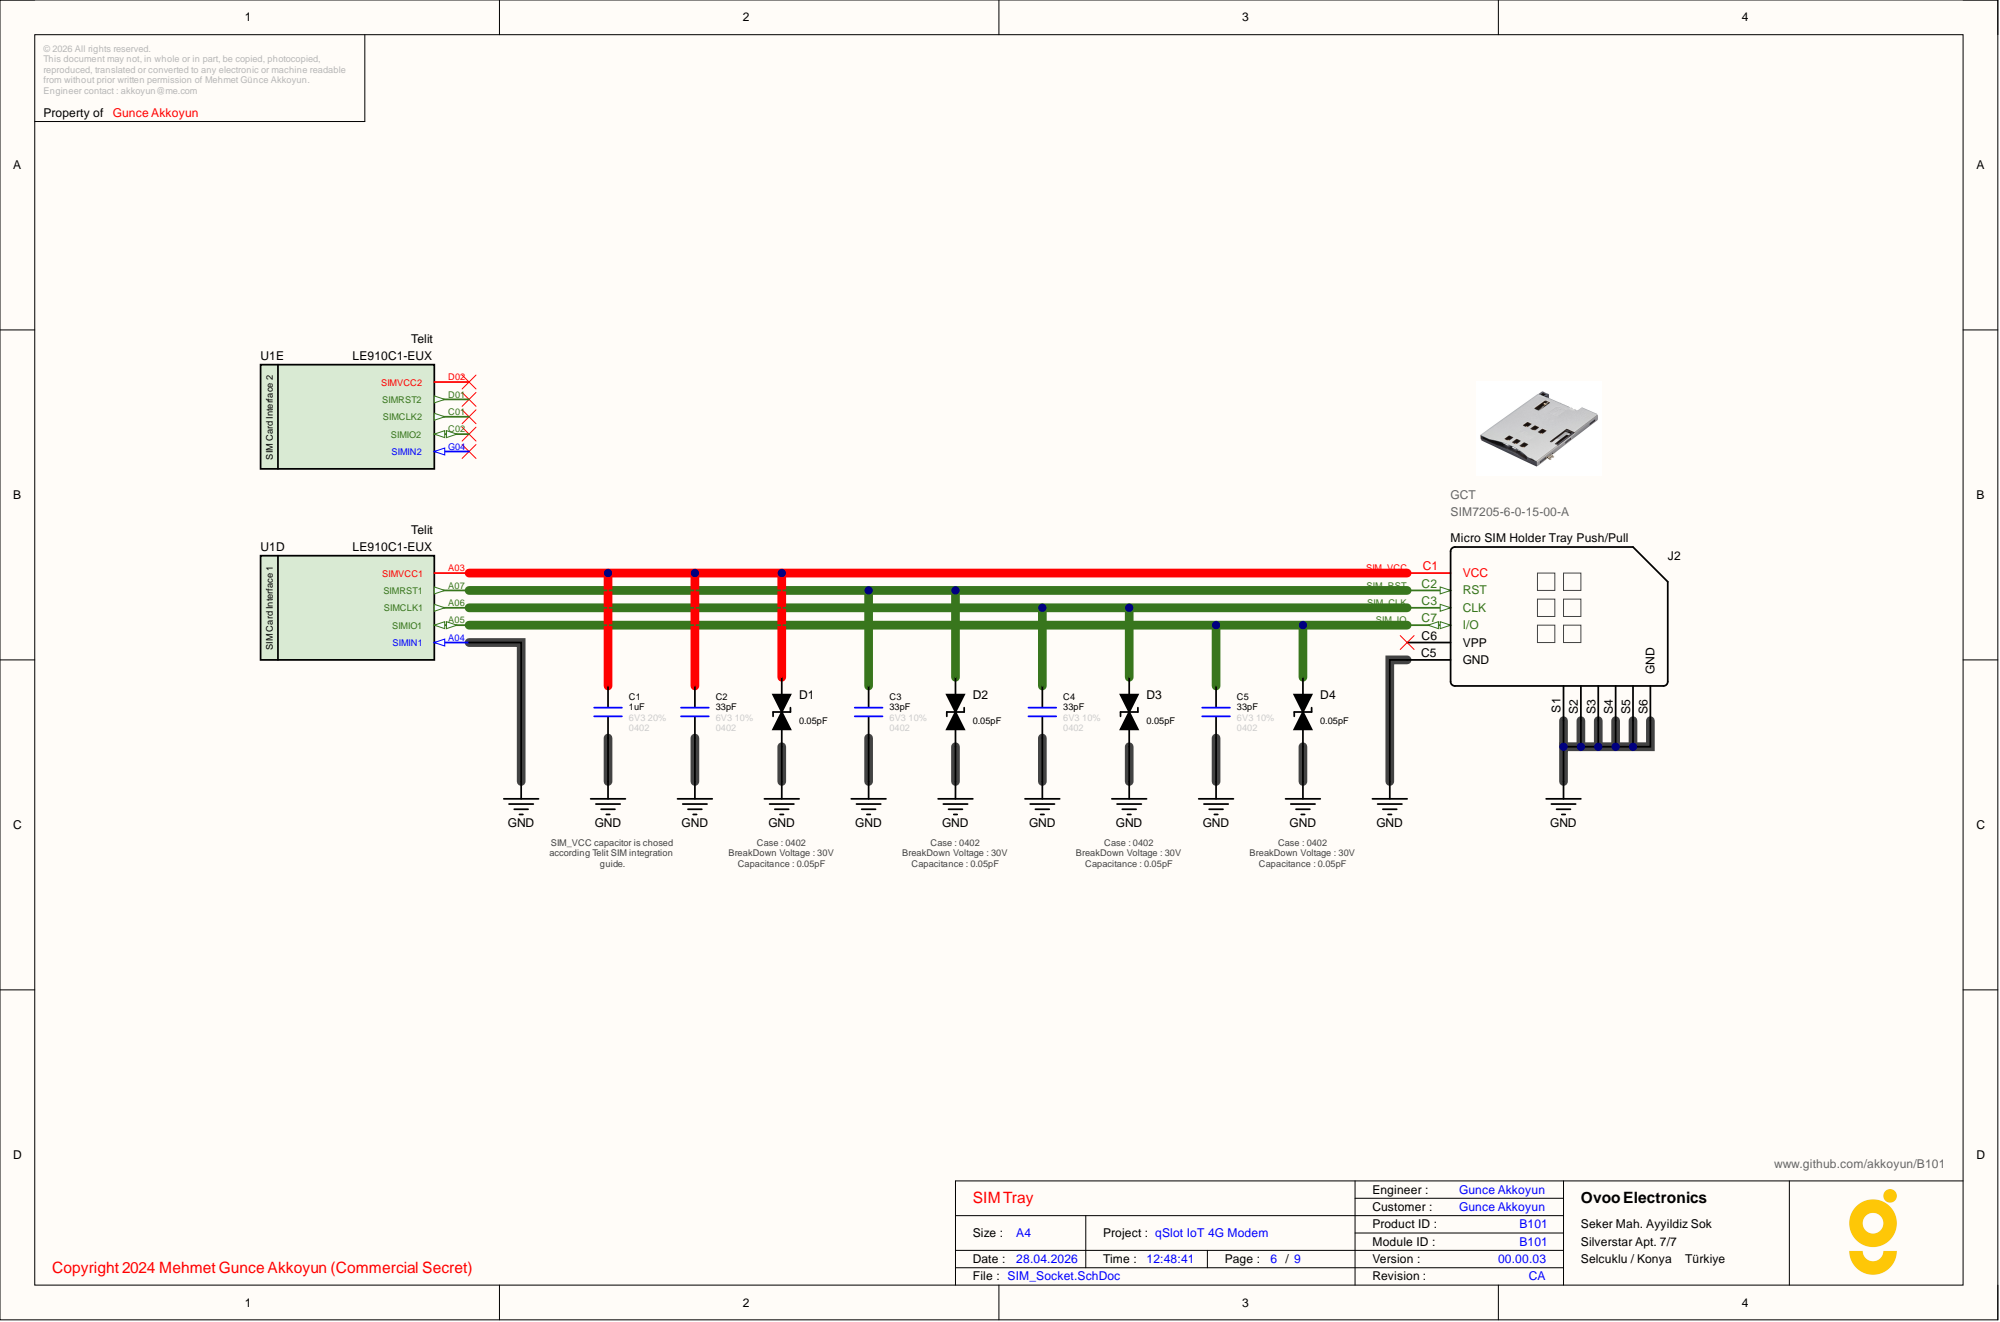
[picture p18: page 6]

A05 | | M_CLK SIM_IO

A04 | | | VPP C6

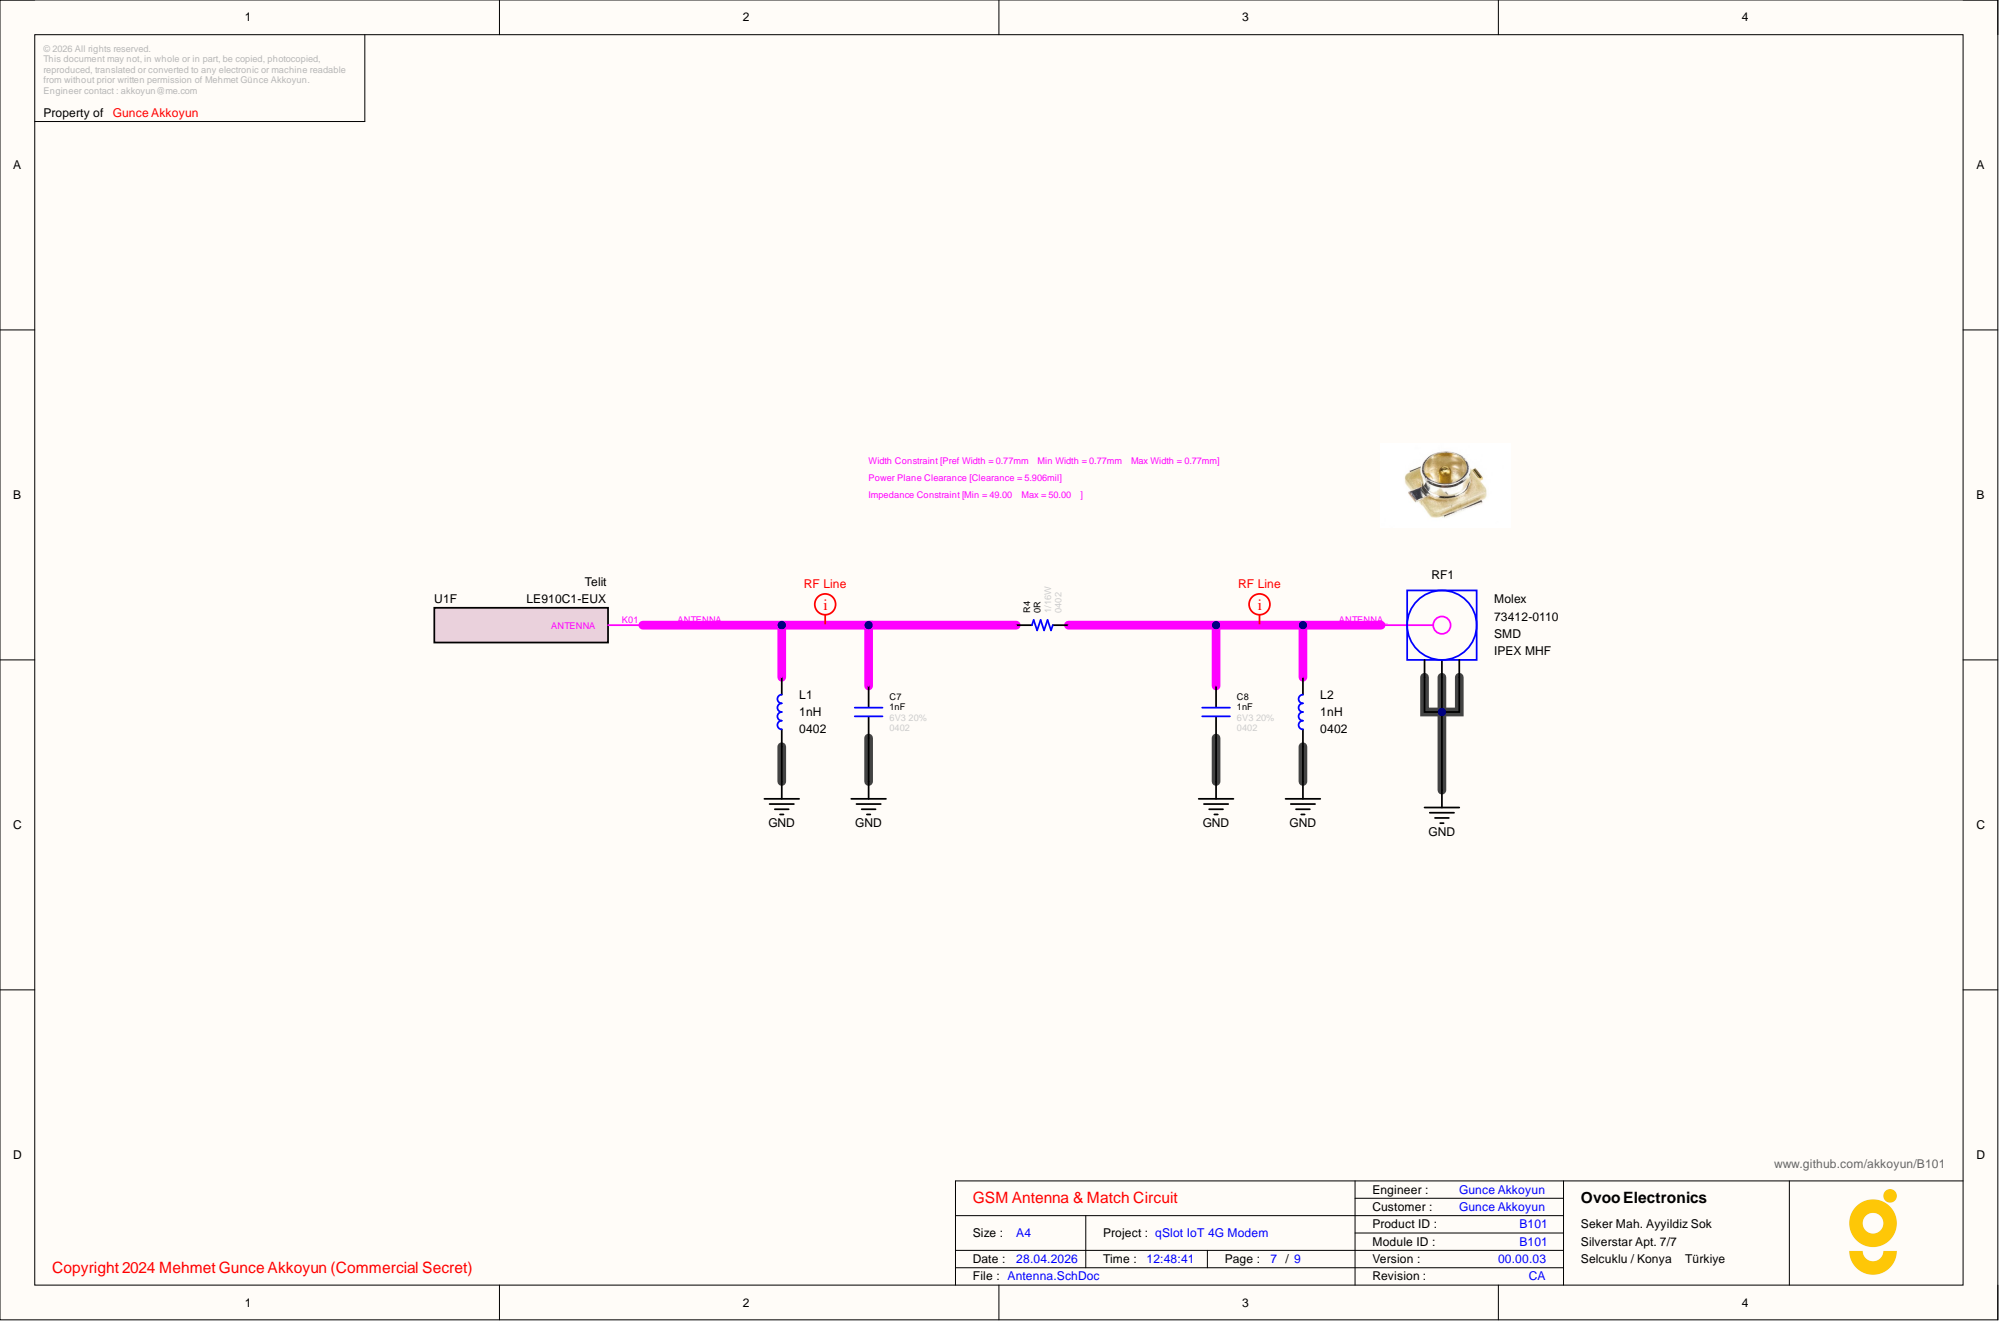
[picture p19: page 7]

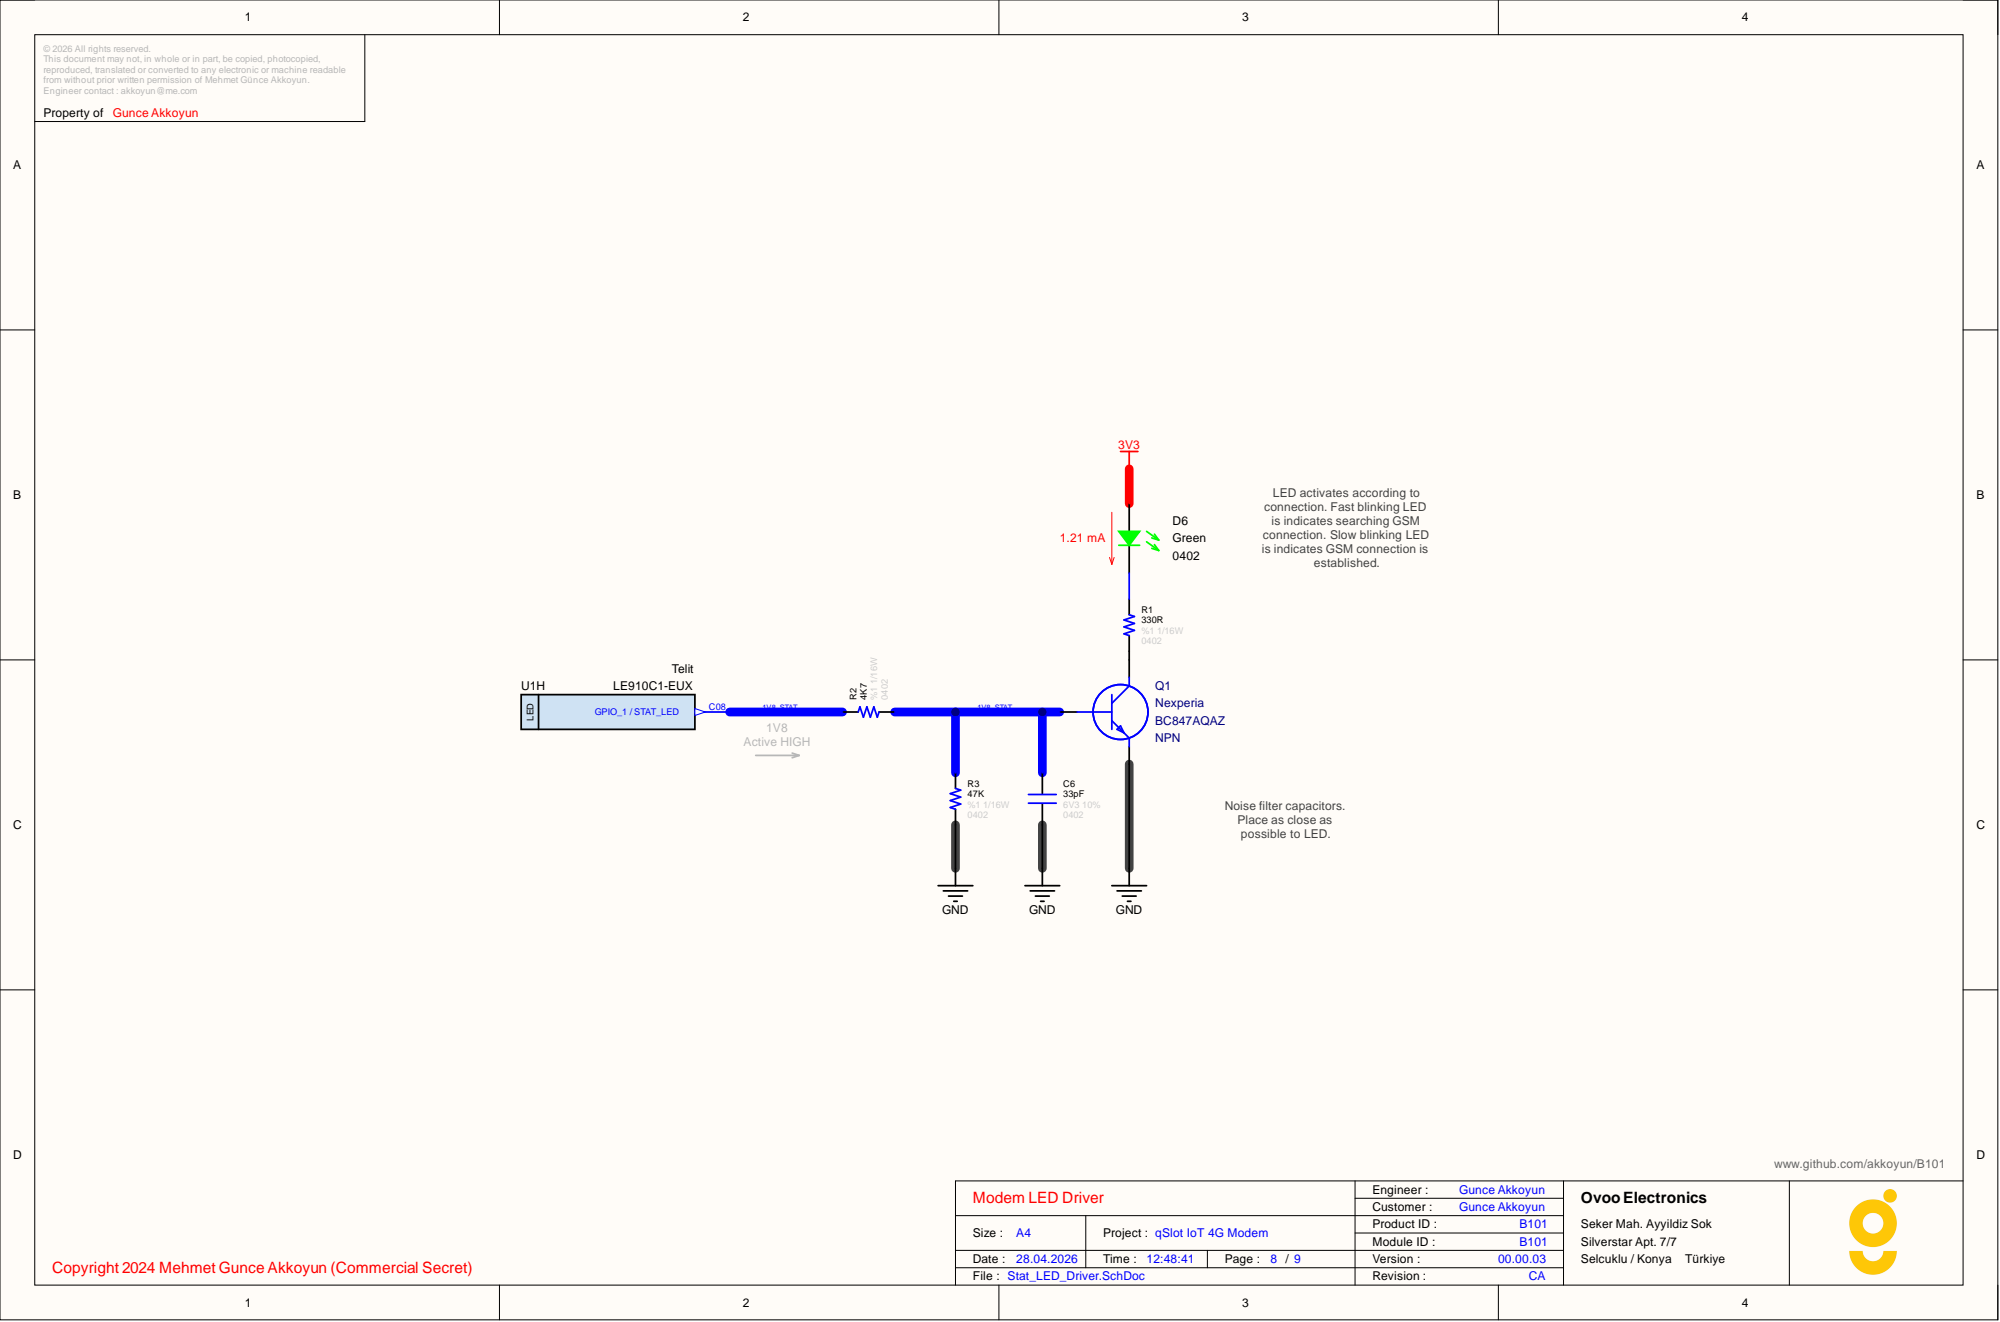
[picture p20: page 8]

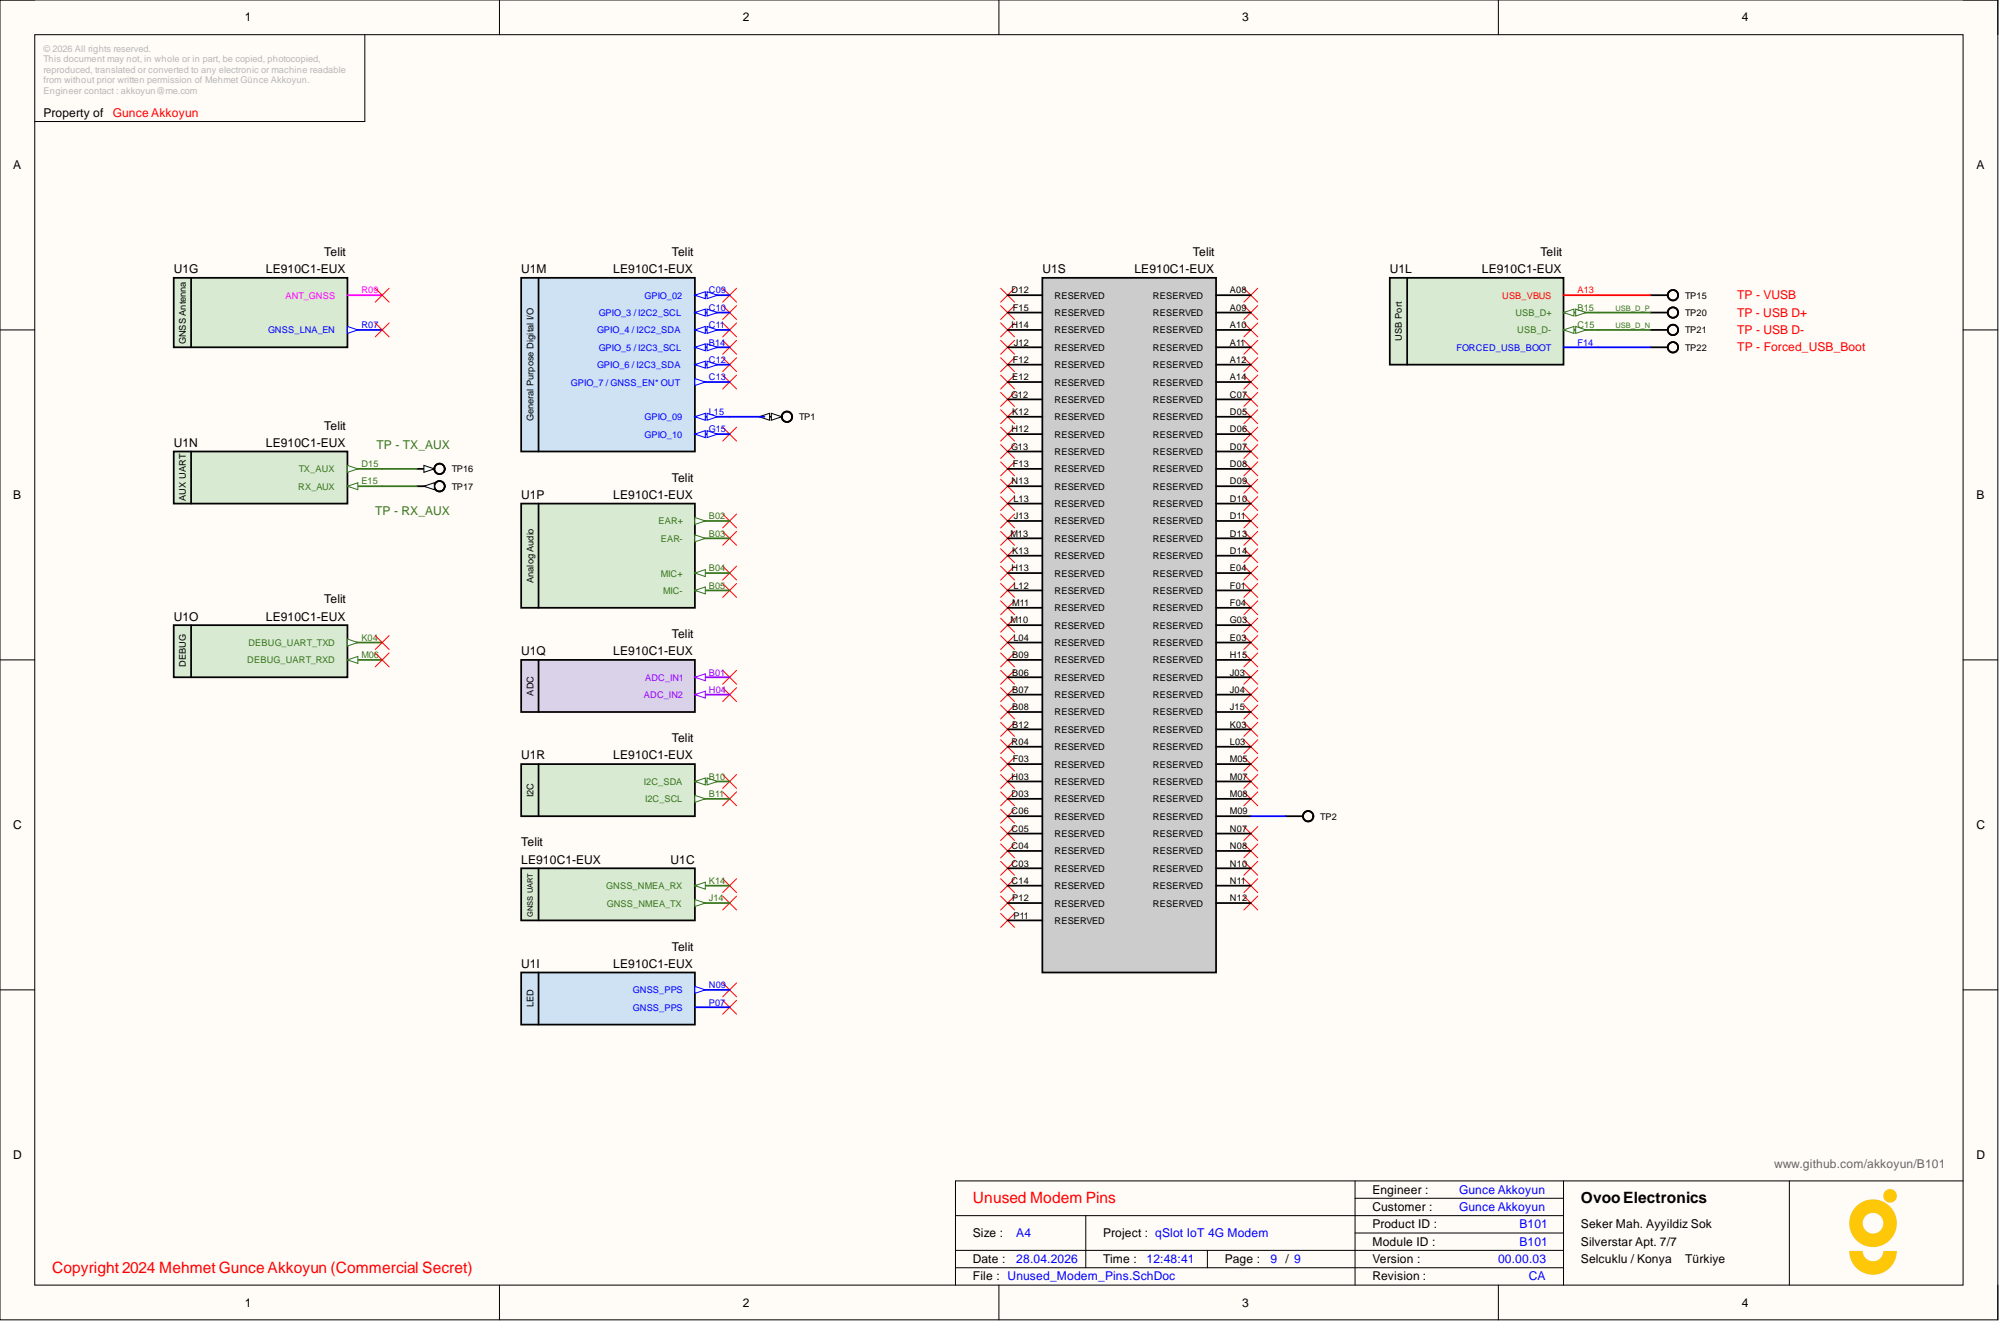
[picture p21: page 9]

TX_A U X R X_A U X | 0C1-EUX Telit U1 P LE9 1

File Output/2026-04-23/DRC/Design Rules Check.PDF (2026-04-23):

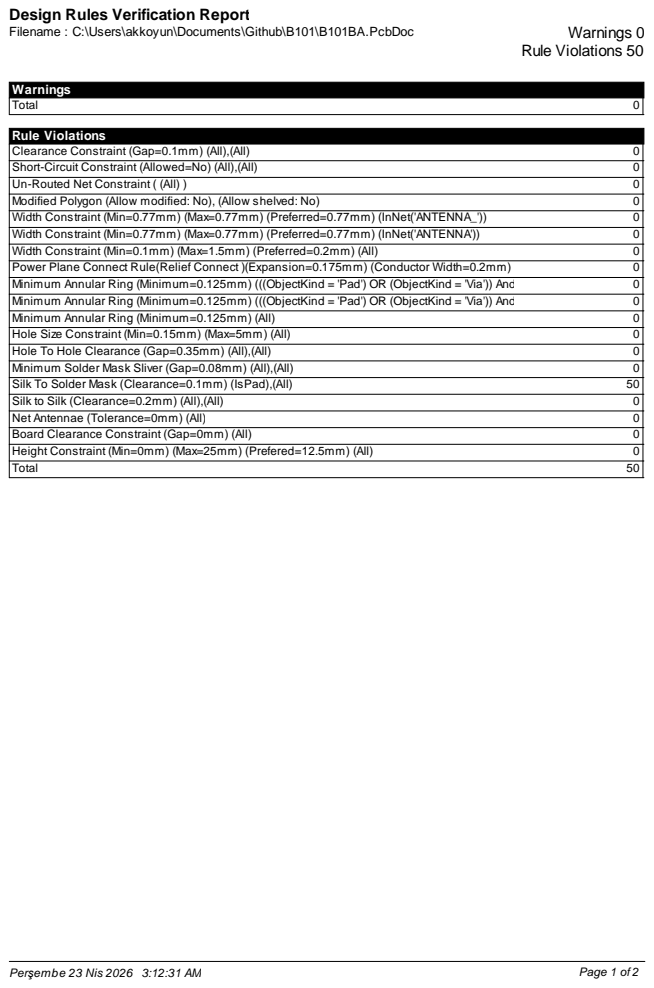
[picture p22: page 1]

Design Rules Verification Report

Rule Violations
Minimum Annular Ring (Minimum=0.125mm) (((ObjectKind =

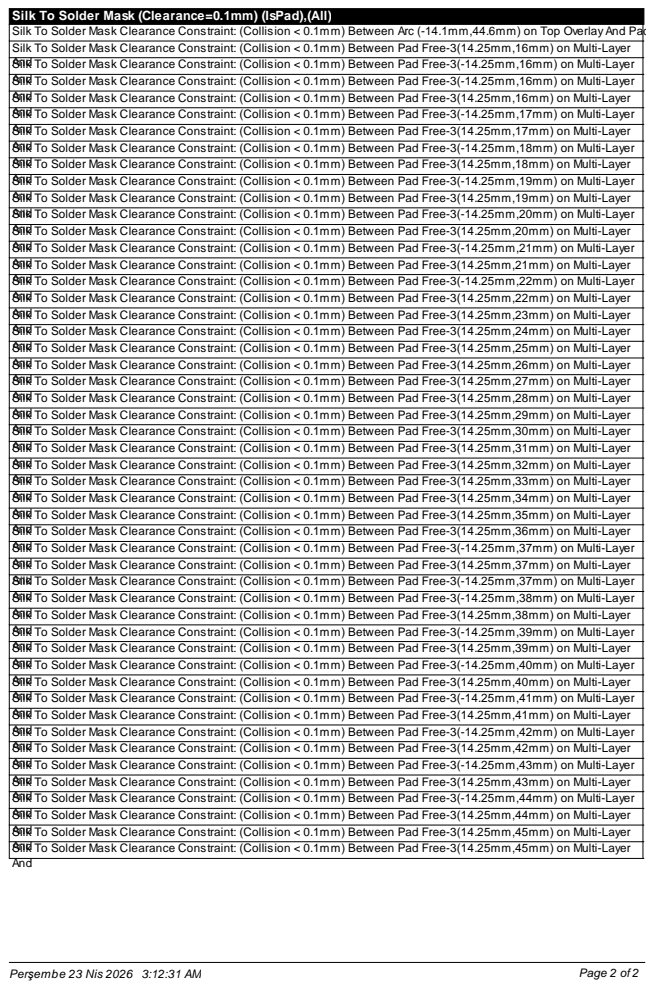
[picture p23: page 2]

Silk To Solder Mask (Clearance=0.1mm) (IsPad),(All)
Silk To Solder Mask Clearance Constraint: (Collision < 0.1mm) Between Arc (-14.1mm,44.6mm) on Top OverlayAnd Pad
Silk To Solder Mask Clearance Constraint: (Collision < 0.1mm) Between Pad Free-3(14.25mm,16mm) on Multi-Layer
ASinldk To Solder Mask Clearance Constraint: (Collision < 0.1mm) Between Pad Free-3(-14.25mm,16mm) on Multi-Layer
ASinldk To Solder Mask Clearance Constraint: (Collision < 0.1mm) Between Pad Free-3(14.25mm,16mm) on Multi-Layer
ASinldk To Solder Mask Clearance Constraint: (Collision < 0.1mm) Between Pad Free-3(-14.25mm,17mm) on Multi-Layer
ASinldk To Solder Mask Clearance Constraint: (Collision < 0.1mm) Between Pad Free-3(14.25mm,17mm) on Multi-Layer
ASinldk To Solder Mask Clearance Constraint: (Collision < 0.1mm) Between Pad Free-3(-14.25mm,18mm) on Multi-Layer
ASinldk To Solder Mask Clearance Constraint: (Collision < 0.1mm) Between Pad Free-3(14.25mm,18mm) on Multi-Layer
ASinldk To Solder Mask Clearance Constraint: (Collision < 0.1mm) Between Pad Free-3(-14.25mm,19mm) on Multi-Layer
ASinldk To Solder Mask Clearance Constraint: (Collision < 0.1mm) Between Pad Free-3(14.25mm,19mm) on Multi-Layer
ASinldk To Solder Mask Clearance Constraint: (Collision < 0.1mm) Between Pad Free-3(-14.25mm,20mm) on Multi-Layer
ASinldk To Solder Mask Clearance Constraint: (Collision < 0.1mm) Between Pad Free-3(14.25mm,20mm) on Multi-Layer
ASinldk To Solder Mask Clearance Constraint: (Collision < 0.1mm) Between Pad Free-3(-14.25mm,21mm) on Multi-Layer
ASinldk To Solder Mask Clearance Constraint: (Collision < 0.1mm) Between Pad Free-3(14.25mm,21mm) on Multi-Layer
ASinldk To Solder Mask Clearance Constraint: (Collision < 0.1mm) Between Pad Free-3(-14.25mm,22mm) on Multi-Layer
ASinldk To Solder Mask Clearance Constraint: (Collision < 0.1mm) Between Pad Free-3(14.25mm,22mm) on Multi-Layer
ASinldk To Solder Mask Clearance Constraint: (Collision < 0.1mm) Between Pad Free-3(14.25mm,23mm) on Multi-Layer
ASinldk To Solder Mask Clearance Constraint: (Collision < 0.1mm) Between Pad Free-3(14.25mm,24mm) on Multi-Layer
ASinldk To Solder Mask Clearance Constraint: (Collision < 0.1mm) Between Pad Free-3(14.25mm,25mm) on Multi-Layer
ASinldk To Solder Mask Clearance Constraint: (Collision < 0.1mm) Between Pad Free-3(14.25mm,26mm) on Multi-Layer
ASinldk To Solder Mask Clearance Constraint: (Collision < 0.1mm) Between Pad Free-3(14.25mm,27mm) on Multi-Layer
ASinldk To Solder Mask Clearance Constraint: (Collision < 0.1mm) Between Pad Free-3(14.25mm,28mm) on Multi-Layer
ASinldk To Solder Mask Clearance Constraint: (Collision < 0.1mm) Between Pad Free-3(14.25mm,29mm) on Multi-Layer
ASinldk To Solder Mask Clearance Constraint: (Collision < 0.1mm) Between Pad Free-3(14.25mm,30mm) on Multi-Layer
ASinldk To Solder Mask Clearance Constraint: (Collision < 0.1mm) Between Pad Free-3(14.25mm,31mm) on Multi-Layer
ASinldk To Solder Mask Clearance Constraint: (Collision < 0.1mm) Between Pad Free-3(14.25mm,32mm) on Multi-Layer
ASinldk To Solder Mask Clearance Constraint: (Collision < 0.1mm) Between Pad Free-3(14.25mm,33mm) on Multi-Layer
ASinldk To Solder Mask Clearance Constraint: (Collision < 0.1mm) Between Pad Free-3(14.25mm,34mm) on Multi-Layer
ASinldk To Solder Mask Clearance Constraint: (Collision < 0.1mm) Between Pad Free-3(14.25mm,35mm) on Multi-Layer
ASinldk To Solder Mask Clearance Constraint: (Collision < 0.1mm) Between Pad Free-3(14.25mm,36mm) on Multi-Layer
ASinldk To Solder Mask Clearance Constraint: (Collision < 0.1mm) Between Pad Free-3(-14.25mm,37mm) on Multi-Layer
ASinldk To Solder Mask Clearance Constraint: (Collision < 0.1mm) Between Pad Free-3(14.25mm,37mm) on Multi-Layer
ASinldk To Solder Mask Clearance Constraint: (Collision < 0.1mm) Between Pad Free-3(-14.25mm,38mm) on Multi-Layer
ASinldk To Solder Mask Clearance Constraint: (Collision < 0.1mm) Between Pad Free-3(14.25mm,38mm) on Multi-Layer
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

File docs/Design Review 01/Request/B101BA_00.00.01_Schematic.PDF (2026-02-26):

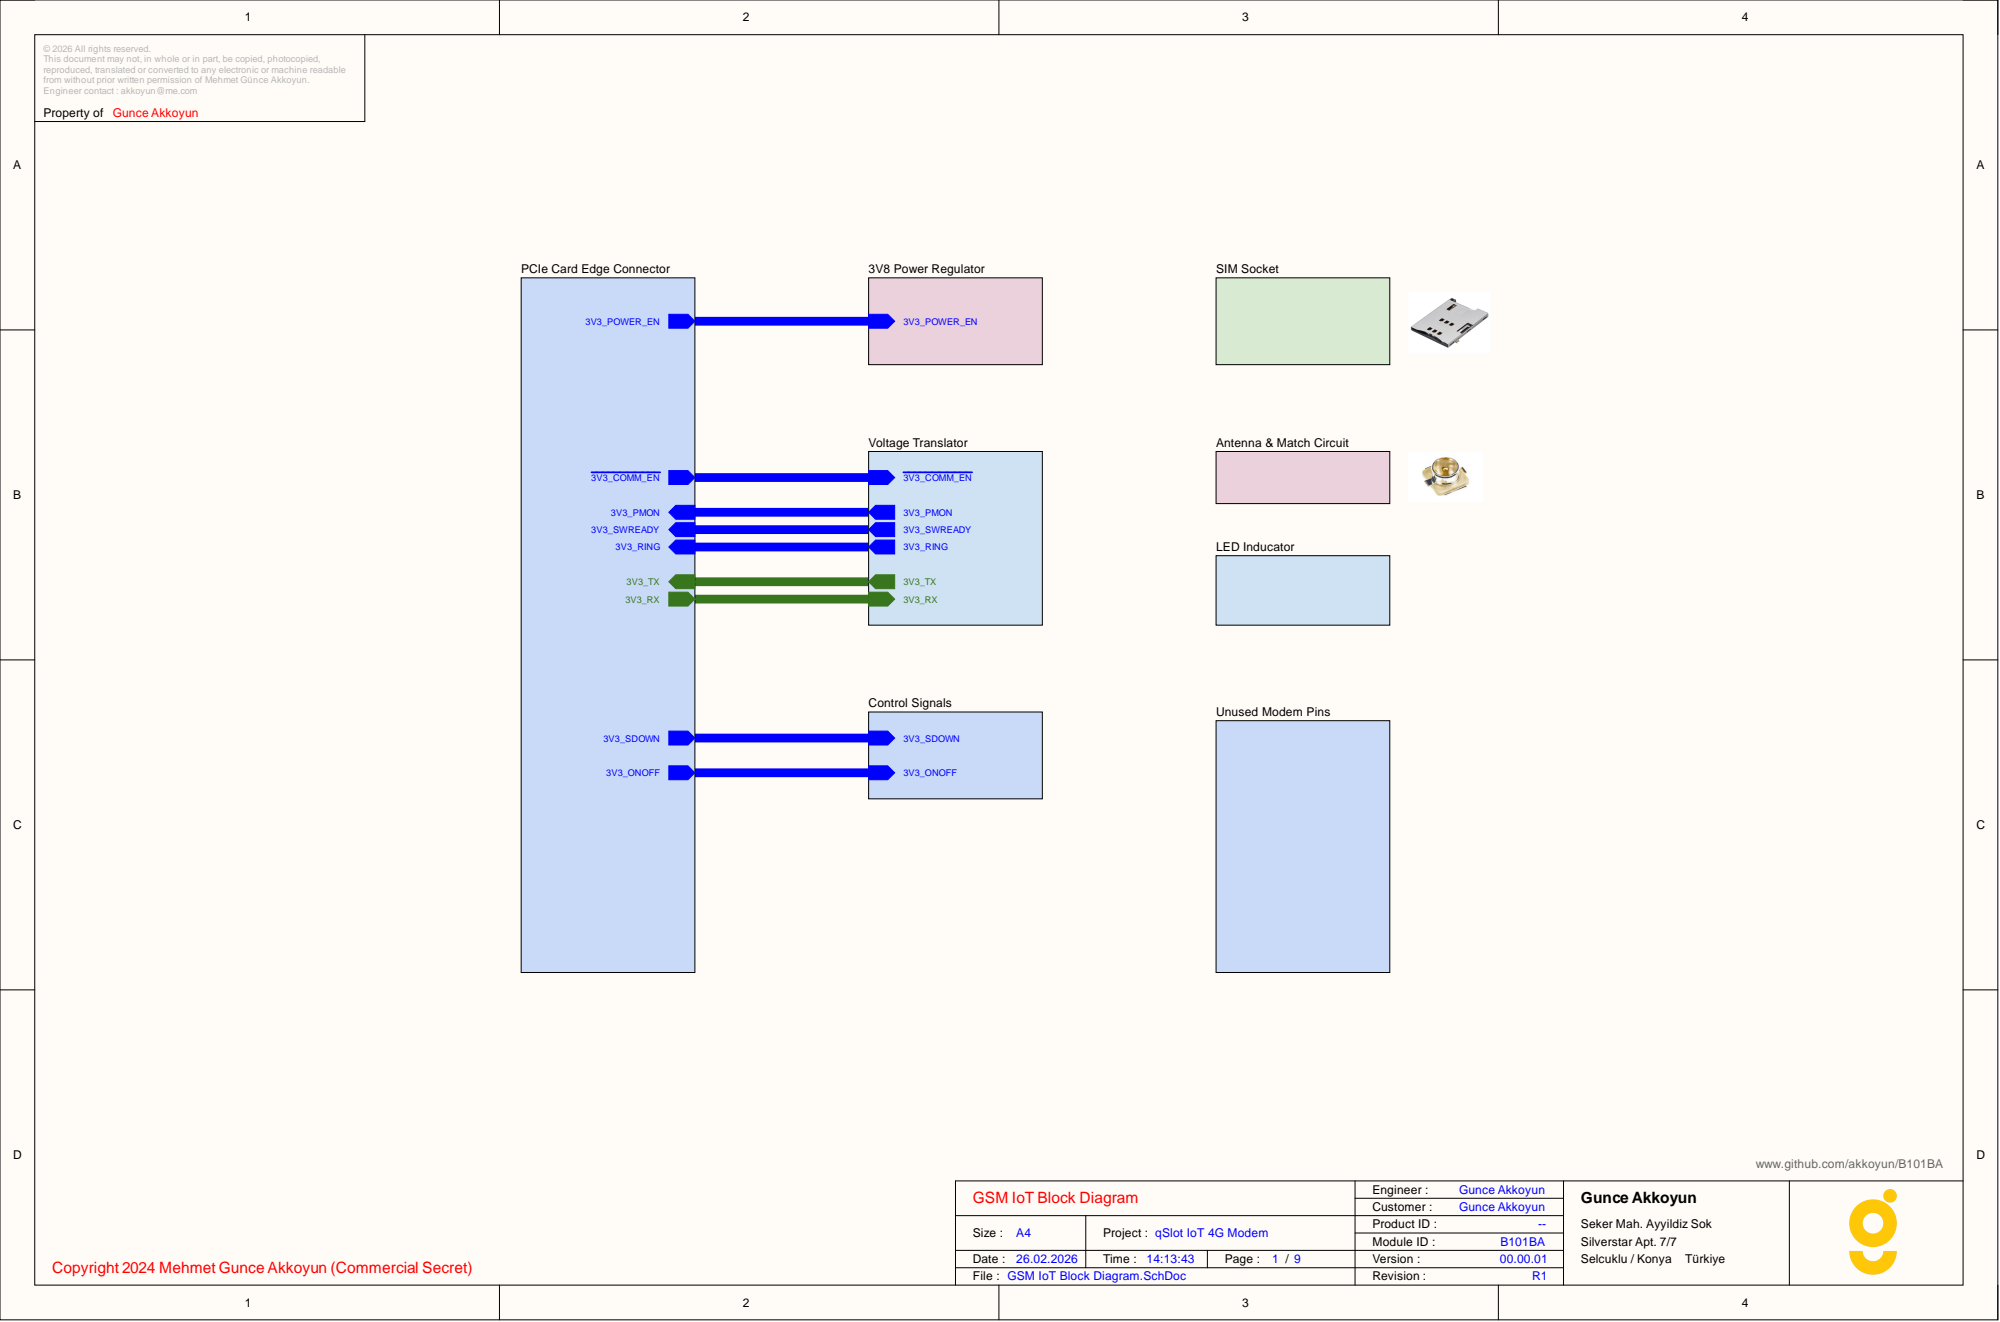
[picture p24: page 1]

© 2026 All rights reserved.
This document may not, in whole or in part, be copied, photocopied,
reproduced, translated or converted to any electronic or machine readable
from without prior written permission of Mehmet Günce Akkoyun.
Engineer contact : akkoyun@me.com

Property of Gunce Akkoyun

PCIe Card Edge Connector

www.github.com/akkoyun/B101BA

GSM IoT Block Diagram

Seker Mah. Ayyildiz Sok
Silverstar Apt. 7/7
Selcuklu / Konya Türkiye

Copyright 2024 Mehmet Gunce Akkoyun (Commercial Secret)

File : GSM IoT Block Diagram.SchDoc


Property of Gunce Akkoyun

www.github.com/akkoyun/B101BA


Property of Gunce Akkoyun

Capacitors must be placed close to

TPS62130 FB Divider Calculation (VFB = 0.800 V typ)

Divider current:
IDIV ≈ VOUT / (RTOP + RBOT)

Noise filter capacitors.
Place as close as
possible to LED.

www.github.com/akkoyun/B101BA



Property of Gunce Akkoyun

To turn ON the LE910 the pad
1V8_ONOFF must be tied low for at least
5 seconds and then released.

The maximum current that can be drained
from the 1V8_ONOFF pad is 0.2mA.

Signal line is controlled
by MCU digital pin. Line
is active high.

* Don't use any pull up resistor on the 1V8_ONOFF line, it is internally pulled
up. Using pull up resistor may bring to latch up problems on the LE910 power
regulator and improper power on/off of the module. The line 1V8_ONOFF must
be connected only in open collector configuration.

* To check if the device has powered on, the hardware line PWRMON should
be monitored. The device is powered on when PWRMON goes high.

* It is mandatory to avoid sending data to the serial ports during the first 200ms
of the module start-up.

To unconditionally Shutdown the LE910,
the pad 1V8_SDOWN must be tied low
for at least 200 milliseconds and then

from the 1V8_ONOFF pad is 0.4mA.

* Do not use any pull up resistor on the 1V8_SDOWN line or any totem pole
digital output. Using pull up resistor may bring to latch up problems on the
LE910 power regulator and improper functioning of the module. The line
1V8_SDOWN must be connected only in open collector configuration, since it is
already internally pull-up to VBATT.

* The unconditional hardware shutdown must always be implemented on the
boards and the software must use it as an emergency exit procedure.

* In order to avoid a back powering effect it is recommended to avoid having
any HIGH logic level signal applied to the digital pins of the LE910 when the
module is powered off or during an ON/OFF transition.

www.github.com/akkoyun/B101BA


A05 | | M_CLK SIM_IO

A04 | | | VPP C6




TX_A U X R X_A U X | 0C1-EUX Telit U1 P LE9 1

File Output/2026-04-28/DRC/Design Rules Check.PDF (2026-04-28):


Design Rules Verification Report







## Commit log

2026-01-23 Initial Update
    [3V8 Power Regulator.SchDoc, Assembly Testpoint Report for B101AA.csv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]
2026-02-26 pcb update
    [Assembly Testpoint Report for B101BA.csv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]
2026-03-24 docs: rewrite B101 README in English with board overview
2026-03-24 docs: add PCB render to B101 README
2026-03-24 docs: use provided board image in README
2026-03-27 design review update
    [B101BA_00.00.01_BOM.csv]
2026-04-28 review update
    [Assembly Testpoint Report for B101.csv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]
2026-04-28 2. review send update
    [B101CA_00.00.03_BOM.csv]
